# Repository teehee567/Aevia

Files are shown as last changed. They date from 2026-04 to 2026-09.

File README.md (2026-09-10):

# Aevia

Aevia is a DIY, battery powered lap timer and track data logger. The current hardware is the V2 Mini, a compact board that combines multi-band GNSS, a 6-axis IMU, local storage, a display interface, physical controls, and wireless connectivity.

Uses very very high end sensors, UM980, SCH16T-K01

The goal is to build something in the same general space as a Garmin Catalyst, but at a lower cost and with more control over the hardware, raw data, and software. Recorded data should also remain useful outside the device, with export to proper desktop analysis tools.

## V2 Mini hardware

The V2 Mini is built around:

- `ESP32-S31-WROOM-3-N16R16V` as the main processor and radio
- `UM980` multi-band, multi-constellation GNSS receiver
- `SCH16T-K01-1` 6-axis accelerometer and gyroscope
- microSD storage over 4-bit SDIO
- a 24-pin SPI display interface for the Adafruit 4520
- four UI buttons and four RGB status LEDs
- native USB data and USB-C power
- a 1-cell battery charger, fuel gauge, and push-button power control

See [v2_mini_design.md](./v2_mini_design.md) for the block diagrams, power tree, fitted parts, and current one-off build estimate.

## Firmware and software plan

The [base firmware](./firmware/README.md) now provides structured hardware
bring-up and a button-free J6 USB flash runner. From `firmware/`, run
`cargo run --release --locked` to build, flash and verify the restart.

The immediate work is hardware bring-up and the basic firmware needed to read the GNSS and IMU, store sessions on the microSD card, and exercise the display and controls. The application backlog currently looks like this.

### High priority

- [ ] Delta T lap timing with colour coding
- [ ] Raw-data analysis that can support lap times reported to 0.001 seconds and show the limits of the hardware
- [ ] Export to Harry's LapTimer or another tool that accepts the recorded data

### Medium priority

- [ ] G-G diagram, with filtering suitable for noisy IMU output
- [ ] Automatic track detection
  - [ ] Track learning mode
  - [ ] Manual start and finish line setup
- [ ] Smart battery management
- [ ] Theoretical best lap time
- [ ] Automatic recording based on acceleration
- [ ] Sector splits for tracks that support them

### Low priority

- [ ] Configurable LED bar
- [ ] Customisable gauges
- [ ] Colour themes

### Stretch ideas

- [ ] CAN bus or OBD data logging for brake, throttle, and other vehicle data
- [ ] Bluetooth support through the ESP32
  - [ ] RTK corrections, with a target of roughly 50 Hz and centimetre-level positioning
  - [ ] Firmware updates over Bluetooth
- [ ] Action camera synchronisation

## Why the UM980

Of the modules considered, the UM980 is the best fit I found for raw GNSS quality at this price. It can output at 20 Hz while using multiple GNSS constellations. That matters in a car because an antenna inside the windscreen loses much of its view behind the metal roof. Combining GPS, GLONASS, Galileo, and BeiDou leaves more satellites available for each fix and can improve accuracy when the view of the sky is limited. A receiver advertised as "multi-GNSS" does not necessarily support its maximum update rate while using several constellations at once.

It also supports multiple frequency bands. A single-band receiver has a harder time separating a direct signal from one reflected by the car or nearby barriers. Comparing L1 with L2 or L5 gives the receiver more information for rejecting poor measurements.

The planned BT-T076 is a wide multi-band active helical antenna, although its sheet does not explicitly document every UM980 signal. Helical designs generally tolerate tilt and an uncertain ground plane better than conventional patches, but the BT-T076 datasheet does not publish the angular, per-band patterns needed to rank it against a particular patch. A correctly integrated patch that covers every required band may provide cleaner measurements in a fixed installation; many common patches are only L1 or depend on a specific ground plane. See [the GNSS antenna decision note](./gnss_antenna_design.md) for the mounting scenarios, electrical constraints, expected data effects, and A/B test plan.

The expected gain over a decent off-the-shelf logger is not enormous, and software quality will matter just as much as the receiver. For absolute lap-time proof, a track transponder still wins.

### Receivers considered

These figures are working notes from the module research and should be checked again before buying parts.

| Receiver | Notes |
|---|---|
| Unicore `UM980` | L1, L2/L5, and L6; multi-constellation; full RTK; 20 Hz with full multi-GNSS; about 50 Hz in RTK mode; roughly A$130 |
| u-blox `NEO-M9N` | L1-only; multi-constellation; 25 Hz with one constellation or 10 Hz with several; roughly A$20 |
| u-blox `NEO-M10S` | L1-only; multi-constellation; 25 Hz with one constellation or 10 Hz with several; roughly A$20 |
| u-blox `ZED-F9P` | L1 and L2; multi-constellation; full RTK; about 8 Hz with everything enabled or 20 Hz with a reduced configuration; roughly A$130 |
| Quectel `LC29H-DA/EA` | L1 and L5; multi-constellation; RTK on the EA variant; 10 Hz maximum |
| Septentrio `mosaic-X5` | All bands and constellations; the best raw quality in this comparison; capable of 100 Hz; more than A$1,000 |
| SkyTraq `PX1122R` | L1 and L2; multi-constellation RTK; apparently up to 20 Hz, although documentation and pricing were difficult to find |

The Dragy Pro was the only off-the-shelf product for which I could identify the receiver module. It uses a u-blox NEO-M10S and is listed in the research as 10 Hz with multiple constellations or 20 Hz with one. I have not found a module that clearly delivers 25 Hz, multi-GNSS, and 10 cm accuracy at the same time, so similar product claims are unlikely to be real.

The longer comparison is in [data/gps_module_research.md](./data/gps_module_research.md).
And raw GNSS modules specs are in [data/GNSS_research.xlsx](./data/GNSS_research.xlsx).

## Repository map

- [V2 Mini design notes](./v2_mini_design.md)
- [GNSS helix-versus-patch and dashboard placement analysis](./gnss_antenna_design.md)
- [V2 Mini KiCad project](./hardware/v2_mini_pcb/v2_mini.kicad_pro)
- [V2 Mini root schematic](./hardware/v2_mini_pcb/v2_mini.kicad_sch)
- [V2 Mini PCB layout](./hardware/v2_mini_pcb/v2_mini.kicad_pcb)
- [V2 Mini production BOM](./hardware/v2_mini_pcb/production/digikey_bom.csv)
- [GNSS module research](./data/gps_module_research.md)
- [V1 PCB files](./hardware/v1_pcb/)
- [Earlier full-size V2 design notes](./v2_design.md)

## Building it

I do not recommend this as a first electronics build. Several parts need reflow equipment or a capable hot-air setup, and a one off board involves a fair amount of tooling and rework cost. The V2 Mini estimate is about $500AUD for the PCB, stencil, parts, GNSS receiver, antenna, and battery.

## V1 archive

archive, old, bad

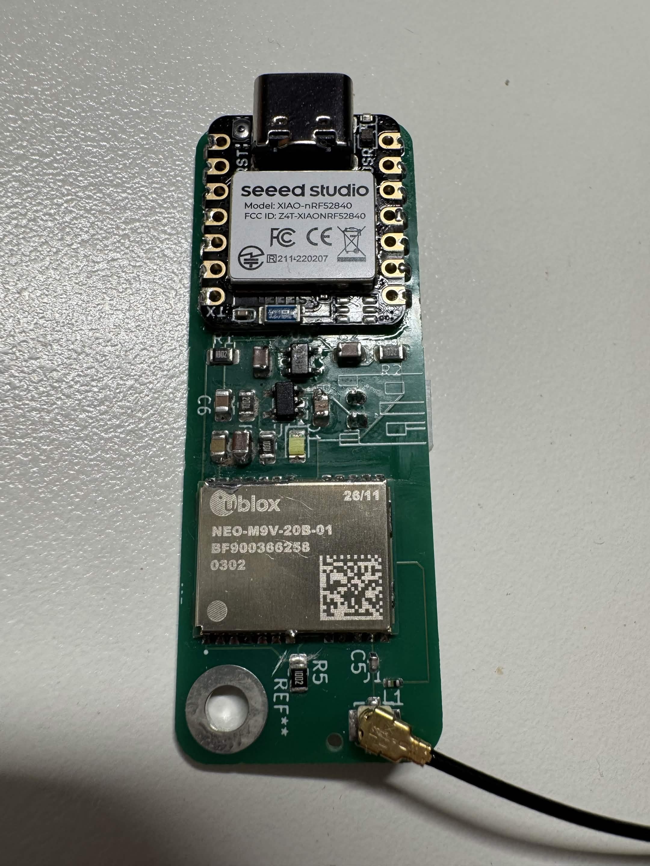
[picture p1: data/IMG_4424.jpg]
V1 assembled PCB


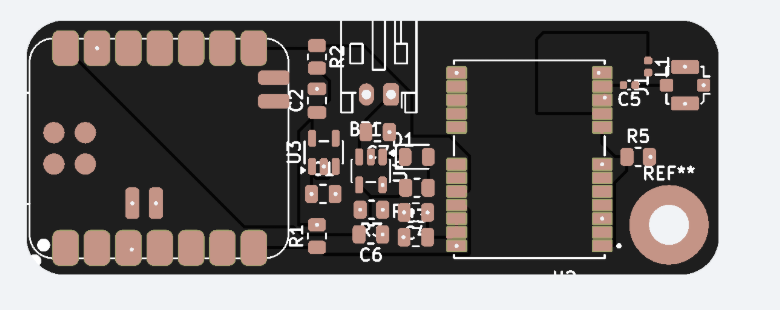
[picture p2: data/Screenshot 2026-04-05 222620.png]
V1 PCB design


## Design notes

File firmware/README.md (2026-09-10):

# V2 Mini base firmware

The default image brings up the ESP32-S31 V2 Mini's sensors, power bus,
buttons, display interface, PSRAM and USB console. Hardware ownership,
device protocols, background tasks and USB presentation are separate.
There is no trajectory engine or allocator in the base image.

## Build and flash

Use Rust **1.95.0**, target `riscv32imafc-unknown-none-elf`, and
**espflash 4.5.0**. The HAL revision and dependency graphs are pinned.
From `firmware/`:

```powershell
cargo build --release --locked
cargo run --release --locked
```

`cargo run` uses the Windows Cargo runner to flash over **J6**, without
BOOT/RESET button presses. From the repository root the equivalent is:

```powershell
powershell -NoProfile -ExecutionPolicy Bypass -File tools/flash-firmware.ps1
```

The script builds firmware and the host helper before touching the board.
The helper discovers the application (`303A:4001`), sends `BOOTLOADER`, waits
for ROM USB (`303A:0020`), flashes through the RAM stub, performs the S31
watchdog reset, then requires two advancing base-firmware status records.
It also accepts a board already in ROM download mode. The standalone helper
source lives in [tools/s31-reset](../tools/s31-reset); its original reset-only
command is retained.

Port numbers are discovered, not assumed. Optional `-AppPort COM5 -RomPort
COM4` arguments select known ports. Close other serial readers first and
connect only the board being flashed. J5 Serial/JTAG is a different transport.
Software entry requires responsive application USB; if both application and
ROM USB are absent, physical recovery is still necessary. A failed flash
leaves the board in download mode so the same command can be retried.

The ELF is `target/riscv32imafc-unknown-none-elf/release/aevia-firmware`
relative to the repository root.

## Source layout

| Location | Responsibility |
| --- | --- |
| `src/main.rs` | Entry point and image descriptor |
| `src/board.rs` | Frozen board pins, bus configuration, safe initial output levels |
| `src/app.rs` | Task composition and core ownership |
| `src/drivers/` | SCH16T, UM980, ST7789, LP5813 and TCA9536 I/O |
| `src/tasks/` | Sensor recovery, shared power-bus scheduling, shutdown and display lifecycle |
| `src/usb/` | USB descriptors, command dispatch, bounded writes and telemetry formatting |
| `src/state.rs` | Short snapshot locks and bounded capture queue |
| `src/lib.rs` | Host-testable command framing, GNSS/SafeSPI protocols, battery/button policies and memory checks |
| `experiments/` | Archived reference source; excluded from every base build |

See [system reference](docs/v2-mini-system-reference.md) for wiring, timing,
failure handling and extension constraints.

## USB console

Open the application COM port at 115200 with DTR enabled. USB sends a `STATUS`
line about once per second; sensor acquisition runs even with no host reader.
Status includes a protocol version, monotonic uptime, sensor counts, independent
GNSS fix validity, battery/LED/button state, LCD diagnostics, PSRAM test results
and cumulative capture/drop counters. `last-*-error` retains historical faults;
the current state and advancing error counters distinguish recovery from a
continuing fault. Battery readings expire after three seconds.

Commands are ASCII lines terminated with LF or CRLF. They work across USB
packet boundaries. Oversized or malformed lines are discarded; a bootloader
token embedded in another line cannot trigger a reset.

| Command | Result |
| --- | --- |
| `BOOTLOADER` | Immediately enter ROM download; independent of the telemetry writer |
| `STREAM 0123abcd` | Clear pending capture and reply `STREAM READY 0123abcd <time_us>`, then emit RAW records |
| `STOP` | Clear capture queue and acknowledge `STREAM STOPPED`; sensors/status keep running |
| `LCDREINIT` | Repeat panel initialization and DC check; SCLK probe requires reboot |
| `LCDTEST` | Enable the animated panel test pattern |
| `LCDLIGHT 0`, `1`, `5`, `10` | Backlight ceiling; 1/5 expire after five seconds, 10 stays on while panel initialization permits it |
| `GNSSBRIDGE` | Pause normal GNSS acquisition/configuration and bridge UM980 COM2 on the second USB serial interface |
| `GNSSNORMAL` | Restore COM2 baud and resume normal GNSS configuration/acquisition |

J6 now exposes two serial ports. Interface 0 is the console (currently COM5);
interface 2 is raw GNSS (currently COM6). The flash helper selects interface 0.
Bridge mode starts COM2 at 460800, 8N1 and follows the GNSS port's host baud
selection. It stays enabled across host disconnects until GNSSNORMAL or reboot.
Firmware telemetry and command parsing stay on the console port.

**Connected-board limitation:** receiver-to-host USB streaming is working;
direct receiver commands have not passed. GPIO49, assigned as COM2 RXD in the
schematic, was observed receiving COM2 output when released as an input.
COM1 replies on GPIO46 were absent. A wiring/assembly fault is suspected, not
confirmed. See [bridge findings and checks](docs/gnss-usb-bridge.md) before
treating this as a working two-way UPrecise connection.

Streaming is opt-in. Its nonce is exactly eight hexadecimal digits. A consumer
must discard bytes before its matching READY line. RAW formats are:

```text
RAW IMU <end_us> <interval_us> <ax> <ay> <az> <gx> <gy> <gz>
RAW GNSS <received_us> <original BESTNAVA line>
```

Acceleration is m/s², angular rate rad/s, timestamps MCU monotonic microseconds.
Frame lines across packets. The fixed 32-record queue drops new records on
overflow and increments `queue-drops`; producers never wait for USB. A blocked
writer has a 250 ms deadline and disables capture. Send a new STREAM request
to resume. This is a bring-up console, not a lossless recording transport.

## Verification

From the repository root:

```powershell
powershell -NoProfile -ExecutionPolicy Bypass -File tools/check-firmware-code.ps1
powershell -NoProfile -ExecutionPolicy Bypass -File tools/check-firmware.ps1
powershell -NoProfile -ExecutionPolicy Bypass -File tools/check-battery.ps1
powershell -NoProfile -ExecutionPolicy Bypass -File tools/check-psram.ps1
powershell -NoProfile -ExecutionPolicy Bypass -File tools/check-lcd.ps1
```

The code check runs host tests, strict Clippy for host and device, formatting
and the release build. The base hardware check requires a fresh stream
handshake, progressing GNSS/IMU counts, no new capture errors, the full 16 MiB
memory check and continued acquisition after STOP. Allow roughly 12 seconds
after power-on for receiver configuration before running it. Hardware checks
default to COM5 and accept `-Port`. A valid satellite fix and a working panel
are deliberately separate bring-up results.

Live verification on 2026-09-10 passed USB flashing and automatic restart from
both the former image and the rebuilt base image. After making power I2C
asynchronous, a 15-second check received 2,726 IMU intervals and 300 GNSS
records with zero capture errors and zero queue drops. The full 16 MiB PSRAM
test passed; the charger/gauge and green LED readback were valid; buttons
reported the unpressed mask. STOP preserved acquisition and status.

The connected LCD still reports `dc-stuck-low` (`lcd-dc=4`, expected 5).
Firmware leaves its backlight off and does not write frames into that fault.
Visible display output, physical button transitions, battery-only transitions,
SW7 shutdown and GNSS fixes need separate hardware checks. There was no
satellite fix during this run. GNSS timing is not PPS-disciplined and board
calibration is not implemented.

SD recording, wireless, lap timing and onboard fusion are future application
work. The old `host-poc`, `rtk-50hz`, and implicit onboard-estimator build modes
have been removed. Historical results remain in [trajectory notes](docs/trajectory-poc.md)
and [the preserved bring-up reference](docs/history/poc-system-reference.md).

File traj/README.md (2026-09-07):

# Aevia trajectory engine

`aevia-trajectory` is the shared trajectory and measurement engine for V2 Mini.
It has two processing paths:

- **Live:** bounded estimation on the S31 as measurements arrive. This is the
  default allocator-free, `no_std` build, selected by `ProcessingLevel::EmbeddedLive`.
- **Offline:** recorded-session replay and refinement on a computer or phone.
  Enable the `offline` Cargo feature and use `aevia_trajectory::offline`.
  `ProcessingLevel::OfflineSmooth` selects fixed-interval smoothing;
  `ProcessingLevel::CapturedReplay` reproduces the captured live processing.

Offline processing uses `OfflineResourceLimits` and returns an `OfflineRun`
with an `OfflineRunSummary`.

This directory contains only the core engine. Sensor drivers, protocol decoding,
clock/counter reconstruction, calibration application, channel selection,
resampling, recording codecs and physical I/O belong to external callers. The
former acquisition and log crates have been removed; nothing has been moved into
firmware.

The source is organized by responsibility. The public module paths remain the
entry points; their private submodules hold the implementations:

- `config/`: installation and calibration, numeric and navigation profiles,
  resource limits, qualification, and live/offline processing specifications.
- `engine/`: live session construction and ingestion, clock transitions,
  initialization, frontier processing, result digests, and offline/replay orchestration.
- `metric/`: definitions and plans, numerical algorithms, distance/event queries,
  uncertainty, and incremental activity, lap, and drag tracking.
- `trajectory/`: dense interpolation, conditional covariance bridges, storage and
  record encoding, public queries, and metric root/derivative calculations.
- `offline/solver/`: evidence validation, filter initialization and updates,
  propagation, smoothing, uncertainty projection, and result publication.
- `live/core/` and `live/eskf/`: live scheduling and ingestion, navigation
  propagation, GNSS updates, bounded extended RTS smoothing, and covariance handling.

Regression tests live beside these responsibilities in separate test modules.
The host feature suite can be run with
`RUST_MIN_STACK=33554432 cargo test -p aevia-trajectory --features offline,raw-tight,gtsam-system`;
its fixed-capacity replay fixtures need a larger test-thread stack than Rust's
default. Test `gtsam-vendored` separately because the two GTSAM features are
mutually exclusive.

The engine accepts:

- `ImuObservation`: a calibrated angular-rate vector in rad/s and specific-force
  vector in m/s², both averaged over the same nonzero interval in the declared
  IMU measurement frame. Supply their effective timestamps, clock-model identity,
  sample support, full covariance (or a configured model), axis validity and
  generic `ImuStatus`. The constructor rejects misaligned vectors. Any channel
  substitution, range/temperature qualification and covariance adjustment must
  already be complete. `Degraded` is usable, `Unavailable` invokes gap handling,
  and `Initializing`/`Discontinuity` require navigation reinitialization.
- `GnssSolutionObservation`: prepared ECEF position and/or velocity with their
  own timestamps, frame/reference-point identities, uncertainty, optional cross
  covariance and explicit per-field `valid` flags. Invalid fields remain
  recordable and are excluded from fusion and initialization. Positioning mode
  (RTK fixed/float, PPP, standalone, etc.) is not an engine input; the caller
  supplies the appropriate uncertainty and receiver health/freshness diagnostics.
  The caller accounts for receiver latency in each field's effective timestamp.
  Velocity-method labels, DOP and satellite/signal counts belong in application
  diagnostics. No receiver message format is required.
- Configuration: input-rate limits (`InputProfileSpec`), installation rotation
  and antenna lever arm, residual calibration uncertainty, clock uncertainty,
  process/measurement noise and metric definitions. A supplied heading is
  optional; observability remains explicit when heading is unknown.

The Kalman filter, IMU integration, IMU–GNSS fusion, frame/lever-arm mathematics,
bias estimation, covariance propagation, live trajectory and metrics, and
computer-side smoothing remain inside this package. Outputs include continuous
position, velocity and orientation queries at a chosen reference point, supported
uncertainty, quality/provenance, derived metrics and typed unavailable results.
Offline callers supply prepared records through `EvidenceSource` and consume
results through `ResultSink`; these are semantic ports with no file-format
requirement. Frame transforms and timing validation are estimator mathematics,
not hardware input processing.

GNSS output quality reports `Healthy`, `Absent` or `Suspect`, independent of
positioning mode. Migrating callers must replace `solution_class` with `valid`
and remove the `rtk_state` constructor argument. Keep any desired receiver mode
labels in application diagnostics. Offline record readers map legacy accepted
mode tags to `Healthy`; new records use a distinct health tag, which older
readers reject rather than misreport as RTK fixed.
Captured-result digests also use the new tag: replay comparisons against old
mode-labelled output digests will differ and require regenerated captures.

Measurement covariance describes the uncertainty of the supplied interval
average, not a continuous noise density. Preserve shared clock/calibration
uncertainty separately instead of adding it independently to every sample.
Nonzero independent IMU timestamp jitter currently remains unfused in live processing and returns
`CapabilityUnavailable` in the offline solver. Neither implementation has the
required temporal sensitivity model. Do not conceal real jitter by setting it
to zero. Shared clock offset/drift uncertainty remains supported.

Offline smoothing retains the error of each interval-average IMU sample across
stored propagation edges, including observations inside its support. Dense
covariance carries navigation, calibration, bias and sample correlations into
interior and offset-point queries and metric uncertainty. Offset velocity
covariance uses finite-support angular-rate uncertainty; the returned
`angular_rate_uncertainty_support` identifies that averaging interval. It does
not assign an instantaneous variance to white gyro noise.

Gate survey uncertainty is explicit: exact, independent normal displacement,
or a shared three-dimensional survey parameter with navigation correlations.
A variance supplied without a correlation model remains unavailable for
correlated metric uncertainty. Offline missing support still needs explicit
reinitialization; unsupported uncertainty models continue to fail closed.

`FiniteGate::new` keeps its scalar-variance argument. Declare its correlation
model with `with_independent_survey()` or `with_shared_survey_parameter(id)`;
direct field access now uses `survey_uncertainty: GateSurveyUncertainty`.
The private offline trajectory record format is version 4 to retain the full
coupled process; resource preflight includes its larger records and bounded cache.

Live navigation uses the ESKF forward estimate plus an extended RTS backward
pass over a fixed 64-node window. Set `NavigationProfileSpec.smoothing_lag` to a
nonzero duration up to 100 ms to enable smoothing; zero retains the forward
comparison path. The lag is additional to `fusion_delay`. Present projections
continue to follow the forward predictor, while trajectory publication and
metric watermarks wait for smoothed endpoints. `finish()` flushes the shorter
remaining window through the last trusted IMU epoch. The backward pass preserves
the filter's fixed Schmidt calibration/clock means and covariances, including
shared IMU-sample and gap correlations; it does not perform nonlinear iteration
or jointly estimate the calibration parameters.

Moving startup needs two fresh, advancing GNSS position/velocity epochs and
valid current IMU support. It can start without a stillness prerequisite,
using a coarse tilt estimate and calibrated bias priors. Repeated or merely
extrapolated receiver epochs do not count as another fix. A supplied heading
remains optional; course over ground is not treated as body heading.
The existing stationary alignment path remains available.

The release firmware target is the `ESP32-S31-WROOM-3-N16R16V`. It runs the
bounded, fixed-capacity live ESKF/RTS and incremental metric path. Full-session
`f64` smoothing runs on a phone or workstation. `AdvancedGraph` and `RawTight`
remain reserved processing levels and return `CapabilityUnavailable`.
The `gtsam-system`, `gtsam-vendored`, and `raw-tight` Cargo features remain for
compatibility and enable `offline`; they do not provide a backend. The unused
private backend scaffolding has been removed.

The smoother uses the explicit `LiveResourceLimits::V2_MINI_RTS` development
contract with a 3 MiB PSRAM ceiling; the historical `V2_MINI_INITIAL` constant
retains its 1 MiB ceiling. Internal SRAM and stack ceilings remain 192 KiB and
32 KiB. Callers must supply the reported compiled workspace sizes and record
the new navigation profile/digest. New output timing and startup behavior
require captures from the new build for exact replay. See
[`live_smoothing_requirements.md`](../data/live_smoothing_requirements.md) for
the lifecycle, moving-start and qualification requirements.

The allocator-free core is cross-checked with
`riscv32imafc-unknown-none-elf`, the hardware-FPU target class used by the
ESP32-S31. That check does not replace the release firmware proof: the platform
adapter must statically place the two workspaces in internal SRAM and PSRAM,
pin the floating-point estimator task to an explicit high-performance core,
keep capture ISRs integer-only, and qualify the final ESP-IDF/ESP-HAL link map,
stack, timing, cache contention, and soak behavior on the fitted module.
Run `python3 traj/scripts/audit_s31_firmware_purity.py` from the repository root
for the repeatable generic-target dependency and linked-symbol gate.

`WorkQuota` is a nonzero corrected-frontier credit capped at `u16::MAX` per
call. It charges IMU-slice planning, propagation, delayed measurement updates,
RTS backward steps, and frontier/segment commits; it is not a whole-step
wall-clock budget.
Observation ingestion, bounded corrected-history transfer/reanchoring, metric
refresh, and present projection instead have compile-time capacity and loop
bounds. Their timing, together with interrupts, RTOS overhead, cache behavior,
and final-link effects, remains an exact-firmware hardware release gate.

Non-polynomial gate, speed-threshold, and speed-extremum roots use
`EnclosureNativeF64V1`: outward binary64 interval arithmetic through the full
rigid-point, noncommuting SO(3) bridge, and Bowring ellipsoid-normal expression
graphs. Pinned `fpmath` native elementary functions are expanded beyond their
documented error bounds. The production dependency closure is allocator-free;
software scalar adapters are test-only. Isolation retains fixed stack, depth,
root-count, and evaluation ceilings and fails closed on unresolved cells.
The native contract requires round-to-nearest, gradual underflow, and disabled
implicit contraction. Independent Decimal90 regression fixtures cover values
and derivatives; regenerate them with
`python3 traj/scripts/generate_root_enclosure_oracle.py`.

Live preflight still requires measured qualification for this exact backend,
numeric profile, target, toolchain, input envelope, MPFR and independent-oracle
corpora, target bit fixtures, zero oracle escapes, and resource ceilings.
Legacy Taylor-backend attestations cannot qualify the new graph. The host
regressions are not hardware or MPFR qualification evidence.

Distance absolute tolerance belongs to the complete measurement. Segments and
speed-sign subdivisions share that allowance by duration, and cumulative live
reports retain the error already consumed. Relative error is checked against
the complete reported distance, including cancellation in signed quantities;
exceeding the shared numerical-work budget remains a typed failure.

The public interface contains semantic observations, configuration, trajectory
queries, measurements, quality and provenance. Estimator state, matrices,
storage machinery and optional native backends remain private.

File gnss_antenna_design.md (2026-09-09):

# Aevia GNSS antenna decision: quadrifilar helix versus patch

- **Status:** design and validation note
- **Date:** 2026-08-17
- **Applies to:** Aevia V2 Mini, UM980, an antenna mounted inside the front windscreen
- **Decision confidence:** high on the installation principles; deliberately conditional on the exact replacement patch, windscreen construction, and measured vehicle geometry

**Hardware assumption:** the user reports that the installed antenna is helical, while the repository only identifies the BT-T076 as the *planned* helix. BT-specific values and connector conclusions in this note apply only if the label and datasheet revision confirm that the installed assembly is an authentic BT-T076. The current V2 Mini BOM does not identify an antenna or pigtail.

## Decision in one page

There is no topology-only answer in which every patch is better than every helix, or vice versa. For Aevia, orientation and installation can be worth substantially more than the small difference between two headline peak-gain numbers.

There are two different decisions: what is safe to deploy now, and which configuration has the highest ceiling after qualification. The recommended order is:

1. **Best absolute result:** a documented, full-band active GNSS antenna mounted externally near the centre of the metal roof, using the ground plane and mounting method required by its manufacturer.
2. **Safe interior baseline now:** retain the installed helix and test it first with its axis vertical. It needs no newly engineered patch plane and is the lower-risk choice while the exact patch, vehicle mask, and installed helix identity remain unknown.
3. **Highest-potential interior prototype:** a high-quality active patch that covers every signal Aevia intends to use, on the exact ground plane or integrated base for which it was characterised. Start with its face horizontal, then test 15°, 30°, and the measured glass-normal angle. Horizontal is the conventional patch baseline, but a forward tilt can win if it aligns the lobe with the car's actual clear windscreen aperture. It must accept the V2 Mini's 3.3 V bias and be compatible with the UM980 manual's stated 18–36 dB *optimum input-gain* window after the gain reference is clarified with Unicore.
4. **Do not choose from topology or tilt alone:** a large glass-normal tilt is risky for a directional patch because it sacrifices other sky sectors, but it is not automatically wrong. The installed antenna-plus-vehicle pattern, not the free-space antenna pattern alone, decides the result.

For the two requested comparisons:

| Installation | Helix | Patch | Decision today |
|---|---|---|---|
| Front of dash; boresight normal to the windscreen | Its broader angular response makes it the lower-risk unmeasured choice at a large tilt. It still points away from zenith and its installed pattern is unknown. | It may lose zenith/side/rear gain, or it may benefit by concentrating gain into the only clean forward-glass aperture. Glass-normal mounting does **not** reduce glass loss for a fixed satellite ray. | **Keep the helix as the safe baseline; no guaranteed RF winner.** Test this patch orientation rather than rejecting it if the forward aperture dominates. |
| Same dash location; boresight straight up | Good, robust baseline when a defined patch plane cannot be supplied. It may admit more reflected energy and may have less direct-signal gain than a properly installed quality patch. | Conventional baseline geometry. A high-quality patch on its specified plane is the preferred upgrade candidate for cleaner code/carrier and more stable phase-centre behaviour. | **Keep the helix now; select the patch only if installed tests show a downstream data-quality win.** |

The conditional language is intentional. The exact improvement cannot be stated from the present component data. The BT-T076 sheet gives one generic `3 dBi` gain number and `≤3 dB` axial ratio, but no gain or axial-ratio plots by frequency and direction. No replacement patch has been selected, and the windscreen rake and coating are unknown. A switch based only on advertised peak gain would therefore be guesswork.

## 1. What is actually in Aevia

The [V2 Mini design note](./v2_mini_design.md), schematic/PCB and README identify the current receiver as the **Unicore UM980** and the planned antenna as the **Beitian BT-T076**. The current V2 Mini has a U.FL antenna connector, an RF path designed and routed as a short 50 Ω connection, and a 3.3 V bias tee that is energised whenever the GNSS rail is powered. There is no production RF-impedance measurement in the repository. The current firmware is only a scaffold (`Hello, world!`), so there is not yet any Aevia observation log with which to compare antennas.

The [UM980 product page](https://en.unicorecomm.com/products/um980/) and the [R1.9 user manual stored in this repository](./data/datasheets/UM980_User%20Manual_EN_R1.9.pdf) specify reception of:

- GPS L1 C/A, L1C, L2P(Y), L2C and L5;
- BeiDou B1I, B2I, B3I, B1C, B2a and B2b;
- GLONASS G1, G2 and G3;
- Galileo E1, E5a, E5b and E6;
- QZSS L1 C/A, L1C, L2C, L5 and L6; and
- NavIC L5.

The manual gives 1.5 m horizontal and 2.5 m vertical RMS standalone positioning, 0.8 cm + 1 ppm horizontal and 1.5 cm + 1 ppm vertical RTK, 0.03 m/s velocity RMS, and up to 50 Hz RTK in a specific mode. It does not establish that all constellations, raw observations, and diagnostics can be output together at 50 Hz. Those are receiver test figures, not promises for a windscreen installation. Unicore explicitly makes performance dependent on satellite visibility and geometry, multipath, and antenna quality. Its table calls **18 dB minimum, 30 dB typical, and 36 dB maximum** the *optimum input gain*; it does not define those figures as absolute operating or damage limits.

The [BT-T076 manufacturer's page and datasheet images](https://www.beitian.com/en/sys-pd/620.html), revision 5.53 dated 2024-12, claim:

| Item | BT-T076 published value |
|---|---|
| Bands | GPS L1/L2/L5; GLONASS L1/L2; Galileo E1/E5a/E5b; BeiDou B1/B2/B3; QZSS L1/L2/L5/L6; NavIC L5; SBAS L1/L5. Galileo E6 and GLONASS G3 are not explicitly listed. E6 is close in frequency to QZSS L6, but coverage, group delay and performance must not be inferred from frequency overlap alone. |
| Polarisation | RHCP |
| Passive antenna gain | `3 dBi` (one value; no band, angle, reference plane, or uncertainty stated) |
| Axial ratio | `≤3 dB` (no angle or band stated) |
| VSWR | `≤2` |
| LNA gain / noise figure | `32 ±2 dB` / `≤2 dB` |
| Supply / current | 3.3–5.0 V / ≤55 mA |
| Phase-centre error | ±2 mm claimed |
| Connector and size | SMA-J; 43.5 mm diameter × 40.8 mm; ≤35 g |
| Missing information | 3-D RHCP and LHCP patterns; gain and axial ratio versus elevation/azimuth and band; mounting/ground-plane test condition; filter rejection and linearity; unit-to-unit tolerance by band |

This is enough to regard the BT-T076 as a plausible low-cost active wide-band helix. It is not enough to claim support or characterised performance for every UM980 signal, model installed signal quality, or prove the README's previous claim that it has lower peak gain but better low-elevation coverage than a patch. That pattern claim is a reasonable generic tendency, not a verified BT-T076 comparison.

## 2. Definitions that prevent an orientation mistake

- A **patch face** is its broad radiating ceramic/metal face. Its intended boresight is the line normal to that face. A horizontal face points vertically upward.
- A **helix axis** is the long symmetry axis through the quadrifilar helix. For this note, that axis is treated as its nominal boresight.
- Let **α** be the boresight tilt away from local vertical, toward the front of the vehicle. `α = 0°` means straight up. A windscreen-normal installation has `α` equal to the angle between the inward/outward windscreen normal and vertical; this must be measured on the actual car.
- “The helix lies flat on the dash and points up” means its base/support is on the dash and its **axis is vertical**. If the cylindrical helix is literally placed on its side, its axis is horizontal; that is a different and generally poor configuration.

For a satellite at elevation `e` and azimuth offset `φ` from the vehicle's forward direction, the off-boresight angle `θ` is

```text
cos(θ) = sin(e) cos(α) + cos(e) sin(α) cos(φ)
```

This simple geometry explains the difference between the two proposed installations. With `α = 0°`, `θ = 90° − e` for every azimuth: a nominally symmetric antenna is insensitive to yaw. With an illustrative, not assumed, windscreen-normal tilt of `α = 60°`:

| Satellite direction | Off-boresight angle `θ` |
|---|---:|
| 30° elevation, directly ahead | 0° |
| 30° elevation, directly to the side | 75.5° |
| 30° elevation, directly behind | 120° (behind the antenna) |
| Zenith | 60° |

At this illustrative 60° tilt, the antenna boresight favours one forward sector and places zenith, side, and rear directions far off-axis. That geometric fact does not supply the missing dB pattern, nor does it prove that the directions are usable or blocked in the car. As the car turns, the antenna lobe and the vehicle's forward-glass aperture rotate together while the satellites remain in Earth-referenced directions. Alignment between those two patterns can improve or worsen the combined result.

It is useful to separate two effects. A tilted directional antenna introduces **free-space antenna yaw sensitivity**; a horizontal, azimuth-symmetric antenna does not. But every **installed antenna-plus-vehicle pattern** is heading-dependent because the roof, pillars, glass aperture/coating, occupants and reflections also rotate relative to the satellites. A horizontal patch is only nominally yaw-symmetric before those vehicle effects. Heading-dependent C/N0 must therefore be measured, not assigned from orientation alone.

Measure `α` directly rather than relying on an ambiguous “windscreen rake” number. For example, glass described as 30° back from vertical has a normal about 60° from vertical, matching the table above. If the proposed bracket is actually only 30° from vertical, zenith is only 30° off-axis and the penalty is much milder; the same forward/rear and heading trade remains.

At `α = 30°`, a satellite at 45° elevation directly ahead is only 15° off-boresight rather than 45° for a vertical boresight, and one at 20° elevation ahead is 40° rather than 70°. The corresponding rear directions become worse. That may be a good exchange if the roof has already blocked the rear sky and the forward glass is the clean aperture; only the candidate's pattern and the installed sky mask can convert these angles into a dB or data-quality answer.

One further distinction is essential: **tilting an antenna at the same location changes the antenna pattern seen by the satellite; it does not change the physical satellite ray or that ray's angle through the glass.** Glass incidence is set by the satellite direction and windscreen plane. Pointing a patch or helix normal to the glass can align its boresight with a forward ray, but it does not make every ray traverse less glass or evade a metallic coating.

## 3. Why patch and helix behave differently

### 3.1 Radiation pattern and useful gain

GNSS satellites transmit right-hand circularly polarised (RHCP) signals. An antenna's useful figure is therefore not total LNA gain or a single peak dBi number. It is installed **RHCP realised gain as a function of frequency, elevation, and azimuth**, including mismatch and material losses.

A conventional patch concentrates response in the hemisphere above its face. It normally has maximum RHCP gain near its normal and rolls off toward the plane/horizon, with a ground-plane-dependent back lobe. ESA's [Navipedia antenna reference](https://gssc.esa.int/navipedia/index.php?title=Antennas) describes typical patch coverage of about 160° and notes that real GNSS antennas can lose roughly 10–20 dB from zenith to the horizon while axial ratio also deteriorates off-axis. These are generic orders of magnitude, not a prediction for an unspecified Aevia patch.

A quadrifilar helix is commonly designed for a smoother hemispherical response and is more tolerant of varying orientation. It is not isotropic, and “360° horizontal coverage” does not define its elevation pattern. The [u-blox GNSS antenna integration note](https://content.u-blox.com/sites/default/files/products/documents/GNSS-Antennas_AppNote_%28UBX-15030289%29.pdf) says that a reasonably sized helix will typically have less sensitivity than a comparably practical patch because comparable direct gain needs comparable aperture. The same note cautions that a helix can report more satellites in a difficult environment because its broad pattern also accepts reflections; those extra observations can have distorted ranges and worsen navigation.

Consequences for Aevia:

- A flat, properly integrated patch tends to maximise direct high-elevation signals and suppress energy from below or behind. This is attractive for low-multipath code, carrier phase, and RTK.
- A helix tends to give up some concentration for angular tolerance. This is attractive when the mount is tilted, the device rolls/pitches substantially, or no stable patch ground plane exists.
- More tracked satellites is not by itself a win. Fourteen clean, well-distributed direct signals can outperform twenty signals that include strong reflected paths.
- Small vehicle pitch and roll are usually far less severe than a 50–65° windscreen-normal tilt. They remain worth logging, but neither those motions nor free-space geometry alone determines the best installed angle.

### 3.2 Polarisation and axial ratio

An ideal GNSS antenna receives RHCP direct signals and rejects opposite-hand energy. A spec called **axial ratio (AR)** measures how close the polarisation is to circular: 0 dB is ideal; 3 dB is only the usual edge of a broad “circular” classification. Reflections can partially or fully reverse handedness, so low AR and low LHCP gain help reject multipath.

For an idealised elliptically polarised antenna at one direction, let `r = 10^(AR/20)`. Its ideal co-polar to cross-polar discrimination is

```text
XPD = 20 log10((r + 1) / (r − 1))
```

Thus 3 dB AR corresponds to about 15.3 dB ideal RHCP/LHCP discrimination, 1 dB to about 24.8 dB, and 0.5 dB to about 30.8 dB. The direct-signal mismatch at 3 dB AR is only about 0.13 dB; the larger concern is poorer rejection of the wrong handedness. These calculations are ideal values at a specified angle. A datasheet's one zenith AR number says little about the horizon, other bands, or the installed vehicle.

The BT-T076's `≤3 dB` claim is therefore adequate but not survey-grade evidence. A good replacement patch or helix should provide AR and RHCP/LHCP patterns over angle and frequency, not merely a checkbox saying RHCP.

### 3.3 Ground plane, phase centre, and nearby material

Patch performance depends on its RF ground plane. The u-blox integration note shows that ground-plane size, shape, symmetry, and patch placement can change gain, axial ratio, impedance match, resonance, directivity, and the back lobe. It gives 50 × 50 to 70 × 70 mm as a useful generic allowance for common L1 patches, but that is not a universal full-band prescription. Full-band stacked patches can require a larger, candidate-specific plane; for example, the representative Taoglas part discussed below is characterised on a 150 mm diameter plane.

A plastic dashboard above the vehicle's metalwork is **not automatically the documented RF ground plane**. Distance, electrical bonding, shape, and nearby displays/PCB/cables all matter. A random steel plate can also make a patch worse if its dimensions differ from the design condition. Follow the selected antenna's drawing and verify the installed match/pattern.

Helices are often designed without a ground plane, but this too is part-specific. u-blox reports that an intentional plane can improve some helix implementations by 2–3 dB, while metal within roughly 5 mm of a free-space helix's radiating section can distort its near field and pattern. The BT-T076 sheet does not state its test condition, so neither adding nor removing metal should be assumed beneficial.

Nearby glass, a radome, adhesive, the dash, display, PCB, cable, a person's hand, and vehicle metal change the near field. This can shift resonance and alter both the far-field pattern and phase centre. There is no reliable correction from dimensions alone; the choices are electromagnetic simulation and installed measurement.

For standalone metre-level use, a few millimetres of phase-centre variation may be unimportant. For RTK and IMU fusion, it matters. The antenna must also be rigidly mounted and its lever arm to the vehicle/IMU reference point measured. Body roll rotates that lever arm, and an unmodelled position offset can appear as a trajectory error even when the receiver solution itself is good.

## 4. The two requested mounting scenarios

### Scenario A: both boresights normal to the windscreen

Assumption: the helix axis and patch normal point outward perpendicular to the glass at the same front-dash location. The patch face is therefore approximately parallel to the glass. A fair orientation comparison must keep the antenna phase-centre xyz position, cable route, ground plane/base, enclosure and nearby hardware fixed as far as mechanically possible; moving them changes masking and multipath independently of angle.

**Helix:** This is a use case in which the topology's usually broader pattern is valuable. Compared with a conventional directional patch at the same large `α`, a well-designed helix may retain more usable gain toward zenith, side sectors, and some rearward directions. The price can be lower direct-signal gain and greater acceptance of dashboard, bonnet, glass, barrier, and ground reflections. There is no BT-T076 angular data or selected-patch pattern to say which is ahead, or whether the difference is 1 dB or 10 dB, in any particular direction.

**Patch:** This is the riskier unmeasured orientation when `α` is large. The forward low/mid-elevation sector may be strong, but zenith is `α` degrees off-axis, satellites beside the car are far off-axis, and much of the rear sky can enter through the patch's weak back hemisphere. On the other hand, the roof may already obscure the rear sky, so concentrating gain into the forward glass can be beneficial. The direction and magnitude of the trade depend on the installed sky mask, beamwidth, off-axis axial ratio, and the satellite geometry around the complete route.

There is one important exception: if an installed sky-mask survey shows that nearly all clean, usable sky is through a narrow forward windscreen sector while zenith and the sides are already blocked, aiming a directional patch into that aperture can outperform a vertical patch for those rays. It still must beat the vertical and intermediate-angle configurations over complete laps, because the favoured satellite azimuth changes with vehicle heading.

An automotive L1 experiment by Aloi et al., [“A detailed experimental study on the benefits of electrically grounding glass mounted GPS antennas to the vehicle roof”](https://doi.org/10.1049/iet-map.2013.0616), measured a 25 × 25 × 4 mm patch on a vehicle-roof mock-up at 45°, 60°, and 75° windscreen angles. It found that the roof distance, grounding arrangement, glass loading, and tilt all changed patterns; the roof-centre reference had about 5 dBc peak gain. The reported differences included roughly 1.5 dB trends from tilt and about 2.5 dB at some median pattern points from roof proximity/grounding. This is direct evidence that vehicle installation can move results by several dB, but it is **not transferable as a correction**: it was a tuned L1-only patch near the roofline, not an unspecified full-band patch on Aevia's lower dash.

**Verdict:** if constrained to a large glass-normal tilt before any measurement, the helix is the lower-risk baseline because it is less dependent on a newly designed plane and is likely broader. That is an integration-risk recommendation, not proof of better RF data. Sweep `α = 0°, 15°, 30°`, and the measured glass-normal angle for both complete assemblies. A modest or full forward cant may win if it matches the real aperture; it must demonstrate that win over complete laps and multiple satellite geometries.

### Scenario B: both boresights straight up from the dash

Assumption: patch face horizontal; helix axis vertical; the same phase-centre position, cable route and surrounding hardware as far as the different assemblies permit.

**Helix:** This puts its intended main region on the sky and removes deliberate free-space forward/rear asymmetry. It is the safest configuration for the existing antenna when no validated patch assembly is available. Its broad lower-elevation response may retain signals through the front and side glass, but can also accept more reflected energy. The installed vehicle pattern remains heading-dependent.

**Patch:** This is the correct baseline orientation for a conventional GNSS patch. If it covers all required bands, uses a good dual-feed RHCP design, and sits on its specified plane, it may provide stronger/cleaner high-elevation observations and better rejection of below-plane multipath than the current undocumented helix. That could help raw code and phase quality, ambiguity continuity, and repeatability. A high-quality helix can still outperform a mediocre patch, and a bare patch sitting on plastic with the wrong plane can be detuned enough to erase or reverse the expected advantage.

**Verdict:** a documented quality patch is the preferred upgrade candidate for raw-observation purity and RTK in this scenario, **not a guaranteed winner**. Until a specific patch passes the electrical and installed tests below, the current vertical helix is the lower-risk deployment choice.

### Scenario comparison

| Consideration | Tilted helix | Tilted patch | Vertical helix | Horizontal-face patch |
|---|---|---|---|---|
| High-elevation/zenith use | Conditional; zenith off-axis | Usually poor at large `α` | Intended geometry | Intended geometry; often strongest |
| Forward low-elevation sky | Favoured | Strongly favoured | Off-axis but usually usable | Off-axis; often downweighted anyway |
| Rear/side sky | Often smoother than a directional patch; unknown here | Can be weak/backside | Free-space azimuth balance is plausible | Free-space azimuth balance if the plane is symmetric |
| Added antenna-pattern yaw sensitivity | Moderate at a large tilt | Potentially high | Low if its free-space pattern is symmetric | Low if antenna/plane are symmetric; vehicle yaw effects remain |
| Multipath rejection | Candidate-specific; broad response can admit more | Directional, but useful alignment is installation-specific | Candidate-specific; broad response can admit more | Potentially best with a proper plane and low off-axis AR |
| Need for defined ground plane | Often lower, part-specific | High | Often lower, part-specific | High |
| RTK/raw phase potential | Must be measured | Must be measured against the aperture | Plausible baseline | Highest conventional-patch potential, still candidate-specific |
| Recommendation | Lower-risk of the unmeasured large-tilt choices | Test if it aligns with the real aperture | Keep as deployment baseline | Preferred upgrade candidate to qualify |

## 5. “How much better?” — what can and cannot be quantified

A 3 dB change is a factor of two in received power. In a stable, unsaturated front end, a 3 dB change in installed passive antenna gain or pre-LNA loss will appear approximately as a 3 dB-Hz C/N0 change for that ray. It does **not** mean twice the position accuracy. Position error depends on geometry, correlation/noise, multipath bias, receiver weighting, frequency availability, and whether tracking or RTK ambiguity thresholds are crossed.

For scale, the following is the *best-case thermal-noise-only* interpretation. The last column is the ideal measurement standard-deviation multiplier if every other error source is unchanged; real GNSS positioning often improves less because multipath, satellite geometry, atmosphere, phase-centre variation, and receiver weighting dominate.

| C/N0 improvement | Carrier/noise power ratio | Ideal noise-limited standard deviation |
|---:|---:|---:|
| 1 dB | 1.26× | 0.89×, about 11% lower |
| 2 dB | 1.58× | 0.79×, about 21% lower |
| 3 dB | 2.00× | 0.71×, about 29% lower |
| 6 dB | 3.98× | 0.50×, about 50% lower |

The following published magnitudes set the scale; they are examples from different antennas and test setups, not transferable Aevia prediction bounds:

| Mechanism/evidence | Magnitude | Meaning and limit |
|---|---:|---|
| Generic real GNSS antenna roll-off, zenith to horizon | about 10–20 dB | [ESA's reference](https://gssc.esa.int/navipedia/index.php?title=Antennas) gives this as a common range. A large tilt can move a satellite across much of that pattern, but no BT/candidate plot means no installed prediction. |
| Ground plane added to some helix designs | about +2–3 dB | Generic u-blox integration example, not a BT-T076 guarantee; a too-close/wrong plane can degrade it. |
| Experimental L1 windscreen patch installation changes | order 1.5–2.5 dB in reported comparisons | Aloi et al.; specific antenna, roof distance, tilt, and grounding. Shows “several dB” installation sensitivity, not a reusable Aevia number. |
| Ordinary 6–19 mm architectural glass examples at GPS L1 | about 1–4 dB | Broad literature examples summarised by [Liu et al.](https://link.springer.com/article/10.1186/s43020-020-00013-z), not direct measurements in Aevia or an automotive-windscreen specification; laminate, angle, frequency and setup differ. |
| Coated/energy-efficient glass examples | about 10–30 dB | Broad literature examples summarised by Liu et al., with construction and setup varying. They show that conductive coating can dominate; measure the actual vehicle. |
| 34 mm high-speed-train glazing experiment | up to 20 dB-Hz loss in surviving signals; 65% fewer tracked satellites | [Liu et al.](https://link.springer.com/article/10.1186/s43020-020-00013-z) also observed many more cycle slips and metre-level PPP degradation. This is a severe-glass case, **not a car prediction**. |
| Survey-grade patch versus two quality multi-frequency QHAs, 10–30° elevation | QHA code noise/multipath RMS about 30% and 70% higher; phase/high-frequency multipath about 40% and 70% higher | [Wanninger et al.](https://doi.org/10.1515/jag-2021-0042), static survey setup. It demonstrates that antenna quality changes observables, not that BT will match either QHA. |
| Same survey study, 5-minute fast-static coordinates | horizontal accuracy broadly similar/sub-centimetre; vertical RMS 0.80/0.93 cm patch, 1.02/1.51 cm one QHA, 2.08/2.50 cm the other | Raw observables can be 30–70% noisier while final horizontal results remain similar; vertical worsened about 1.3–2.7× in those tests. Dynamic windscreen results may differ completely. |

The most important conclusion from these examples is scale: headline peak differences between plausible candidate datasheets may be only a few dB, while orientation, an incorrect patch ground plane, a deep pattern null, or metallised glass can cost ten or more dB in affected rays. Those large effects can decide lock and ambiguity continuity; a one-number “3 dBi versus 4 dBi” comparison cannot.

One representative full-band active patch makes the comparison problem visible. The [Taoglas ADFGP.60A datasheet](https://www.taoglas.com/datasheets/ADFGP.60A.01.0150D.pdf) reports, on a 150 mm diameter ground plane, passive peak gain from approximately −0.3 dBi at L6/E6 to 4.4 dBi at L1, axial ratio roughly 0.25–1.25 dB by band, and total gain about 26–30 dB. This wide per-band variation shows why a patch cannot be represented by one peak-gain number. The BT sheet's single undifferentiated `3 dBi` claim has no band-specific value, angular definition, or stated test plane, so no numerical BT-versus-Taoglas subtraction is valid.

Likewise, a well-documented helix can be much better characterised than the current one. The [Calian HC990XF datasheet](https://sites.calian.com/app/uploads/sites/13/2024/06/Calian%C2%AE-HC990XF-Datasheet-Rev.-202304.pdf) specifies band-by-band gain around 1.8–2.3 dBic, ≤0.5 dB zenith AR, ±3 mm phase-centre variation, filtering, and no ground-plane requirement. Its lower headline gain than BT's generic 3 dBi does not make it lower quality. Pattern, polarisation purity, filtering, phase stability, and test disclosure matter.

## 6. How the antenna changes Aevia's result data

The antenna can improve the measurements available to the UM980; it cannot change the receiver's nominal update rate, correct bad timestamps, or make three decimal places in a lap time accurate by itself.

The causal chain is:

```text
installed antenna gain / polarisation / multipath / interference
        ↓
per-signal C/N0, tracking continuity, code and carrier residuals
        ↓
usable bands and satellites, geometry, cycle slips, RTK ambiguity state
        ↓
position and velocity error, solution availability and latency
        ↓
virtual-line crossing time and lap/sector repeatability
```

### Observable-level effects

- **C/N0:** better installed passive gain and lower pre-LNA loss raise C/N0 approximately dB-for-dB until receiver compression/interference effects intervene. More LNA gain alone amplifies signal and antenna noise together; it cannot recover SNR lost before the LNA.
- **Pseudorange/code:** stronger direct signals reduce thermal/code tracking jitter, while reflected signals introduce biased ranges that do not average like white noise. A broad helix can therefore show more satellites yet worse code residuals.
- **Carrier phase and lock:** good C/N0 and favourable tracking-loop/interference conditions reduce thermal phase noise and loss of lock. A low-quality signal can cycle-slip; RTK then has to repair or re-resolve ambiguities, creating fixed-to-float transitions and discontinuities.
- **Phase centre:** offset and variation create direction-, attitude-, frequency-, and mounting-dependent systematic phase/position bias. Stable, characterised phase-centre behaviour helps RTK consistency and lever-arm calibration, but it does not directly prevent cycle slips.
- **Multi-frequency availability:** an L1-only or weak-L5/L6 patch throws away part of the UM980's central advantage. The replacement must be evaluated per signal and per band.
- **Geometry:** a tilted directional pattern can eliminate useful side/rear/high-elevation signals, worsen DOP, and make quality vary with heading. Satellite count alone does not capture this.
- **Interference:** a high-gain but poorly filtered active antenna can overload its own LNA or the receiver near cellular, Wi-Fi, display, USB, SD, and switch-mode noise. The u-blox note explains that GNSS power is below the thermal-noise floor and that both in-band noise and strong out-of-band transmitters can drive receiver AGC/desensitisation.

### Position error to lap-time error

For a virtual timing line with unit normal `n`, position error `δr`, and vehicle velocity `v`, the first-order crossing-time error is

```text
δt_position ≈ (n · δr) / (n · v)
```

For a timing line approximately perpendicular to the racing line, this reduces to along-track position error divided by speed. Illustrative values are:

| Speed | 1.0 m along-track error | 0.10 m | 0.01 m | Distance travelled in 1 ms |
|---:|---:|---:|---:|---:|
| 60 km/h | 60 ms | 6.0 ms | 0.60 ms | 1.67 cm |
| 100 km/h | 36 ms | 3.6 ms | 0.36 ms | 2.78 cm |
| 200 km/h | 18 ms | 1.8 ms | 0.18 ms | 5.56 cm |

This is only the spatial term. Total lap-crossing error also includes GNSS time/message latency, PPS alignment, receiver dynamics, sample interpolation, start-line definition, antenna/IMU lever arm, body attitude, filtering, and software. At 20 Hz, epochs are 50 ms apart; interpolation can remove raw sample quantisation, but only if timestamps, velocity/trajectory modelling, and adjacent fixes are reliable. Reporting `0.001 s` is not evidence of 1 ms accuracy. At 100 km/h, 1 ms alone corresponds to just 2.8 cm along the track, considerably below the UM980's nominal standalone RMS and plausible only with a stable high-quality solution plus careful timing/processing.

A better antenna will most visibly improve **availability and tails**, not necessarily the average lap: fewer C/N0 collapses, fewer discarded signals and cycle slips, longer RTK-fixed intervals, smaller 95th/99th-percentile position excursions, and less heading-correlated lap-to-lap error. A patch could yield cleaner raw data yet similar final horizontal positions, as the Wanninger study illustrates. Conversely, crossing a tracking or RTK threshold can produce a step change much larger than the dB improvement suggests.

## 7. Antenna assembly types are not interchangeable

“Patch” can mean several electrically different products:

1. **Bare passive ceramic patch.** This is only the radiating element, perhaps with matching. It normally needs a carefully designed host ground plane, a short 50 Ω feed, matching/ESD work, and often a nearby LNA. Cable loss before the first LNA directly degrades system noise figure. It is not a plug-in substitute for an active SMA antenna.
2. **Active patch module.** This adds an LNA and usually filtering. It may have a small metal backplate but can still require a larger specified external ground plane. “Active” does not mean “ground-plane independent.” Read the characterisation condition.
3. **Active patch with an integrated, sufficient ground plane/base.** A larger enclosed assembly can control its own RF geometry. This is the most plausible interior patch upgrade if it is explicitly characterised freestanding or with its supplied plane.
4. **Roof-intended magnetic puck.** Its magnetic metal base and the vehicle roof may be part of the RF design. A puck specified “on a 100 mm ground plane” or “vehicle roof mount” should not be assumed to work the same on a plastic dashboard. A product explicitly specified ground-plane independent is different.
5. **Survey/geodetic antenna.** These often use stacked dual-feed patches, choke structures, stable phase centres, strong filtering, a large enclosure, and calibration. They can give the cleanest phase data but may be too large, expensive, or roof-dependent for Aevia.

Whenever `+3V3_GNSS` is powered, that rail feeds the U.FL centre conductor through a 68 nH inductor. It is the same filtered rail that powers the UM980. The existing 100 pF capacitor blocks DC only between the biased RF node and the UM980 `ANT_IN` pin; it does **not** remove DC from U.FL J1. The UM980 `ANT_DETECT`, `ANT_OFF`, `ANT_SHORT_N`, and `VCC_RF` pins are unconnected, so the present PCB has no firmware-controlled antenna enable, open/short indication, or antenna-current measurement. The UM980 manual recommends a separately protected `ANT_BIAS` supply for robustness, whereas V2 Mini shares the receiver rail.

A passive patch is therefore not automatically drop-in. Verify its DC input before connection: a candidate that is a DC short could pull down the shared GNSS rail through the bias inductor. If it is incompatible, depopulate the bias-feed inductor or add a deliberate DC block/bias-isolation or switching design. An active candidate must operate at the voltage that actually reaches it under load. If the installed helix is confirmed as a BT-T076, its stated 3.3–5.0 V range puts V2 Mini at its lower limit; measure voltage and current externally at the antenna end across battery, temperature, cable, and tolerance rather than accepting the rail label.

Keep three gain questions separate for an active assembly:

- **Satellite link and C/N0:** installed passive RHCP realised gain versus band and direction, plus pre-LNA loss and polarisation/multipath effects.
- **Noise figure and receiver drive:** antenna-LNA/filter gain and noise figure, followed by cable/adapter loss. Evaluate this with the Friis noise relationship and the actual component reference planes.
- **Interference headroom:** filtering, LNA and receiver compression, IP3/intermodulation, AGC and nearby in-/out-of-band emitters. GNSS satellite power itself is not the likely overload source.

The UM980 manual states an 18–36 dB *optimum input-gain* range but does not clearly say whether `G_ant` means the LNA/filter/cable chain alone or total directional active realised gain including the passive element. Therefore the BT-T076's `3 dBi` element claim must **not** simply be added to its `32 ±2 dB` LNA claim and compared with 36 dB as though that were a hard limit. Confirm Unicore's definition and each vendor's reference plane, then verify the complete chain with installed measurements. Observe AGC/jamming diagnostics if the UM980 protocol and selected firmware expose them.

V2 Mini uses U.FL, while the standard BT-T076 datasheet specifies SMA-J. If that is the installed antenna, the assembly needs a controlled U.FL-to-SMA pigtail; no pigtail type, length, loss, or accessory line is defined in the current Mini BOM. A different helical termination changes or removes that requirement. Keep any pigtail short and mechanically strain-relieved. An active antenna's LNA before the cable makes post-LNA cable loss much less damaging to system noise figure than the same loss before an LNA, but loss still lowers receiver input level and margin; adapters also add variation and failure points.

## 8. Windscreen, vehicle, and placement effects

### Glass

Ordinary uncoated glass costs a few dB in some reported non-automotive tests, but heat-reflective, athermic, IR, or metallised layers can dominate the entire link budget. u-blox warns that reception through a metallic-coated windscreen may be impossible and notes that some cars provide a small RF-transparent region, often near the mirror. The high-speed-train study cited above is a useful severe-case demonstration, not an automotive estimate.

Before choosing an antenna:

- check the vehicle manual and glass markings for athermic/heat-reflective/metallised treatment;
- identify any OEM toll-tag/GNSS transparent zone;
- avoid embedded conductive heater/defroster wires, camera/radar modules, and metallic tint;
- measure attenuation by matched inside/outside C/N0 tests per band and direction.

Changing antenna tilt at one position does not bypass coating. Moving the antenna to an RF window or outside does.

### Body masking and multipath

The roof, pillars, firewall, bonnet, and occupants block or reflect different sky sectors. A dashboard antenna does not see a clean half-sphere. An illustrative Rohde & Schwarz [GNSS vehicle obscuration/multipath test note](https://cdn.rohde-schwarz.com/pws/dl_downloads/dl_application/application_notes/1gp101/1GP101_1E_Obscuration_and_Multipath_GNSS_Receiver_Testing.pdf) uses different attenuation masks for windows, roof, and body panels precisely because position within a vehicle changes the RF mask; its sample dB values are a simulation model, not Aevia measurements.

Prefer the highest, most central clear location that does not interfere with airbags or sight lines. Keep the antenna away from the display, ESP32/Wi-Fi antenna, USB, SD clocking, switch-mode inductors, and long digital cables. The vehicle roof is usually the best combination of sky view, symmetry, and ground plane; the front dash is a compromise.

The bonnet, dash, glass, barriers, grandstands, other vehicles, and track surface all create multipath. A quality horizontal patch and ground plane can suppress below-plane energy. A helix's broader pattern preserves angular coverage but can accept more of it. Low-elevation satellites already travel through more atmosphere and encounter more multipath; retaining every one is not automatically worth degrading the observation set. Receiver elevation/C/N0/residual weighting remains important for either antenna.

### Dynamic installation tolerance

- A symmetric vertical antenna adds little intrinsic free-space yaw dependence; a tilted lobe adds more. The installed vehicle pattern is heading-dependent in both cases, so explicitly test every vehicle heading.
- Pitch, roll, vibration, and hills perturb `α`. A helix normally degrades more gently; a patch must have sufficient beamwidth around every intended installed angle.
- A few centimetres of mount movement can change a reflection phase by a large fraction of a GNSS wavelength. Use a rigid, repeatable fixture.
- Adhesive thickness, radome, cable routing, and metal plates are RF design variables. Freeze them with the antenna choice.
- If the installed helix is confirmed as BT-T076, its stated upper operating temperature is +70 °C. Confirm the actual sun-loaded dash thermal requirement; do not assume cabin air temperature represents the antenna enclosure.

## 9. What “antenna quality” should mean in procurement

Quality matters least in open sky when all candidate assemblies give strong C/N0, uninterrupted multi-band tracking, and a standalone metre-level solution. In that regime the receiver and software may hide modest observable differences. It matters most when the link has little margin, the vehicle creates strong reflections, carrier phase/RTK is used, nearby transmitters or digital electronics threaten overload, temperatures vary, or results must repeat across units and remounts. These are exactly the conditions in which low axial ratio, stable phase centre, filtering/linearity, documented patterns, and manufacturing tolerance are more important than a peak-gain claim.

Do not rank candidates by total active gain or price alone. Require, in priority order:

1. **Exact frequency coverage:** every UM980 signal Aevia intends to log, especially L1/E1/B1, L2, L5/E5, B2/B3, and L6/E6. Many inexpensive “multi-band” patches are only L1+L5 or L1+L2.
2. **Installed RHCP realised-gain patterns:** by band, at least versus elevation in orthogonal azimuth cuts; 3-D data are better. Require the mounting plane and cable reference.
3. **Axial ratio and LHCP rejection versus angle and band:** zenith-only AR is insufficient for windscreen multipath.
4. **Ground-plane and installation definition:** dimensions, symmetry, required bonding, clearances, radome and cable position. Prefer a supplied/integrated plane if an interior custom plane is impractical.
5. **LNA chain:** gain tolerance, noise figure, input/output match, 3.3 V operation and current, gain flatness, group delay, compression/IP3, and stability.
6. **Filtering:** in-band insertion characteristics and out-of-band rejection around cellular, Wi-Fi, and Aevia's digital/switching emissions. Strong gain without linearity/filtering can be worse.
7. **Phase behaviour:** phase-centre offset/variation by band, group-delay variation, and calibration availability. This becomes decisive for RTK and GNSS/IMU fusion.
8. **Environmental and production quality:** operating/storage temperature, humidity, vibration, connector strain, ESD, ingress if external, lot tolerance, traceability, and repeatability after remounting.
9. **Complete interface fit:** connector, cable type/length/loss by frequency, bias voltage/current, dimensions, mass, and mounting repeatability.

Peak passive gain mostly tells what happens in one direction under one test condition. A lower-peak antenna with low AR, smooth phase centre, good horizon coverage, strong filtering, and honest plots can produce better data than a higher-number part.

## 10. Required A/B test before changing the design

Because installation uncertainty is larger than the likely component margin, the decision should be experimental. Test the **complete assemblies**, not loose radiator elements.

### 10.1 Test matrix

At minimum:

| ID | Antenna | Orientation |
|---|---|---|
| H0 | installed helix complete assembly (BT-T076 only if confirmed) | axis vertical (`α = 0°`) |
| HW | same installed helix assembly | axis normal to measured windscreen |
| P0 | selected required-band active patch plus specified plane/base | face horizontal (`α = 0°`) |
| PW | same patch assembly | face parallel to / normal pointing through windscreen |

Add `α = 15°` and `30°` forward for both if fixture time permits. Include a documented external roof antenna as the reference. Test any passive bare patch only after making the bias interface safe and defining its LNA/ground plane.

### 10.2 Control the experiment

- Same UM980 hardware, firmware, constellations, frequencies, tracking/elevation masks, update rate, dynamic model, correction source, and output messages.
- Same antenna position to within a documented tolerance, with the same cable path and known cable/adapter loss. Record antenna serial number and complete assembly revision.
- Same windscreen and vehicle state. Record rake angle, antenna `α`, xyz position, ground plane dimensions, coating/tint, nearby devices, and whether heater/camera electronics are active.
- For simultaneous comparison, use two identical receivers and swap antennas between receiver channels halfway through to remove receiver bias. Keep antennas separated enough to avoid coupling while exposing nearly the same sky. If only one receiver exists, repeat tests and compare matched satellite/signal/elevation/azimuth bins rather than raw averages from different sky geometry.
- Static open-sky baseline first, then stationary inside-car test, slow 360° heading rotation in an open area, and repeated dynamic laps. Repeat on multiple satellite geometries and in both open and barrier-heavy portions of a circuit.
- Do not judge from one screenshot, time-to-first-fix, or satellite count.

### 10.3 Firmware/logging required

The current Rust firmware does not yet read or log GNSS. First obtain the UM980 commands/logs reference and confirm which fields the installed receiver firmware can output; the bundled user manual confirms NMEA and Unicore formats but not every diagnostic below. Before antenna qualification, record all available required fields without UART/SD drops:

- raw code/pseudorange, carrier phase, Doppler, lock time and loss-of-lock/cycle-slip flags for every constellation, satellite, signal and frequency;
- per-signal C/N0, used/rejected state, satellite azimuth/elevation, and tracking status;
- solution time, position, velocity, DOP/covariance or estimated accuracy, satellite counts, fix type, and RTK state (none/single/float/fixed);
- RTK correction age, baseline/solution status, ambiguity resets, time to first fixed solution, and fraction of time fixed;
- receiver AGC and interference/jamming diagnostics if the protocol and firmware expose them;
- PPS edge captured against a hardware timer, the corresponding GNSS time message, UART receive time, message latency, buffer overruns, SD write stalls, and firmware configuration;
- synchronised SCH16T IMU samples and its time mapping to PPS/GNSS epochs;
- session metadata: antenna type/serial, cable, adapter, externally measured supply voltage/current at the antenna, location, `α`, ground plane, vehicle, windscreen/coating, weather, track direction and software revisions.

The current PCB cannot report antenna open/short/current state through the UM980 because `ANT_DETECT`, `ANT_OFF`, `ANT_SHORT_N`, and `VCC_RF` are unconnected; that requires external instrumentation or a hardware revision. Confirm that UART bitrate and storage throughput can carry the selected raw multi-frequency messages at 20 Hz. Treat 50 Hz as a separate feasibility test: the manual permits up to 50 Hz RTK only in a specific mode and does not promise every raw signal and diagnostic simultaneously. An antenna comparison is invalid if the logger silently discards epochs differently.

### 10.4 Metrics

Compare by constellation, signal/band, 10° elevation bin, and forward/side/rear azimuth sector:

- median, 10th percentile, and distribution of C/N0 for common signals;
- C/N0 versus vehicle heading for individual satellites, revealing tilted-pattern yaw dependence;
- fraction of possible observations logged and fraction used in the solution;
- code-minus-carrier/multipath combinations, pseudorange and carrier residual RMS/tails;
- loss-of-lock and cycle slips per 1,000 observations;
- DOP and geometry after receiver weighting/rejection;
- RTK time to fix, fixed percentage, fix outages/resets, and float/fixed transition count;
- stationary horizontal/vertical scatter and relative dynamic position/velocity differences against the roof comparator;
- 50th/95th/99th-percentile absolute errors only against independent truth such as a calibrated high-grade survey GNSS/INS with a surveyed base, an optical system, or an appropriate track reference;
- lap-line crossing residual and lap/sector repeatability against a track transponder or independently surveyed/time-synchronised reference.

As a useful health check rather than a pass/fail spec, the u-blox note says a well-designed system commonly shows about 44–50 dB-Hz on strong high-elevation signals and about 47 dB-Hz with a standard active antenna. Receiver reporting conventions differ, so Aevia should compare **delta C/N0 on matched signals** and failure-tail metrics rather than impose u-blox's absolute value on UM980.

### 10.5 Measure total in-cabin installation penalty

Use two matched antenna/receiver chains, one immediately inside and one on an unobstructed external/roof comparator, then swap chains. Map C/N0 difference by band, elevation, azimuth and heading. This measures the **combined** effect of glass, different antenna location, roof ground plane, body masking, pattern and multipath; swapping removes receiver-chain bias but does not isolate those mechanisms. A single average will hide a coating or pillar that affects only one sector/band. True glass-only attenuation needs controlled glass/no-glass measurements with otherwise matched geometry, or a representative windscreen coupon in a suitable RF setup.

### 10.6 Pre-register the decision rule

Choose the primary outcome before examining candidate results—for example, RTK-fixed availability plus 95th-percentile lap-line crossing error if RTK timing is the target, or 95th-percentile standalone along-track error and velocity continuity otherwise. First repeat the H0 baseline, including remounting, over multiple satellite geometries and both track directions to measure normal test variability. A candidate wins only if its repeated/crossover confidence interval clears both that baseline variability and a pre-agreed practically meaningful improvement in the primary outcome.

Use matched-signal C/N0, cycle slips, residuals and satellite counts to explain the result, not to replace it. A repeatable 2–3 dB improvement across the actually visible sky is meaningful link margin, but there is no universal dB threshold that guarantees a better position or lap time. Do not select a candidate whose median improves while its outage rate, heading dependence or 95th/99th-percentile errors worsen.

## 11. Final decision matrix

These labels are design priors, not measured rankings.

| Need / condition | Vertical installed helix | Quality required-band patch, horizontal on specified plane | Windscreen-normal helix | Windscreen-normal conventional patch |
|---|---|---|---|---|
| Integration risk today | **Favoured baseline**; assembly already exists | **Unqualified** until part, plane, bias and pattern are defined | Orientation unqualified | Assembly and orientation unqualified |
| Free-space high-elevation response | Candidate-specific; geometry is conventional | **Promising candidate**, pattern-specific | Zenith is off-axis | Zenith is off-axis, potentially strongly at large `α` |
| Match to a forward-only clear aperture | Broad response may cover it | Main lobe not centred on it | Broad response aimed toward it | **Potentially favoured** if its lobe actually matches that aperture |
| Ground-plane dependency | Usually lower, but part-specific | High; exact plane/base required | Usually lower, but part-specific | High; exact plane/base and installed tilt required |
| Multipath and phase quality | BT/current part undocumented | Potentially strongest with good AR, PCV and back-lobe control | Current part undocumented | Could screen cabin reflections, but off-axis AR and geometry may worsen |
| Heading behaviour in vehicle | Little intrinsic yaw asymmetry; vehicle effect remains | Little intrinsic yaw asymmetry; vehicle effect remains | Adds antenna tilt asymmetry to vehicle effect | Adds the strongest directional tilt, which may align with or oppose vehicle aperture |
| Role in the test | **Deployment baseline H0** | **Preferred upgrade candidate P0** | Required comparison HW | Required comparison PW when forward aperture may matter |

Recommended decision:

- **Immediately:** keep the installed helix as the baseline, confirm whether it is actually the BT-T076, mount its axis vertically for H0, verify the 3.3 V bias under load, and complete the appropriate controlled cable/pigtail and logging path.
- **Prototype in parallel:** obtain one active patch assembly that covers every signal Aevia will use, with a defined or integrated ground plane, 3.3 V operation, vendor-confirmed receiver gain compatibility, good AR/pattern/filter data, and stable phase centre. Start horizontal, then test intermediate and measured glass-normal angles.
- **Do not select the patch because of peak gain alone.** Select it only if the four-way installed test improves common-signal C/N0/residuals, cycle-slip tails, RTK fixed availability, and lap-line repeatability without heading-dependent outages.
- **If the actual windscreen is metallised or the interior loses roughly 10 dB or more in important sectors/bands:** treat this as a provisional engineering trigger to stop optimising topology inside. Use the OEM RF-transparent aperture or move the antenna outside to the roof.
- **If Aevia's primary goal remains standalone lap timing rather than RTK:** the improvement may be modest in average horizontal position and much larger in bad-case consistency. The current helix mounted vertically may already be sufficient; spend engineering effort on PPS-aligned timestamps, interpolation, lever-arm calibration, IMU fusion, and validation against a transponder as well as on the antenna.

## 12. Open facts required for a release decision

1. Exact installed helix make, model, revision, connector and cable; confirmation whether it is the planned BT-T076.
2. Exact vehicle model, windscreen rake, construction/coating, and available RF-transparent area.
3. Exact antenna xyz location, permitted size, and whether an external roof cable is acceptable.
4. Exact replacement patch part number and whether it is bare, active, integrated-plane, or roof-puck construction.
5. Candidate per-band patterns, AR, PCV, ground-plane requirement, filter/linearity, 3.3 V current, cable and connector data.
6. Measured V2 Mini bias voltage/current and complete-chain gain/loss; confirmation of UM980 gain interpretation.
7. Installed VNA/return-loss result where accessible and the four-way GNSS observation test.
8. Whether release mode is standalone, correction-aided/DGNSS, RTK float, or RTK fixed; the optimum acceptance metric changes with it.

Until those are known, the honest conclusion is not “helix is X% better” or “patch is X metres better.” It is: **the current helix mounted vertically is the safest first baseline, not a proven optimum; a correctly integrated quality patch has the highest conventional-patch ceiling for clean RTK-capable data, but its best angle may be horizontal, intermediate, or glass-normal depending on the installed aperture; and glass/body effects can overwhelm both.**

## References

- Aevia, [V2 Mini design note](./v2_mini_design.md), [PCB design](./hardware/v2_mini_pcb/v2_mini.kicad_pcb), and [production BOM](./hardware/v2_mini_pcb/production/digikey_bom.csv), used for the fitted RF/bias architecture and current hardware status.
- Unicore Communications, [UM980 product page](https://en.unicorecomm.com/products/um980/) and [UM980 User Manual R1.9](./data/datasheets/UM980_User%20Manual_EN_R1.9.pdf).
- Beitian, [BT-T076 official product page and datasheet images](https://www.beitian.com/en/sys-pd/620.html), rev. 5.53.
- u-blox, [*GNSS antennas: RF design considerations for u-blox GNSS receivers*](https://content.u-blox.com/sites/default/files/products/documents/GNSS-Antennas_AppNote_%28UBX-15030289%29.pdf), UBX-15030289 R03.
- European Space Agency Navipedia, [*Antennas*](https://gssc.esa.int/navipedia/index.php?title=Antennas).
- L. Wanninger, M. Thiemig and V. Frevert, [*Multi-frequency quadrifilar helix antennas for cm-accurate GNSS positioning*](https://doi.org/10.1515/jag-2021-0042), Journal of Applied Geodesy 16(1), 2022.
- D. N. Aloi et al., [*A detailed experimental study on the benefits of electrically grounding glass mounted global positioning system antennas to the vehicle roof*](https://doi.org/10.1049/iet-map.2013.0616), IET Microwaves, Antennas & Propagation 8(11), 2014.
- Z. Liu, Y. Gong and L. Zhou, [*Impact of China's high speed train window glass on GNSS signals and positioning performance*](https://link.springer.com/article/10.1186/s43020-020-00013-z), Satellite Navigation 1:14, 2020.
- Taoglas, [ADFGP.60A all-band active patch datasheet](https://www.taoglas.com/datasheets/ADFGP.60A.01.0150D.pdf), used only as a representative full-band patch, not a selected component.
- Calian, [HC990XF full-band quadrifilar helix datasheet](https://sites.calian.com/app/uploads/sites/13/2024/06/Calian%C2%AE-HC990XF-Datasheet-Rev.-202304.pdf), used only as a quality/characterisation benchmark.
- Rohde & Schwarz, [*Obscuration and multipath simulation for GNSS receiver testing*](https://cdn.rohde-schwarz.com/pws/dl_downloads/dl_application/application_notes/1gp101/1GP101_1E_Obscuration_and_Multipath_GNSS_Receiver_Testing.pdf), used only to illustrate vehicle-dependent RF masking.

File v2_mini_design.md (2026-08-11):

# Open Race V2 Mini

V2 Mini is a battery-powered GNSS and motion board built around the ESP32-S31 module. It has microSD storage, a display interface, physical controls, and native USB. Use the KiCad project and production BOM for build details. This page leaves out pin allocations, routing, and most passive components.

## High-level design

```mermaid
flowchart LR
    MCU["ESP32-S31-WROOM-3<br/>main processor and radio"]
    GNSS["UM980 GNSS<br/>U.FL antenna"]
    IMU["SCH16T-K01-1<br/>6-axis IMU"]
    SD["microSD<br/>4-bit SDIO"]
    LCD["Adafruit 4520 display<br/>24-pin SPI FPC interface"]
    UI["Four UI buttons and four RGB LEDs<br/>TCA9536 + LP5813"]
    USB["USB-C<br/>power and native USB data"]
    PM["Power management<br/>charger, fuel gauge and on/off control"]

    MCU <-->|"Two UARTs, PPS and status"| GNSS
    MCU <-->|"SPI, data-ready and reset"| IMU
    MCU <-->|"4-bit SDIO"| SD
    MCU -->|"Display and backlight control"| LCD
    MCU <-->|"Shared I2C control bus"| UI
    MCU <-->|"I2C and status signals"| PM
    MCU <--> USB
```

The ESP32 module handles processing, radio, and the board's main interfaces. The UM980 sends GNSS data over two UARTs and also has PPS, reset, and status connections. The SCH16T uses a separate SPI bus with data-ready and reset signals.

The microSD socket uses 4-bit SDIO. The selected display is the Adafruit 4520, connected through the 24-pin FPC with a MOSFET-switched backlight. The display panel itself is not a fitted PCB BOM item.

Four user buttons connect through the TCA9536 GPIO expander, and the LP5813 drives four RGB LEDs. Reset and boot/user connect directly to the ESP32. The power button connects to the MAX16169. The charger, fuel gauge, LED driver, and GPIO expander share the board's I2C control bus.

USB-C provides 5 V input and native USB data. The TPD4EUSB30 protects D+, D-, CC1, and CC2. The board also senses VBUS and both CC lines.

## Power tree

```mermaid
flowchart TD
    USB["USB-C J6<br/>5 V VBUS"] --> CHG["BQ25622 U8<br/>1-cell charger and NVDC power path"]
    BAT["1-cell battery J4"] <--> CHG
    BAT --> GAUGE["MAX17048 U9<br/>fuel gauge"]
    CHG --> RAW["3V3_RAW<br/>BQ25622 SYS rail"]

    RAW --> CTRL["MAX16169 U7<br/>power-button controller"]
    BUTTON["Power button SW7"] --> CTRL
    RAW --> REG["TPS63802 U10<br/>3.3 V buck-boost"]
    CTRL -->|"GATE_EN"| REG

    REG --> V33["+3V3"]
    V33 --> CORE["ESP32, microSD, display and user interface"]
    V33 --> FB1["FB1"] --> VGNSS["+3V3_GNSS"] --> GNSS["UM980 and antenna bias"]
    V33 --> FB2["FB2"] --> VIMU["+3V3_IMU"] --> IMU["SCH16T"]
```

The schematic name `3V3_RAW` refers to the BQ25622 SYS rail. The TPS63802 turns it into the regulated `+3V3` system rail. FB1 and FB2 provide filtered supplies for the GNSS receiver and IMU.

The MAX16169 runs from the raw rail and controls the TPS63802 enable input. SW7 connects to its pushbutton input. Its interrupt output goes to the ESP32, and the ESP32 has a separate shutdown control back to it. The MAX17048 measures battery state of charge, while the BQ25622 handles charging and reports power-path status. TH1 is a fitted 10 kOhm NTC in the charger temperature-sense network.

The board expects a 1-cell battery with the matching 2-pin Hirose DF58 connection for J4. The PCB-side connector is `DF58-2P-1.2V(21)`.

## Main fitted parts

The part numbers below come from the production BOM rather than the shortened values shown on some schematic symbols.

| Ref | Ordered part | Purpose |
|---|---|---|
| U2 | `ESP32-S31-WROOM-3-N16R16V` | Main processor and wireless module |
| U1 | `UM980` | GNSS receiver |
| U3 | `SCH16T-K01-1` | 6-axis accelerometer and gyroscope |
| U4 | `LP5813ADRRR` | I2C RGB LED driver |
| U5 | `TCA9536ADTMR` | GPIO expander for the four UI buttons |
| U6 | `TPD4EUSB30DQAR` | USB data and CC ESD protection |
| U7 | `MAX16169AALTA+T` | Power-button and regulator-enable control |
| U8 | `BQ25622ERYKR` | 1-cell charger and NVDC power path |
| U9 | `MAX17048G+T10` | Battery fuel gauge |
| U10 | `TPS63802DLAR` | 3.3 V buck-boost regulator |
| D32-D35 | `MSL0402RGBU1` | Four RGB indicators |
| SW1-SW7 | `B3U-1000P` | Reset, boot/user, four UI buttons, and power |
| TH1 | `NCU18XH103F60RB` | 10 kOhm charger temperature sensor |
| J1 | `U.FL-R-SMT-1(01)` | GNSS antenna connector |
| J2 | `GTFP08441BEU` | microSD socket |
| J3 | `SFV24R-2STE1HLF` | 24-pin FPC connector for the Adafruit 4520 display |
| J4 | `DF58-2P-1.2V(21)` | 1-cell battery connector |
| J6 | `USB4105-GF-A` | USB-C connector |

## Hardware source files

- [Root schematic](pcb/v2_mini_pcb/v2_mini.kicad_sch)
- [PCB layout](pcb/v2_mini_pcb/v2_mini.kicad_pcb)
- [Production BOM](pcb/v2_mini_pcb/production/digikey_bom.csv)
- [BOM exclusions](pcb/v2_mini_pcb/production/bom_exclusions.csv)

# Total production cost for single person for everything - tools

- Board + stencil - 142.30AUD with 50 coupon
- digikey - 200AUD
- gnss module - 120AUD
- antenna - 37AUD
- battery - 15AUD
total: ~500AUD

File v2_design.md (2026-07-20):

goal is to make a garmin catalyst2 but cheaper + better. Custom pcb better performance custom softare, still exporting to proper desktop tooling.

build pcb with this layout:
ESP+Power | Digital+STM+RAM | GNSS+IMU
left to right, have a cm or 2 between digital sensitive to reduce signal interference

check this pcb to see if bga is possible
https://www.st.com/en/evaluation-tools/stm32h7s78-dk.html#cad-resources

v2 pcb
    - Needs to support
    - move to STM32N657X0H3Q
    - clocks:
        - HSE: NDK NX2016SA-24MHZ-EXS00A-CS10820
        - LSE: NDK NX2012SA-32.768KHZ-EXS00A-MU00527
    - flash (boot/code only, XIP — N6 is flashless, do NOT log data here):
        - MX66UW1G45GXDI00 - original octo spi, switch to cheaper quad spi flash under.
        - MX25U51279GXDR00
    - data storage (telemetry log, separate from boot flash):
        - microSD card via socket (Hirose DM3CS-SF), 3.3V, SDIO/SPI
    - external RAM for STM32N6
        - AP Memory APS512XXN-OB9-BG OPI/HPI PSRAM, 1.8V
        - verify the exact x16 ballout and repair the current VSS/data-pin net error before powering it
    - much faster battery charging, at least 1C
        - must have usb pd 
        - AP33772S pd controller, i2c
        - battery is 2s 21700 cells
        - BQ25798 charger provides the NVDC power path; 5A maximum charging does not mean a guaranteed 5A SYS load
        - MAX17320 to guage battery % and protection
            - NTC thermistor: NCP15XH103F03RC
        - downstream power system from the BQ25798 SYS pin
            - `VSYS_RAW`: unregulated BQ25798 system output; approximately the loaded 2S battery voltage with no input, and up to about 9V with an input/full battery
            - `+3V3_MAIN` @ 3A: TPSM863253RDXR fixed-output buck module
                - STM32N657 VDD/VBAT/VDD33USB and 3.3V I/O banks
                - microSD, USB-C protection power, pull-ups and general digital peripherals
                - ESP32-C6, GNSS and IMU use switched/filtered branches unless the final load budget requires another 3.3V converter
            - `+1V8_AON`: RPL-3.0-R buck module set to 1.8V; enabled by `+3V3_MAIN` power-good
                - directly powers STM32N657 VDDA18AON and PDR_ON
                - also feeds a >=2A, low-Ron, slew-controlled load switch
            - `+1V8_RUN`: output of the 1.8V load switch, enabled by the STM32 `PWR_ON` output
                - STM32 VDDSMPS, VDDA18PMU and the other run-time 1.8V analogue domains
                - VDDIO2/VDDIO3, APS512 PSRAM and MX25U51279 flash
                - STM32 internal SMPS then generates VDDCORE/VDDCSI; do not attach an external regulator to VDDCORE
            - `+5V_AUX` @ 1A: second RPL-3.0-R set to 5V while APA102 LEDs are fitted
                - APA102 LEDs, 5V AHCT clock/data buffer, optional buzzer and optional GNSS/IMU LDO inputs
                - validate 5V regulation at the minimum loaded battery voltage; use buck-boost if SYS can fall too close to 5V
            - display backlight driver connects to `VSYS_RAW`; topology/output TBD after selecting the panel and LED string
        - low-noise and switched branches
            - `+3V3_RADIO_SW`: load-switched branch of `+3V3_MAIN` for ESP32-C6; give the ESP supply at least 500mA capability
            - `+3V3_GNSS_CLEAN`: filtered branch of `+3V3_MAIN` by default, or LT3045EDD#TRPBF from `+5V_AUX` if ripple testing requires an LDO
            - `+3V3_IMU_CLEAN`: filtered branch of `+3V3_MAIN` by default, or TPS7A02 from `+5V_AUX` if a dedicated LDO is retained
    - Murata SCH16T-K01/K20 imu most ikelye K01, k20 not available yet easily
    - USB C protection - TI TPD8S300A
    - leds:
        - for on board small dev indicators, Lite-On LTST-C190
        - APA102-2020-256-8 for brighter LEDs; powered from `+5V_AUX` with an AHCT-family clock/data buffer
    - 5 inch 1000nit display maybe touchscreen?
        - use panelook.com
        - [search](https://www.panelook.com/modelsearch.php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)
    - extra buttons
        - something super high quality and tactile?
    - extra leds
        - rgb smd
    - unicore um980 module
        - 20hz multi constellation spp fixes
        - 50hz rtk based fixes using 1hz spp. Rtk hard to work with? on standalone pcb not worth, probably need phone connection
        - maybe best in price range m10s and others dont have 20hz multi constellation, only single constellation, 
    - Antenna
        - Beitian BT-T076
    - buzzer, speaker probably overkill
    - esp32-c6 to handle bluetooth/wifi and smaller less important things like leds to save stm pins for important stuff
        - esp32-c6-mini-1
        - powered from `+3V3_RADIO_SW`, a load-switched/filtered branch of `+3V3_MAIN`
        - ability ot have random bluetooth sensors around the car? maybe not car very noisy
        - use this to run the leds
        - flashing over uart
    - deal with usb protection later
    - deal with debugging access later

### Power Tree
```mermaid
flowchart TD;
    USB[USB-C]
    PD[AP33772S PD sink<br/>I2C to STM32]
    BQ[BQ25798 buck-boost charger<br/>direct power path]
    BAT[2S 21700 cells<br/>rated >1C charge]
    FG[MAX17320 fuel gauge + protection<br/>reports SoC %]
    SYS((VSYS_RAW<br/>2S battery minimum to about 9V))

    B33[TPSM863253RDXR<br/>fixed 3.3V / 3A buck module]
    V33((+3V3_MAIN))
    L33[STM32N657 3.3V domains<br/>microSD / USB protection<br/>pull-ups and peripherals]
    BRADIO[+3V3_RADIO_SW<br/>+3V3_GNSS_CLEAN<br/>+3V3_IMU_CLEAN]

    B18[RPL-3.0-R<br/>1.8V buck module]
    V18A((+1V8_AON))
    L18A[VDDA18AON<br/>PDR_ON]
    S18[>=2A slew-controlled<br/>1.8V load switch]
    PWRON[STM32 PWR_ON<br/>output]
    V18R((+1V8_RUN))
    L18[VDDSMPS / 1.8V analogue domains<br/>VDDIO2/3 / PSRAM / flash]
    CORE[STM32N6 internal SMPS<br/>external 1uH + required capacitors<br/>VDDCORE / VDDCSI]

    B5[RPL-3.0-R<br/>5V / 1A auxiliary buck]
    V5((+5V_AUX))
    L5[APA102 LEDs + AHCT buffer<br/>optional buzzer / LDO inputs]
    BL[display backlight driver<br/>topology TBD with panel]

    USB -->|PD| PD
    PD -->|VBUS| BQ
    BQ <--> BAT
    BAT --- FG
    BQ -->|power path| SYS

    SYS --> B33
    SYS --> B18
    SYS --> B5
    SYS --> BL

    B33 --> V33
    V33 --> L33
    V33 --> BRADIO
    B33 -. PG with pull-up enables CTRL .-> B18

    B18 --> V18A
    V18A --> L18A
    V18A --> S18
    PWRON -->|enable| S18
    S18 --> V18R
    V18R --> L18
    L18 -->|VDDSMPS| CORE

    B5 --> V5
    V5 --> L5
```

#### Rail budgets and implementation notes

| Net | Design target | Main loads |
|---|---:|---|
| `VSYS_RAW` | Battery/BQ power budget; approximately battery minimum to 9V | Inputs of the downstream converters and the backlight driver only |
| `+3V3_MAIN` | 3.3V, 3A | STM32 3.3V domains, microSD and general peripherals; filtered/switched ESP32, GNSS and IMU branches |
| `+1V8_AON` | 1.8V source for the complete 1.8V system | VDDA18AON/PDR_ON directly and the input of the RUN load switch |
| `+1V8_RUN` | 1.8V, 1.5A minimum / 2A preferred | STM32 VDDSMPS/analogue domains, VDDIO2/3, PSRAM and flash |
| `+5V_AUX` | 5V, 0.5A LEDs only / 1A shared | APA102 LEDs, level buffer, optional buzzer and optional clean-rail LDO inputs |
| Backlight output | TBD | Define after the display LED string is selected |

- Only `VSYS_RAW` is directly connected to the BQ25798 SYS pin. No logic device is powered directly from it.
- Battery-only `VSYS_RAW` approximately follows the pack, so its minimum is set by the loaded battery and BMS cutoff. With an input present it is controlled by the BQ25798 minimum-system/battery-following behaviour and can approach 9V for a full 2S pack. Use direct-SYS converters rated for at least 12V input; the selected modules are rated for 17V or 18V.
- `TPSM863253RDXR` integrates the 3.3V feedback network, bootstrap capacitor and inductor. Start with at least 10uF effective input capacitance and 22uF effective output capacitance; 44uF output is preferred for transient margin after DC-bias derating.
- `RPL-3.0-R` integrates its inductor. The 1.8V starting network is 10uF input, 22uF output, 47k/37.4k feedback, 22pF feed-forward and 1k sense. The 5V starting network uses 47k/8.87k and 39pF. Recalculate effective ceramic capacitance at operating bias.
- Use the open-drain TPSM863253 `PG` pin, pulled up to `+3V3_MAIN`, to drive the 1.8V RPL `CTRL` input. `PWR_ON` is an STM32 output and then enables the `+1V8_RUN` load switch.
- Keep the BQ25798-local SYS capacitor bank at its pins. Target the reference arrangement of five 10uF capacitors plus 100nF, using >=16V X5R/X7R parts and checking effective capacitance after DC bias.
- The selected regulator modules eliminate separate regulator inductors and compensation networks, but they do not replace the decoupling required at the STM32, RAM, flash, SD card, radio, GNSS or sensors.
- Complete the simultaneous peak-current, efficiency and thermal budget before layout freeze. The per-rail ratings are design limits and cannot all be treated as independently available from the BQ25798 at the same time.
- Do not create the old separate 3.3V LED and ESP buck rails unless final simultaneous-current or noise testing proves they are necessary. APA102 LEDs use `+5V_AUX`, not 3.3V. The UM980 itself uses 3.3V, not 5V.
- Stay in microSD 3.3V Default/High-Speed signalling mode for the lowest component count. SDR104 requires the proper 1.8V signalling switch/transceiver and is not obtained by simply moving the card supply to 1.8V.

Primary regulator references:

- [TPSM863253 product page](https://www.ti.com/product/TPSM863253)
- [RPL-3.0 datasheet](https://recom-power.com/pdf/Innoline/RPL-3.0.pdf)
- [BQ25798 datasheet](https://www.ti.com/lit/ds/symlink/bq25798.pdf)
- [STM32N6 hardware-development guide](https://www.st.com/resource/en/application_note/an5967-getting-started-with-hardware-development-for-stm32n6-mcus-stmicroelectronics.pdf)

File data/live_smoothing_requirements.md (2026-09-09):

# Live extended RTS smoothing and moving startup

This change adds a bounded extended Rauch–Tung–Striebel backward pass to the
existing live ESKF. It also permits a simple start while the module is moving.
These are engine development requirements; their implementation does not
establish timing or accuracy qualification on the ESP32-S31.

## Smoothing behavior

- `NavigationProfileSpec.smoothing_lag` declares additional lookahead beyond
  the effective-time GNSS reorder delay. The supported range is 0–100 ms.
  Zero preserves the forward-filter comparison path. A production caller
  selects a nonzero lag and records it in a new navigation-profile revision
  and digest.
- The forward ESKF still processes measurements once, in effective-time order.
  A backward pass uses stored forward states and covariance relationships to
  refine recent trajectory endpoints. It does not relinearize the entire
  window or run an iterated nonlinear optimizer.
- The forward predictor continues to provide the latest supported present
  state. The navigation watermark, trajectory publication and metric
  consumption advance only through endpoints committed by the smoother.
  Normal publication latency therefore includes both reorder delay and
  smoothing lookahead, plus any queued bounded work.
- Shared calibration/clock uncertainty and held interval-average IMU errors
  retain their correlation semantics through the smoothing pass. They must
  not be counted as fresh independent evidence on each edge.
  The constrained Schmidt backward pass keeps nuisance means and covariances
  fixed, including held-sample and gap errors. It retains the extra
  predicted-to-smoothed error cross covariance required by those constraints;
  it reduces to ordinary RTS for a standard Kalman filter. It does not recover
  information discarded by the forward Schmidt approximation or jointly fit
  the calibration parameters. Singular systems are solved only in their
  supported covariance subspace.
- Every published segment preserves its original IMU attitude support and
  input-degradation flags. GNSS quality is captured at each forward endpoint;
  a later fix must not erase or incorrectly relabel earlier quality evidence.
- Committed endpoints remain immutable. Consecutive published segments share
  the same boundary state and covariance, including at window rollover.

## Lifecycle and bounded work

- `WorkQuota` bounds forward and backward frontier operations. Insufficient
  credit pauses work without partially publishing a segment. Empty-observation
  calls resume the retained work deterministically.
- `finish()` drains the forward filter and remaining smoother tail through
  the final trusted IMU epoch before reporting completion. The shorter final
  window is intentional; no state is extrapolated beyond available support.
- Exact clock transitions flush the old window through the boundary before
  changing the clock covariance coordinates or discarding navigation.
  Independent/unavailable transitions must not produce a segment bridging
  the resulting restart.
- Reanchoring transforms every retained navigation-frame smoother quantity.
  Reset/reinitialization clears unfinished smoothing state while preserving
  already committed trajectory and existing metric withdrawal behavior.
- Storage and solver scratch are caller-owned, with a fixed **64-node**
  smoother window. Queues do not grow to absorb lateness or overload. A full
  window is an explicit capacity failure; it does not silently shorten the
  configured lag or publish an endpoint early. The normal live path remains
  allocator-free and has no GTSAM dependency.

## Moving startup

- Two fresh, advancing GNSS position/velocity epochs and valid current IMU
  support can seed navigation without a stillness prerequisite. Reusing or
  extrapolating one receiver epoch does not count as a second fix, and both
  retained epochs must satisfy the configured age limit.
- Moving alignment uses a coarse gravity-based tilt estimate and calibrated
  bias priors, with uncertainty reflecting the weak initial attitude
  information. It does not estimate a static gyro bias from moving samples.
- A supplied heading remains usable. GNSS course is not assumed to be body
  heading for an arbitrary attachment; unknown heading remains explicitly
  unobservable.
- The existing stationary alignment path remains available. Missing/invalid
  observations do not qualify a moving start, and gaps or clock resets still
  apply the existing reinitialization rules.

## Resource and compatibility contract

`LiveResourceLimits::V2_MINI_RTS` introduces a **3 MiB PSRAM development ceiling**
for the fixed smoothing workspace. `V2_MINI_INITIAL` retains its original
1 MiB value, so old recorded resource definitions keep their meaning. Internal
SRAM remains capped at 192 KiB including a 32 KiB stack, and the recorder keeps
its separate original budget. `WorkspaceRequirements` reports actual compiled
object sizes; the PSRAM compile-time check retains a 32 KiB margin.

The fitted N16R16V module's memory capacity alone is not timing evidence.
Before release, measure the final linker placement, stack high-water mark,
PSRAM cache contention, forward/backward work latency, frontier delay and
combined acquisition/recording/UI load on the actual module. Do not reuse an
old hardware qualification report for the new navigation profile.

Captured replay executes the same configured live implementation. Changing
the smoothing lag or startup behavior changes output values, publication
timing and work consumption, so same-build transcript hashes must be captured
again for the new profile. The implementation does not promise bit-exact
replay of captures produced by an older estimator build.

## Regression acceptance

Verify future GNSS improves a retained historical estimate without changing
the forward predictor into a smoothed present estimate; zero-lag equivalence;
bounded-drain equivalence; immutable shared endpoints; correct historical GNSS
quality; complete finish; clock-boundary flush; reanchor/reset behavior; and
capture/replay identity for the new implementation. Include a start with
nonzero motion and insufficient stationary evidence. Run host tests and the
allocator-free target checks; report hardware qualification separately.

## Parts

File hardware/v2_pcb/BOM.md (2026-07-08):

# v2 BOM — Major Components

place to order, if from jlcpcb, then get them to assemble aswel

| # | Category | Function | Part Number | placeto order | Qty | Price |
|---|---|---|---|---|---|---|
| 1 | Compute | Main MCU | STM32N657X0H3Q | jlcpcb | 1 | 40 |
| 2 | Compute | Wireless co-proc | ESP32-C6-MINI-1U | jlcpcb | 1 | 5 |
| 3 | Memory | Boot flash | MX25U51279GXDR00 | digikey | 1 | 18 |
| 4 | Memory | Data storage (micro sd) | anything, maybe sandisk/samsung industrial alter on, for now cheapest | anywhere | 1 | 15 |
| 5 | Memory | micro sd socket | DM3CS-SF | digikey | 1 | 2 |
| 6 | Memory | PSRAM | Infinieon S80KS5122GABHV020 | digikey | 1 | 19 |
| 7 | Clocks | HSE crystal | NDK NX2016SA-24MHZ-EXS00A-CS10820 | digikey | 1 | 1 |
| 8 | Clocks | LSE crystal | NDK NX2012SA-32.768KHZ-EXS00A-MU00527 | digikey | 1 | 1 |
| 9 | Power | USB-PD sink controller | AP33772S | digikey | 1 | 3 |
| 10 | Power | Battery charger | BQ25798 | jlcpcb | 1 | 4 |
| 11 | Power | Fuel gauge / protection | MAX17320 | SoC gauge + protection | 1 | 10 |
| 12 | Power | Battery pack | 21700 cell | anywhere | 2 | 10 |
| 13 | Power | USB-C port protection | TI TPD8S300A | jlcpcb | 1 | 2 |
| 14 | Power | 3.3V buck-boost | TPS63802 | jlcpcb | 2 | 2 |
| 17 | Power | 1.8V buck and 3.3v buck (leds) | TPS62A02 | digikey | 2 | 1 |
| 18 | Power | GNSS LDO | LT3045EDD#TRPBF | jlcpcb | 1 | 9 |
| 19 | Power | IMU LDO | TI TPS7A02 | digikey | 1 | 1 |
| 20 | Power | 5V boost | TBD | Optional, for buzzer | 0 | TBD |
| 23 | Sensors | IMU | Murata SCH16T-K01/K20 | mouser | 1 | 80 |
| 24 | GNSS | GNSS module | Unicore UM980 | aliexpress | 1 | 120 |
| 25 | GNSS | Antenna | Beitian BT-T076 | GNSS antenna | 1 | 35 |
| 26 | HMI | Indicator LEDs | Lite-On LTST-C190 | digikey | 5 | 1 |
| 27 | HMI | Bright RGB LED | APA102-2020-256-8 | digikey | 5 | 1 |
| 28 | HMI | Display | TBD | 5", 1000 nit, possible touchscreen | 1 | 70 |
| 29 | HMI | Buttons | TBD | High-quality tactile switches | 5 | 1 |

## cost estimation
jlcpcb assembly so 2x boards,
um980, batteries, antenna excluded

### JLCPCB-assembled parts (×2 boards)

| Part | ×2 |
|---|---|
| STM32N657X0H3Q | 80 |
| ESP32-C6-MINI-1U | 10 |
| BQ25798 | 8 |
| TPD8S300A | 4 |
| TPS63802 ×2 | 4 |
| LT3045 | 18 |
| **Subtotal** | **124** |

### DNP parts (×1 board)

| Part | Cost |
|---|---|
| MX25U51279 boot flash | 18 |
| microSD card | 15 |
| microSD socket (DM3CS-SF) | 2 |
| S80KS5122 PSRAM | 19 |
| HSE + LSE crystals | 2 |
| AP33772S PD | 3 |
| MAX17320 | 10 |
| TPS62A02 ×2 | 1 |
| TPS7A02 | 1 |
| Murata SCH16T IMU | 80 |
| Indicator LEDs ×5 | 1 |
| APA102 RGB ×5 | 1 |
| Display | 70 |
| Buttons ×5 | 1 |
| um980 | 120 |
| antenna | 36 |
| **Subtotal** | **380** |

### PCB + passives + assembly

| Item | Estimate |
|---|---|
| PCB (5×, 6-layer, ENIG 2u, black, Tg155) | 170 |
| Passives R/C + ~7 inductors, 2 boards | ~25 |
| JLCPCB SMT service | ~35 |

### Total

| | Amount |
|---|---|
| JLCPCB parts ×2 | 124 |
| Own parts ×1 | 380 |
| PCB | 170 |
| Passives + assembly | ~60 |
| **Bare total (parts + fab + assembly)** | **≈ $734** |
| Shipping (JLCPCB + DigiKey/Mouser) | ~55 |
| random bs for safety ~10% | ~58 |
| **All-in for one working board** | **≈ $845** |

aud

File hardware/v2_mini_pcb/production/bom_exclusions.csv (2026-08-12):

Reference | Value | Manufacturer Part Number | Footprint | Exclusion Reason
C12 | DNP | DNP | Capacitor_SMD:C_0402_1005Metric | DNP
C24 | DNP | DNP | Capacitor_SMD:C_0402_1005Metric | DNP
C25 | DNP | DNP | Capacitor_SMD:C_0402_1005Metric | DNP
C26 | DNP | DNP | Capacitor_SMD:C_0402_1005Metric | DNP
H4 | MountingHole_Pad |  | MountingHole:MountingHole_2.2mm_M2_Pad | exclude_from_bom
H5 | MountingHole_Pad |  | MountingHole:MountingHole_2.2mm_M2_Pad | exclude_from_bom
H6 | MountingHole_Pad |  | MountingHole:MountingHole_2.2mm_M2_Pad | exclude_from_bom
H7 | MountingHole_Pad |  | MountingHole:MountingHole_2.2mm_M2_Pad | exclude_from_bom
J5 | TC2030 | TC2030-IDC-NL (mating cable) | Connector:Tag-Connect_TC2030-IDC-NL_2x03_P1.27mm_Vertical | exclude_from_bom
TP1 | TestPoint | N/A (PCB test pad) | TestPoint:TestPoint_Pad_D1.0mm | non-purchased PCB feature
TP2 | TestPoint | N/A (PCB test pad) | TestPoint:TestPoint_Pad_D1.0mm | non-purchased PCB feature

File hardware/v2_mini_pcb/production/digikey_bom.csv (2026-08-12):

Quantity | Digi-Key Part Number | Manufacturer Part Number | Manufacturer | Customer Reference | Value | Footprint
2 | 490-5922-1-ND | GRM1555C1H101JA01D | Murata Electronics | C1,C3 | 100pF | Capacitor_SMD:C_0402_1005Metric
12 |  | CL05B104KO5NNNC | Samsung Electro-Mechanics | C2,C8,C9,C11,C13,C15,C21,C22,C29,C38,C40,C41 | 100nF | Capacitor_SMD:C_0402_1005Metric
6 | 445-14418-1-ND | C2012X5R1V106K125AC | TDK | C4,C5,C6,C7,C20,C35 | 10uF | Capacitor_SMD:C_0805_2012Metric
5 | 311-1903-1-ND | CC0805MKX5R8BB226 | YAGEO | C10,C28,C30,C31,C32 | 22uF | Capacitor_SMD:C_0805_2012Metric
5 | 1276-CL10A106KP8NNNDCT-ND | CL10A106KP8NNND | Samsung Electro-Mechanics | C14,C23,C27,C33,C36 | 10uF | Capacitor_SMD:C_0603_1608Metric
1 | 587-MCASG168AB7105KTNA01CT-ND | MCASG168AB7105KTNA01 | Taiyo Yuden | C16 | 1uF | Capacitor_SMD:C_0603_1608Metric
1 | 490-3254-1-ND | GRM155R71E473KA88D | Murata Electronics | C17 | 47nF | Capacitor_SMD:C_0402_1005Metric
1 | 490-7203-1-ND | GRM188R61E475KE11D | Murata Electronics | C18 | 4.7uF | Capacitor_SMD:C_0603_1608Metric
1 |  | CL05B104KB54PNC | Samsung Electro-Mechanics | C19 | 100nF | Capacitor_SMD:C_0402_1005Metric
1 | 490-GRT188R61A226ME13DCT-ND | GRT188R61A226ME13D | Murata Electronics | C34 | 22uF | Capacitor_SMD:C_0603_1608Metric
2 |  | CL05A105KA5NQNC | Samsung Electro-Mechanics | C37,C39 | 1uF | Capacitor_SMD:C_0402_1005Metric
1 |  | TPD1E0B04DPYR |  | D1 | ~ | Package_SON:Texas_DPY0002A_0.6x1mm_P0.65mm
1 |  | ESDS311DYFR |  | D2 | ~ | Diode_SMD:D_SOD-323F
4 |  | MSL0402RGBU1 |  | D32,D33,D34,D35 | MSL0402RGBU1 | all:LED_MSL04_ROM
2 |  | MPZ2012S601ATD25 |  | FB1,FB2 | BLM21SP601SN1D | Inductor_SMD:L_0805_2012Metric
1 |  | U.FL-R-SMT-1(01) |  | J1 | Conn_Coaxial | all:U.FL_Hirose_U.FL-R-SMT-1_Vertical
1 |  | GTFP08441BEU | Amphenol | J2 | GTFP08441BEU | all:AMPHENOL_GTFP08441BEU
1 |  | SFV24R-2STE1HLF | Amphenol | J3 | SFV24R-2STE1HLF | all:AMPHENOL_SFV24R-2STE1HLF
1 |  | DF58-2P-1.2V(21) |  | J4 | Battery | all:HRS_DF58-2P-1.2V_21_
1 |  | USB4105-GF-A | GCT | J6 | USB4105-GF-A | all:GCT_USB4105-GF-A
1 |  | LQW18AN68NJ00D |  | L1 | 68nH | Inductor_SMD:L_0603_1608Metric
2 |  | DFE252012F-1R0M=P2 |  | L2,L4 | 1uH | Inductor_SMD:L_1008_2520Metric
1 | 1276-6902-1-ND | CIGT201610EHR47MNE | Samsung Electro-Mechanics | L5 | 0.47uH | all:L_Samsung_CIGT201610
1 |  | NTNS3164NZT5G |  | Q1 | NTNS3164NZT5G | Package_TO_SOT_SMD:SOT-883
14 | 311-10.0KLRCT-ND | RC0402FR-0710KL | YAGEO | R1,R2,R3,R6,R7,R8,R9,R20,R22,R23,R24,R27,R34,R35 | 10k | Resistor_SMD:R_0402_1005Metric
1 |  | RC0402FR-0715RL |  | R4 | 15 | Resistor_SMD:R_0402_1005Metric
2 | 311-100KLRCT-ND | RC0402FR-07100KL | YAGEO | R5,R29 | 100k | Resistor_SMD:R_0402_1005Metric
5 | 311-22.0LRCT-ND | RC0402FR-0722RL | YAGEO | R10,R17,R19,R30,R31 | 22 | Resistor_SMD:R_0402_1005Metric
4 | 311-5.10KLRCT-ND | RC0402FR-075K1L | YAGEO | R11,R12,R16,R21 | 5.1k | Resistor_SMD:R_0402_1005Metric
1 |  | RC0402FR-075K62L |  | R13 | 5.62k | Resistor_SMD:R_0402_1005Metric
1 |  | RC0402FR-075K23L |  | R14 | 5.23k | Resistor_SMD:R_0402_1005Metric
1 |  | CRCW040230K1FKED |  | R15 | 30.1k | Resistor_SMD:R_0402_1005Metric
1 |  | RC0402FR-07499RL |  | R18 | 499 | Resistor_SMD:R_0402_1005Metric
1 |  | RC0603FR-07511KL |  | R25 | 511k | Resistor_SMD:R_0603_1608Metric
1 |  | RC0603FR-0791KL |  | R26 | 91k | Resistor_SMD:R_0603_1608Metric
1 | RMCF0402FT75K0CT-ND | RMCF0402FT75K0 | Stackpole Electronics Inc | R28 | 75k | Resistor_SMD:R_0402_1005Metric
2 | 311-22.0KLRCT-ND | RC0402FR-0722KL | YAGEO | R32,R33 | 22k | Resistor_SMD:R_0402_1005Metric
7 |  | B3U-1000P |  | SW1,SW2,SW3,SW4,SW5,SW6,SW7 | SW_Push | Button_Switch_SMD:SW_SPST_B3U-1000P
1 |  | NCU18XH103F60RB |  | TH1 | 103KT1608T-1P | Resistor_SMD:R_0603_1608Metric
1 |  | UM980 | Unicore Comm | U1 | UM980 | all:XCVR_UM980
1 |  | ESP32-S31-WROOM-3-N16R16V |  | U2 | ~ | all:ESP32-S31-WROOM-3
1 |  | SCH16T-K01-1 | Murata | U3 | SCH16T-K01-1 | all:XDCR_SCH16T-K01-1
1 |  | LP5813ADRRR | Texas Instruments | U4 | LP5813ADRRR | all:IC_LP5813ADRRR
1 |  | TCA9536ADTMR |  | U5 | TCA9536ADTMR | all:X2SON8_DTM_TEX
1 |  | TPD4EUSB30DQAR |  | U6 | TPD4EUSB30 | Package_SON:USON-10_2.5x1.0mm_P0.5mm
1 |  | MAX16169AALTA+T |  | U7 | MAX16169AALTA+T | all:21-0164_L622&plus_1_ADI
1 |  | BQ25622ERYKR |  | U8 | BQ25622ERYKR | all:WQFN-HR18__RYK_TEX
1 |  | MAX17048G+T10 |  | U9 | MAX17048G_T10 | all:SON50P200X200X80-9N
1 |  | TPS63802DLAR | Texas Instruments | U10 | TPS63802DLAR | all:VREG_TPS63802DLAR

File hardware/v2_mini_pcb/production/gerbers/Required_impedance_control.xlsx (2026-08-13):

Signal Layer | Reference Layer | Impedance Type | Trace Width (mil) | Trace Spacing (mil) | Impedance (ohm) +/-10% | Position / Net
L1 (F.Cu) | L2 (GND1) | Differential Pair (Non-Coplanar) | 5.34 | 5.91 | 90 | USB 2.0 High-Speed D+ / D- J6 USB-C -> U6 ESD -> R10/R17 -> U2 pins 40/41 Nets: /ESP32-S31 MCU/USB_DP and /ESP32-S31 MCU/USB_DN
L1 (F.Cu) | L2 (GND1) | Single-Ended (Non-Coplanar) | 5.94 | N/A | 50 | GNSS RF feed J1 U.FL -> C1 -> U1 ANT_IN (D1 ESD and L1 bias-tee branches) Nets: Net-(D1-A2) and Net-(U1-ANT_IN)
L6 (B.Cu) | L5 (GND2) | Single-Ended (Non-Coplanar) | 5.91 | N/A | 50 | microSD SDIO bus U2 ESP32-S31 -> J2 microSD (SD_CLK through R19) Nets: SD_CLK, SD_CMD, SD_D0, SD_D1, SD_D2 and SD_D3

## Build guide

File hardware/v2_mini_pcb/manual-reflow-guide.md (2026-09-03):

# v2_mini manual double-sided reflow guide

> [!WARNING]
> There is no fully manufacturer-approved two-pass process for this PCB. The UM980 and ESP32-S31-WROOM-3 overlap on opposite sides. Unicore does not recommend two soldering cycles for the UM980, and Espressif specifies a single SAC305 reflow for the WROOM. The Sn63/Pb37 process below is therefore an unqualified prototype method, not a production process.

This procedure is tailored for fresh eutectic 63Sn/37Pb solder paste, front and back stencils, suitable flux, magnification, a temperature-controlled hot-air station with low airflow, no thermocouples, and no rigid PCB holder. It assumes there is a workable way to hold the PCB flat while printing paste.

Sn63/Pb37 paste becomes fully liquid at approximately 183 degrees C. Follow the temperature and timing limits printed on the solder-paste container or its technical data sheet; they take precedence over the generic guidance here. Do not use the SAC305 temperatures from the component datasheets as an Sn63/Pb37 target. The components may have lead-free terminal finishes, so the completed joints are mixed metallurgy and may not behave as perfectly eutectic Sn63/Pb37.

Without thermocouples, the actual joint temperature, peak temperature, and time above liquidus cannot be verified. The visible cues below can reduce guesswork, but they cannot prove that hidden centre or ground-pad joints reflowed. Do not treat the hot-air station's displayed air temperature as the PCB temperature.

For the detailed component-by-component assessment and manufacturer sources, see [reflow-assembly-audit.md](reflow-assembly-audit.md).

## Equipment and setup

Required:

- Temperature-controlled hot-air station with adjustable low airflow; do not use a paint-stripping heat gun
- Front and back stencils
- Fresh Sn63/Pb37 solder paste within its shelf life
- Suitable no-clean flux for touch-up and rework
- Magnification
- Fine tweezers
- Stopwatch or timer
- A stable, level, non-combustible support arrangement with an open cavity below underside components
- Fume extraction and normal lead-handling precautions

A PCB preheater is strongly recommended. It reduces the time spent blasting the modules with hot air and reduces temperature gradients. A preheater is not a substitute for a thermocouple, however.

Let refrigerated paste reach room temperature while still sealed, for the time specified by its maker. Mix it only as directed, use a clean paste tool, and do not return used paste to the fresh container. Keep food and drink away from the bench, collect lead-contaminated waste, clean the work surface, and wash hands after handling the paste or assembled PCB.

The paste Gerbers are:

- [Front paste](production/gerbers/v2_mini-F_Paste.gtp)
- [Back paste](production/gerbers/v2_mini-B_Paste.gbp)

Stencil one side at a time. The existing stencil workaround is acceptable only if it keeps the PCB flat, does not smear the first-side paste or components, and leaves the stencil parallel to the board. Inspect every aperture deposit under magnification before placing parts.

The stencil workaround is not automatically suitable as a reflow support. Before heating, make a separate support arrangement that:

- Contacts only unused PCB edges
- Leaves at least 5 mm clearance beneath all populated components
- Cannot soften, tip, spring, or slide when hot air is applied
- Holds the PCB horizontal without bending or twisting it
- Does not significantly block airflow or act as a large heat sink at one edge

Test the cold setup with gentle taps and the intended air setting before placing paste. If it moves, improve it before attempting reflow.

## 1. Check moisture exposure

If the components were freshly removed from sealed dry bags, proceed within their specified floor life.

Bake according to the packaging label and J-STD-033 if:

- The WROOM or SCH16T has been exposed for more than 168 hours
- An MSL3 LED has exceeded its floor life
- The humidity-indicator card shows excessive moisture

Remove components from tape, reel, or other temperature-limited packaging before baking. Do not improvise baking temperatures; follow the component bag label or manufacturer instructions.

## 2. Learn the paste's visual behaviour

If possible, make a small practice print on a scrap PCB with similar copper and thermal mass before assembling this board. Use the same stencil, paste thickness, support arrangement, hot-air nozzle, distance, and airflow planned for the real board.

Observe the sequence under magnification:

1. The paste warms and the flux activates.
2. The deposits slump slightly.
3. The solder changes quickly into a bright, mobile liquid and pulls toward the pads.
4. On cooling, the bulk paste deposit freezes quickly; mixed-metal joints may be less abrupt.

Use the practice piece to find a conservative station setting and hand motion. Record the air setting, nozzle distance, warm-up time, and time from the first joint becoming liquid until the last joint becomes liquid. These are process notes, not measured component temperatures.

Do not add extra flux to normal stencil deposits. Fresh paste already contains flux, and extra liquid can make small parts float or move. Reserve the separate flux for touch-up, rework, and the USB-C shell stakes.

## 3. Reflow the back first

The back contains U2 WROOM, U3 SCH16T, J3 FPC connector, and the switches.

1. Hold the bare PCB completely flat using the stencil workaround.
2. Stencil the back with fresh Sn63/Pb37 paste.
3. Lift the stencil cleanly and inspect every deposit under magnification. Clean and reprint the whole side if important deposits are smeared, bridged, incomplete, or misregistered.
4. Place the small passives and ICs first.
5. Place the switches and FPC connector.
6. Place the SCH16T and WROOM last.
7. Do not manually add paste blobs beneath the WROOM EPAD. Excess paste can lift the module and prevent its other pads from contacting the PCB.
8. Transfer the assembly to the stable, non-combustible reflow support without flexing the PCB.
9. If a preheater is available, warm the complete PCB gradually and evenly, staying within the solder-paste maker's preheat guidance.
10. Apply hot air at the lowest useful airflow. Keep the nozzle moving in broad, overlapping circles so that the region heats evenly.
11. Watch several visible joints in different parts of the heated region, especially beside the largest thermal masses. Start the timer when the first visible Sn63/Pb37 deposit becomes fully liquid.
12. Continue broad heating only until all inspected witness joints have flowed and nearby parts have pulled into alignment. Use the paste maker's time-above-liquidus guidance; do not extend the dwell merely to make exposed joints look smoother.
13. Withdraw heat gradually. Do not touch, bump, or move the board while any joint is shiny or mobile. After the last visible joint freezes, leave the board undisturbed for at least two minutes.
14. Inspect every visible joint under magnification. Do not underfill or glue the WROOM.

Visible edge wetting does not prove that the WROOM or SCH16T centre pads reflowed. If the paste never changes cleanly from a deposit into a mobile fillet, stop after cooling and diagnose the setup rather than repeatedly cooking the board.

## 4. Stencil and populate the front

1. Let the board cool fully before turning it over.
2. Use the stencil workaround to support only unused PCB edges. Leave at least 5 mm clearance beneath the WROOM and ensure nothing presses against the WROOM, IMU, switches, or FPC connector.
3. Confirm that the PCB cannot rock or bow during the print.
4. Stencil the front with fresh Sn63/Pb37 paste.
5. Inspect the UM980 and fine-pitch IC deposits especially carefully. Clean and reprint the whole side if critical deposits are defective.
6. Place the small components first.
7. Place U1 UM980, the microSD socket, U.FL receptacle, battery connector, and USB-C receptacle last.
8. Do not install the battery, microSD card, USB cable, antenna cable, display, or FPC cable.

The USB-C footprint does not provide paste for its four through-hole shell stakes. Reflow the fine SMT contacts during the front-side pass and solder the shell stakes afterward.

## 5. Reflow the front

This is the highest-risk step. Because Sn63/Pb37 melts at approximately 183 degrees C, the WROOM joints on the underside may remelt earlier and remain liquid longer than they would with SAC305. The board must remain horizontal, supported, and completely still.

1. Place the PCB front-side up on the tested reflow support. Ensure that there is open clearance beneath the WROOM and that no support touches any component.
2. Recheck stability using a cold, low-airflow pass before applying heat.
3. If a preheater is available, warm the whole PCB gradually and evenly according to the paste maker's guidance.
4. Apply the lowest useful airflow and use broad, overlapping circles over the front assembly area.
5. Heat the UM980 evenly. Never concentrate the air stream on one corner and never press the module while the solder is liquid.
6. Start the timer when the first visible Sn63/Pb37 deposit becomes fully liquid.
7. Stop active heating once visible joints across the slowest-heating areas have flowed and the paste maker's minimum time-above-liquidus guidance has been met. Keep the liquid interval as short as practical; extra dwell increases the chance that the underside WROOM will shift or fall.
8. Withdraw heat gradually without changing airflow in a way that can disturb components.
9. Do not touch, bump, rotate, or move the PCB while any joint is shiny or mobile. After the last visible joint freezes, leave the assembly undisturbed for at least two minutes.

No visual-only method can confirm the temperature or reflow state of the overlapping hidden joints. Shielding may reduce direct hot-air heating, but it cannot stop heat conducted through the PCB.

## 6. Finish the USB-C connector

After the PCB has completely cooled:

1. Apply a small amount of flux to the four USB-C shell stakes.
2. Use a sufficiently large soldering-iron tip to heat each stake quickly.
3. Use the solder-wire maker's recommended iron setting. Approximately 300-330 degrees C is a reasonable starting range for Sn63/Pb37 with an adequately sized tip; increase heat transfer by using a larger tip before increasing dwell time.
4. Complete each joint within a few seconds and allow the connector to cool between stakes if its body becomes warm.
5. Inspect the fine reflowed USB contacts for bridges.

Do not attempt to form the fine hidden USB contacts using only a soldering iron.

## 7. Inspection and initial power-up

Before connecting the battery:

1. Inspect both sides under magnification for shifted components, bridges, solder balls, opens, and WROOM movement during the second pass.
2. Check resistance from 3.3 V to ground and from VBUS to ground.
3. Check the USB pins for bridges.
4. X-ray U1, U2, and the leadless power ICs if that service is available. This is the only practical inspection of their hidden joints.
5. Power the board from a current-limited bench supply.
6. Confirm that the WROOM boots.
7. Confirm that the IMU responds over SPI.
8. Confirm communication with the UM980.
9. Confirm that USB enumerates.
10. Only then connect the microSD card, display/FPC, antenna, and battery.

Electrical function does not prove that every hidden joint is mechanically sound. Treat the result as a prototype unless the hidden joints have been inspected and the process has been validated.

## Stop conditions

Stop heating and allow the board to cool if:

- The support shifts, rocks, bows, softens, or starts to tip
- Components skate or blow out of position
- Flux smokes heavily or chars
- The PCB, connector bodies, or component packages discolor
- Visible paste remains grainy or balled after nearby joints have clearly flowed
- The WROOM moves during the front-side pass

Do not immediately reheat a failed area. Let the board cool, inspect the cause under magnification, clean the area if needed, and decide whether a controlled local rework is still credible.

## Production recommendation

For a repeatable or production-quality assembly, revise the placement so the UM980 and WROOM are on the same side, or use a PCBA vendor-developed selective process with thermocouples and X-ray inspection. A successful visual-only prototype run does not establish a safe production profile.

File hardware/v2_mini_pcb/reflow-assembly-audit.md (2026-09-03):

# v2_mini reflow and double-sided assembly audit

Date checked: 2026-08-29

Scope: the fitted items in [`production/digikey_bom.csv`](production/digikey_bom.csv) and their placement in [`v2_mini.kicad_pcb`](v2_mini.kicad_pcb). DNP capacitors C12/C24/C25/C26, mounting holes, bare test pads, and the no-fit Tag-Connect footprint are excluded.

## Short answer

Every component actually fitted by this BOM is an SMT/reflow-capable component. There is no fitted battery, battery holder, buzzer, through-hole-only switch, or other BOM item that is categorically forbidden from reflow.

The board is nevertheless **not compatible with an ordinary two-pass, same-alloy double-sided reflow process as presently placed**:

- U1 UM980 is on the front at `(105.12, 95.32)` and U2 ESP32-S31-WROOM-3 is on the back at `(97.67, 95.50)`. Their component outlines substantially overlap.
- Unicore says not to put the UM980 on the underside during reflow and does not recommend putting it through a soldering cycle twice.
- Espressif says to solder the WROOM module in a **single reflow**.
- Consequently, front-first makes the UM980 face downward and encounter a second hot cycle during the back pass; back-first gives the WROOM a second hot cycle during the front pass. Surface tension may hold a particular unit, but neither ordering follows both manufacturers' instructions. The UM980 manual's explicit warning is stronger evidence than a weight/contact-count estimate.

The robust production fix is to put both modules on one side or obtain a reviewed selective-reflow process from the module manufacturers/PCBA vendor. A handheld hot-air gun is particularly risky here because its airflow can move an underside component and because the two modules overlap thermally. If a prototype is attempted anyway, use a board preheater, thermocouples on both module bodies/pads, controlled low airflow, and X-ray inspection; treat it as an unqualified rework process, not as a repeatable assembly plan.

## Critical modules

| Ref / manufacturer part | PCB side | Reflow and moisture limits | Assembly decision |
|---|---:|---|---|
| U1 — Unicore **UM980**, 54-LGA, 17 × 22 × 2.6 mm, 1.88 g | Front | Bundled UM980 manual R1.9: ramp ≤3 °C/s; 150–180 °C for 60–120 s; >217 °C for 40–60 s; peak ≤245 °C; cool ≤4 °C/s. It explicitly says not to design/solder the module on the back of the PCB to prevent falling and does not recommend two soldering cycles. It recommends a 0.15 mm stencil. Vacuum packed with desiccant; the public manual does not give a numeric MSL. If baking is required, remove it from carrier packaging first because the packaging is limited to 55 °C, then follow the bag label/IPC handling. | Reflow only in a qualified process. Do not rely on it remaining attached upside-down in the WROOM-side pass. This is the highest mechanical/process risk on the board. Source: [Unicore product page and current manual download](https://en.unicore.com/products/um980/) and [the manufacturer manual bundled with this repo](../../data/datasheets/UM980_User%20Manual_EN_R1.9.pdf). |
| U2 — Espressif **ESP32-S31-WROOM-3-N16R16V**, 99-pad module, 22 × 30 × 3.5 mm | Back | MSL3; mount within 168 h after opening at ≤30 °C/60% RH. Bake if the 10% HIC spot indicates excess humidity or floor life is exceeded; remove from tape and follow J-STD-033. Espressif explicitly says **single reflow**, SAC305, 150–200 °C for 60–120 s, >217 °C for 60–90 s, peak 235–250 °C. Avoid ultrasonic cleaning/welding. | It is reflowable, but not qualified for a second reflow. It is an LGA-style module with many underside/perimeter pads, not something to finish with an iron. Sources: [ESP32-S31-WROOM-3 datasheet, Product Handling](https://documentation.espressif.com/esp32-s31-wroom-3_datasheet_en.html#product-handling) and [Espressif dry-pack rules](https://documentation.espressif.com/esp-packaging/en/latest/esp32s31/index.html). |
| U3 — Murata **SCH16T-K01-1**, 24-pin MEMS | Back | Reflowable SMD; MSL3. Murata says electrical performance is specified after 24 h from reflow and that assembly can affect accuracy. The exact assembly document APP10871 is controlled/restricted; the public datasheet does not publish a complete numeric oven profile. Ultrasonic agitation/cleaning is prohibited. | Reflow in the documented JEDEC/bag-label envelope, keep it dry, and do not use a concentrated hot-air blast or ultrasonic cleaner. Allow 24 h before precision calibration/acceptance testing. Sources: [Murata SCH16T series page](https://www.murata.com/en-us/products/sensor/gyro/overview/lineup/sch16t), [public SCH16T-K01 datasheet](https://www.murata.com/-/media/webrenewal/products/sensor/pdf/datasheet/datasheet-sch16t-k01-short.ashx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), and [bundled full datasheet](../../data/datasheets/sch16t-k01-datasheet-full.pdf). |

## Connectors and switches

| Ref / manufacturer part | Reflow status and limit | What to do |
|---|---|---|
| J1 — Hirose **U.FL-R-SMT-1(01)** | Reflowable. Hirose's U.FL profile gives a 250 °C maximum lead temperature, ≤10 s at peak, 130–180 °C preheat for ≤120 s, and at most two reflows. Manual touch-up is 350 °C for ≤5 s. | Reflow the receptacle. Attach the coax plug/cable only after the board has cooled. Do not use the cable to retain the connector. [Hirose U.FL catalog](https://www.hirose.com/en/product/document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) |
| J2 — Amphenol **GTFP08441BEU** microSD socket | Reflowable SMT, high-temperature thermoplastic. Official specification permits two reflows with peak 260 °C (+0/−10 °C) and 150–200 °C preheat for 60–120 s. | Reflow the empty socket. Insert the microSD card only after cooling/cleaning. [Product page](https://www.amphenol-cs.com/product/gtfp08441beu.html), [product specification](https://cdn.amphenol-cs.com/media/wysiwyg/files/documentation/ps-7500.pdf) |
| J3 — Amphenol **SFV24R-2STE1HLF** 24-way FPC connector | Manufacturer lists solder process **reflow**; the application specification recommends SAC305 and permits up to two reflows. | Reflow the connector with its latch closed and no FPC installed. Connect the display/ribbon only after cooling. It has no pick cap, which matters to machine assembly but does not make it hand-solder-only. [Product page](https://www.amphenol-cs.com/product/sfv24r2ste1hlf.html), [application specification](https://cdn.amphenol-cs.com/media/wysiwyg/files/drawing/bjm-sfv101.pdf) |
| J4 — Hirose **DF58-2P-1.2V(21)** battery connector | Reflowable SMT. 150–180 °C for 90–120 s; >220 °C for ≤60 s; peak 250 °C for ≤10 s. Manual touch-up 350 ±10 °C for ≤3 s. | Reflow the empty board connector. The BOM contains **no battery**; plug the Li-ion cell in only after assembly, inspection, and electrical checks. [Hirose DF58 catalog](https://www.hirose.com/en/product/document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) |
| J6 — GCT **USB4105-GF-A** USB-C | Designed for SMT contacts with through-hole shell stakes. GCT rates peak solder temperature 255 °C (−0/+5 °C) for ≤5 s. | Reflow the fine contacts. Because this footprint's shell stakes are through-hole, inspect them and hand-solder the stakes after reflow if the prototype stencil/process does not deposit solder there. Do not attempt to replace the hidden SMT-contact reflow with shell-stake solder alone. [GCT USB4105 page/specification](https://gct.co/connector/usb4105) |
| SW1–SW7 — Omron **B3U-1000P** | Reflowable. For B3U: preheat 150–180 °C, >220 °C for ≤60 s, peak 260 °C; at most two solderings, with ≥5 min between cycles. Published curve assumes a 1.6 mm PCB. Manual solder ≤350 °C for ≤3 s. | Reflow is normal. Do not use an automatic solder bath. Do not wash/immerse this non-sealed switch. [Omron switch soldering guidance](https://omronfs.omron.com/en_US/ecb/products/pdf/A306-E1.pdf) |

None of these connectors is a reason to leave the whole connector off until after reflow. The **mating items**—battery, USB cable, microSD card, FPC/display, and U.FL coax cable—must be installed after reflow.

## LED, temperature sensor, ICs, and other semiconductors

| BOM parts | Status |
|---|---|
| D32–D35 — ROHM **MSL0402RGBU1** RGB LEDs | Reflowable but not flow-solder guaranteed. MSL3, 168 h floor life. If expired/HIC indicates moisture, bake 60 ±3 °C for 40–48 h at <10% RH (ROHM recommends only one bake). Maximum two reflows; peak ≤250 °C, peak interval ≤10 s, 230–250 °C interval ≤40 s. The silicone lens is soft: do not press it or aim strong hot-air flow at it. [ROHM product page](https://www.rohm.com/products/led/chip-leds-multi-color-type/msl0402rgbu-product), [bundled manufacturer datasheet](../../data/datasheets/msl0402rgbu1-e.pdf) |
| TH1 — Murata **NCU18XH103F60RB** 0603 NTC | Standard reflowable chip thermistor. Use the NCU mounting profile/current manufacturer data and avoid excess dwell or repeated local heating. No reason to hand-install after reflow. [Murata NCU series](https://www.murata.com/en-us/products/thermistor/ntc/overview/lineup/ncu) |
| D1 **TPD1E0B04DPYR**, U5 **TCA9536ADTMR**, U6 **TPD4EUSB30DQAR**, U10 **TPS63802DLAR** | TI lists these packages as MSL1, 260 °C peak, unlimited floor life. Reflow normally; no bake when stored normally. [TI quality/package lookup](https://www.ti.com/quality-reliability-packaging-download/report?opn=TPD1E0B04DPYR) |
| D2 **ESDS311DYFR** | TI lists MSL3, 260 °C peak, 168 h floor life. Dry-pack handling/bake per bag label and J-STD-033 if expired. [TI quality/package lookup](https://www.ti.com/quality-reliability-packaging-download/report?opn=ESDS311DYFR) |
| U4 **LP5813ADRRR** | TI WSON-12, reflowable; TI lists the family/package as MSL1, 260 °C peak. [TI product/quality page](https://www.ti.com/product/LP5813/part-details/LP5813ADRRR) |
| U8 **BQ25622ERYKR** | TI lists MSL2, 260 °C peak, one-year floor life. Follow dry-pack label if the bag has been open longer. [TI quality/package lookup](https://www.ti.com/quality-reliability-packaging-download/report?opn=BQ25622ERYKR) |
| U7 **MAX16169AALTA+T**, U9 **MAX17048G+T10** | Pb-free leadless surface-mount packages intended for reflow. Follow the exact lot's ADI material declaration/reel MSL label and J-STD-020 profile; neither should be hand-installed after reflow. The BOM datasheets identify 6-LFCSP/µDFN and 8-TDFN-EP packages. [MAX16169 product page](https://www.analog.com/en/products/max16169.html), [MAX17048 product page](https://www.analog.com/en/products/max17048.html), [ADI package/MSL resources](https://www.analog.com/en/resources/packaging-quality-symbols-footprints/package-resources.html) |
| Q1 **NTNS3164NZT5G** | Pb-free SOT-883 intended for reflow; datasheet gives lead solder temperature 260 °C for 10 s. Use the reel label/J-STD-020 for MSL/profile. [onsemi datasheet](https://www.onsemi.com/download/data-sheet/pdf/ntns3164nz-d.pdf), [onsemi soldering and mounting manual](https://www.onsemi.com/pub/collateral/solderrm-d.pdf) |

## Passives

All remaining fitted BOM items are ordinary SMT chip passives and are intended for reflow. They are not candidates for “install after reflow.” This group covers every remaining manufacturer part number:

- MLCCs: Murata **GRM1555C1H101JA01D**, **GRM155R71E473KA88D**, **GRM188R61E475KE11D**, **GRT188R61A226ME13D**; Samsung **CL05B104KO5NNNC**, **CL10A106KP8NNND**, **CL05B104KB54PNC**, **CL05A105KA5NQNC**; TDK **C2012X5R1V106K125AC**; Yageo **CC0805MKX5R8BB226**; Taiyo Yuden **MCASG168AB7105KTNA01**. Murata identifies ordinary chip MLCCs as MSL1, representative of the normal no-bake handling for this class. [Murata MLCC MSL guidance](https://www.murata.com/support/faqs/capacitor/ceramiccapacitor/mnt/0009)
- Ferrites/inductors: TDK **MPZ2012S601ATD25**; Murata **LQW18AN68NJ00D**, **DFE252012F-1R0M=P2**; Samsung **CIGT201610EHR47MNE**. Reflow normally to the manufacturer's product-family profile; observe any dry-pack label rather than inventing a generic bake.
- Resistors: Yageo **RC0402FR-0710KL**, **RC0402FR-0715RL**, **RC0402FR-07100KL**, **RC0402FR-0722RL**, **RC0402FR-075K1L**, **RC0402FR-075K62L**, **RC0402FR-075K23L**, **RC0402FR-07499RL**, **RC0603FR-07511KL**, **RC0603FR-0791KL**, **RC0402FR-0722KL**; Vishay **CRCW040230K1FKED**; Stackpole **RMCF0402FT75K0**. These 0402/0603 thick-film chip resistors are standard reflow parts and do not need post-reflow installation.

The BOM's `FB1,FB2` value says `BLM21SP601SN1D`, but its specified manufacturer part is **MPZ2012S601ATD25**. Assembly/purchasing should follow the MPN, not the stale value text.

## Practical paste and sequence guidance

- Once a side has reflowed correctly, **do not apply new paste to its already-soldered joints** before heating the other side. New paste is for bare pads/components being placed; use flux only for actual rework.
- Do not treat pre-tinned bare pads as a substitute for a controlled paste deposit under the UM980 or WROOM. Their numerous hidden lands need controlled solder volume and inspection. Hand-dispensing a few blobs or heating until the edge “looks melted” cannot verify the centre joints.
- The USB-C receptacle, microSD socket, FPC connector, U.FL receptacle, DF58 board connector, and B3U switches should be populated during their side's controlled reflow, not saved for arbitrary hot-air attachment later.
- The only clear “install later” objects are mating/non-BOM items: Li-ion cell, microSD card, FPC/display, U.FL antenna cable, and USB cable.
- A second-side component falling is not determined by weight alone. Pad geometry, molten-solder surface tension, paste volume, component centre of gravity, time above liquidus, board vibration, and hot-air velocity all matter. Here the manufacturer-specific UM980 and WROOM cycle restrictions decide the process before a probability estimate does.

## Recommended disposition

1. For a repeatable build, revise placement so U1 and U2 are on the same side, then give both a single controlled SAC305 reflow inside the common window (peak not above the UM980's 245 °C limit, while satisfying the WROOM's 235–250 °C requirement).
2. If the PCB cannot change, send the exact stack-up, paste/alloy, and placement files to a PCBA vendor and require a written selective-reflow/rework plan with thermocouple evidence. Because U1/U2 overlap, “shield the other side” is not enough by itself.
3. Inspect hidden module joints by X-ray. Electrical boot/GNSS tests alone do not rule out voids, head-in-pillow/non-wet joints, or marginal ground-pad soldering.

## Source limitations

Connector and module manufacturers often do not assign a numeric MSL to non-plastic-IC products in public catalogues. Where no numeric MSL is published above, follow the delivered moisture-barrier bag/HIC label and the latest manufacturer revision rather than assuming MSL1. The current ESP32-S31-WROOM-3 datasheet is marked preliminary, so recheck it before production release.

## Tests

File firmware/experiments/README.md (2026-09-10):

# Archived bring-up experiments

These files preserve existing work and hardware evidence. Cargo does not
compile this directory. They are reference source, not runnable firmware targets.

- `trajectory.rs`: previous onboard trajectory adapter. The maintained engine
  remains in `traj/`; reintroduce an application integration through an explicit
  task and memory owner when needed.
- `power_diagnostic.rs`: former startup snapshot. The live battery monitor now
  owns charger/gauge reads, and board initialization owns I2C timeouts.

Historical behavior and results are in `../docs/trajectory-poc.md` and
`../docs/history/`. Current base firmware is documented in `../README.md`.

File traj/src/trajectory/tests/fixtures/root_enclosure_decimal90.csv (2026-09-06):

# Decimal90 oracle: case | s | then value/first/second for gate | spatial squared | horizontal squared | body signed | body squared
0 | 0.0 | -9.25000000000000058286708792820718372240662574768066406250000000000e-1 | 1.81799999999999998118171973260359654144153007323412003776775153511e+1 | -1.24355000000000001909028490842956505140095309279278919990000000000e+1 | 3.28978899999999999192024091598796085658165081623087343099931644607e+2 | -3.02013549999999994834204430915747113030664262363434818974652162832e+2 | 6.07115229499999987488395081225433743520758137709906582000000000000e+2 | 1.10498402418345713339788596965262875022873214994105162019799303351e+2 | -1.17859536289899098337078380467985362586302452459667803973640949748e+2 | 3.25855750596204266554752487283185520827545382206760020000000000000e+2 | -5.93999999999999996336264018736983416602015495300292968750000000000e+0 | 2.25639999999999997983834987280715722629480057187853394445383181813e+1 | -1.04036749999999985787424439109826465707884208000585909100000000000e+1 | 3.52835999999999995647481654259536312346155748818027048333943868640e+1 | -2.68060319999999995951425191265116169736120985884784594935683382488e+2 |
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

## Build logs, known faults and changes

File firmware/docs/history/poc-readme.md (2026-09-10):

> Historical snapshot before the base-firmware rebuild. Commands and source paths describe the former image.

# Trajectory speed proof of concept

See the [system and component reference](../v2-mini-system-reference.md) for
current firmware behavior, wiring, register settings, and operating policies.

The default `host-poc` image captures UM980 GNSS and SCH16T-K01 IMU data on
the connected Mini board and streams them over USB. Core 1 captures the
IMU; core 0 handles GNSS and USB. This is a development experiment, with
approximate timing and no board calibration. The host capture, live speed
display, and build/flash helper tools have been removed after bring-up.

The selected receiver profile requests **20 Hz standalone GNSS**, restoring
signal group 1. The 50 Hz experiment produced 50 messages/s but only one
valid standalone solution/s on this receiver; both position and velocity
were invalid between those fixes. There is no RTK correction source in this
test. `SINGLE` therefore means standalone positioning, not an RTK fix.

The IMU uses 1 MHz mode-0 SPI and factory-corrected 20-bit output. DEC5
provides a nominal 737.5 Hz native rate; averaging four consecutive samples
produces nominally 184.4 estimator intervals/s. The live test measured about
182 accepted intervals/s with 20 valid GNSS fixes/s. Profile details and source
documents are in [trajectory-poc.md](../trajectory-poc.md).

## Build

SW7 now powers off the board with a single click while the application is
running. The MAX16169 debounces the press and signals GPIO38; a separate
firmware task pulls GPIO8 (`PWR_KILL_N`) low to switch off the main 3.3 V rail,
including when powered over USB. The startup press is ignored for 100 ms so
turning the board on does not immediately turn it off. Holding SW7 for eight
seconds remains the hardware fallback if firmware is stalled or in ROM mode.
The current POC does not write onboard storage; add a storage flush before
asserting `PWR_KILL_N` when recording is introduced.

Run firmware builds from this directory so its target configuration applies:

```sh
cd firmware
cargo build --release
```

The ELF is written to
`../target/riscv32imafc-unknown-none-elf/release/aevia-firmware`.

`cargo build --release --features rtk-50hz` selects the optional group-8
50 Hz profile for tests with an RTK correction feed. The default build
restores the group-1 standalone profile on startup.

## Validation

The LCD driver writes an ST7789 bring-up pattern: six vertical color bars, a
white border, and a moving white marker along the bottom. SPI3 drives the panel
at 1 MHz independently of the IMU's SPI2. Bring-up is incomplete: the first
backlight-enabled image repeatedly restarted after its first frame. Keeping
the backlight off restored stable operation. The current image enables the
nominal 10% backlight setting after initialization and holds it on, as requested.
It stayed at `lcd-light=10` for a 15-second live check without a reset. Commands
`LCDLIGHT 1` and `LCDLIGHT 5` run five-second tests; `LCDLIGHT 10` stays on and
`LCDLIGHT 0` switches it off (terminate commands with newline). These three tests
stayed stable, but neither 4 MHz nor 1 MHz SPI produced valid panel readback or
TE pulses. After correcting the ribbon contact orientation, the LCD responds
with ID `8181b3`, but GPIO19/LCD_DC senses low even when its output latch is
high (`lcd-dc=4`, healthy value 5). The current firmware reports
`lcd=dc-stuck-low`, holds DC low and stops display writes, retaining 10%
backlight. A fresh retest with the LCD disconnected still reports `lcd-dc=4`,
pointing to the board-side circuit. With power removed, inspect and measure
J3 pin 10 and the GPIO19 net for a short to ground (J3 pin 11 is grounded).
The startup SCLK probe passed with the panel disconnected (`lcd-sclk=26`):
GPIO16 follows both weak pulls and both output levels. This argues against
a hard short to ground on SCLK. This probe repeats on reboot, not LCDREINIT.
`LCDREINIT` followed by newline
rechecks the pin and reinitializes the LCD if the pin passes.
USB STATUS includes `lcd`, `lcd-te`, `lcd-frames`, `lcd-light`, `lcd-id`,
`lcd-regs` and the chip reset reason;
`lcd=scanning` means the panel is returning TE frame pulses, not that the
visible image has been optically verified. See the system reference for wiring.

With the default firmware running on Windows, check live LCD feedback with
`powershell -NoProfile -ExecutionPolicy Bypass -File tools/check-lcd.ps1`
from the repository root (default COM5; override with `-Port`). The check
requires fresh USB status, advancing TE edges and completed frame writes;
visually confirm the pattern separately.

D32 now shows live battery status from [battery.rs](../../src/battery.rs):

| Colour | Meaning |
| --- | --- |
| Green | Charging, including when the battery is low |
| Blue | External power without confirmed charging (including a missing gauge/no cell) |
| Purple | Running on battery |
| Red | Running on battery at or below 15%; clears at 20% |
| Off | Starting, confirming a transition, or unable to establish valid status |

The monitor detects BQ25628E at `0x6A` or BQ25622E at `0x6B` and polls
the charger and MAX17048 about every 500 ms,
cross-checks charger power-good on GPIO40, validates gauge readings, and
waits at least one second for the gauge to settle. Two consecutive samples
confirm a colour. Failed readings immediately invalidate the corresponding
telemetry; USB reports samples older than three seconds as stale. Low-battery
hysteresis prevents flicker around the threshold. LED readback failures
disable D32 and retry after three seconds while battery polling continues.
D33-D35 remain off, and monitoring works independently of USB and GNSS.

USB `STATUS` and the onboard variant's `TRAJ` reports include `battery`,
`battery-pct`, `battery-mv` when valid, charger identity/registers, and
charger/gauge errors. `POWER` remains the saved startup diagnostic.
The battery module only reads: autonomous charging settings stay as documented
in the system reference. It does not implement battery protection or automatic
shutdown. Blue is a power-path indication, not a measurement of zero battery
current; a weak USB source can still need battery assistance. Stable gauge
readings reduce false detection but cannot prove a cell is physically present.

Run the battery policy tests from the repository root on Windows:

```powershell
rustc +1.95.0 --edition 2024 --test firmware/src/battery.rs -o target/battery-tests.exe
.\target\battery-tests.exe
```

The tests cover power transitions, all charge phases, fractional SOC thresholds,
missing/reconnecting gauges, voltage cycling, faults, stale data and recovery.
They do not replace checking colours and power transitions on the board.

The 2026-09-10 flash/live check identified BQ25622E (`0x1A`) at `0x6B`,
contrary to the earlier fitted-part note. Explicit two-byte gauge reads fixed
a burst-read issue that repeated VCELL in place of SOC. Charging and green LED
readback were verified with zero battery I2C errors. The connected gauge still
reported roughly 120% raw SOC, so `battery-pct` remains unknown and
`battery-gauge=soc-out-of-range`; valid voltage and charging status remain usable.
A voltage step briefly caused settling/off. Percentage accuracy and battery-only
transitions still need hardware validation. Ten host battery tests pass.
Repeat the live check with `powershell -NoProfile -ExecutionPolicy Bypass -File
tools/check-battery.ps1` from the repository root.

The following results were recorded before the host tools were removed.

The completed 45-second live capture after 10 seconds of warmup passed all
45 windows, with 20 valid GNSS fixes/s and about 182 accepted IMU intervals/s.
Fusion advanced with zero estimator resets, rejected IMU/GNSS observations
or wire parsing errors. All 440 trajectory tests and seven host tests also
passed, including predictor feedback and hard-reset regressions. This
validates the live data path; speed accuracy has not been checked against
an independent reference. Replay should use a fresh, continuous capture;
accuracy after long gaps or concatenated old sessions is unqualified.

## Onboard estimator experiment

`cargo build --release --no-default-features` runs the estimator on core 1
using the fitted 16 MiB PSRAM at 125 MHz. The startup fault was fixed on
2026-09-10: core 1 inherited a ROM memory-attribute region that permitted
reads but rejected PSRAM writes. [psram.rs](../../src/memory.rs) splits that region,
preserves flash read-only access, and grants read/write access only to PSRAM.
It checks the expected ROM layout and reads back the new attributes.

Before capturing measurements, startup tests all 16 MiB with two complementary
address-dependent patterns, writing back and invalidating the cache before
verification. `psram-tested=16MiB start-stage=8` in USB telemetry indicates
that the test and trajectory workspace initialization completed. Run the
hardware check from the repository root:

```powershell
powershell -NoProfile -ExecutionPolicy Bypass -File tools/check-psram.ps1
```

The check also requires advancing estimator IMU ingestion. Host tests for
the memory-region split and configuration checks run with:

```powershell
rustc +1.95.0 --edition 2024 --test firmware/src/psram.rs -o target/psram-tests.exe
.\target\psram-tests.exe
```

The board passed the full-memory test and started the onboard estimator.
GNSS had no valid fix during this check, so onboard fusion and speed output
remain unverified. The default build remains the USB-streaming `host-poc`.

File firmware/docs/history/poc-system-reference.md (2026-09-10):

> Historical hardware evidence and former firmware behavior. See [the current reference](../v2-mini-system-reference.md) for current ownership and commands.

# V2 Mini system and component reference

Checked against the firmware source on 2026-09-10. This document describes
current behavior, component wiring, register conventions, and the policies
that future drivers must preserve. Register reset values below are reference
values, not a claim that firmware programs or continuously verifies them.

Wiring and fitted-part notes are retained from the
[PCB](../../../hardware/v2_mini_pcb/v2_mini.kicad_pcb),
[production BOM](../../../hardware/v2_mini_pcb/production/digikey_bom.csv), and
[design note](../../../v2_mini_design.md). The fitted charger differs from the
BOM in the earlier notes. The 2026-09-10 connected board instead returned
BQ25622E identity `0x1A` at `0x6B`. The battery monitor supports both identities
and shares only status fields verified in both datasheets. Manufacturer references
are kept beside each component so register details can be traced directly.

## Current system and ownership

The default `host-poc` image captures GNSS and IMU measurements and streams
ASCII records over J6 USB. It does not compute onboard speed or write onboard
storage. The former host and flashing tools have been removed.

| Owner | Current responsibility | Implementation |
| --- | --- | --- |
| Startup on core 0 | GPIO setup, one power snapshot, UART/SPI/USB setup | [main.rs](../../src/main.rs) |
| Power diagnostic | Bounded read-only startup snapshot, then hand I2C0 to the battery task | [power_diagnostic.rs](../../experiments/power_diagnostic.rs) |
| Core 0 battery task | Poll charger/gauge and PG, publish live battery status, drive D32 on the same bus | [battery.rs](../../src/battery.rs), [led.rs](../../src/drivers/lp5813.rs) |
| Core 0 GNSS task | Configure UM980, parse BESTNAVA, enqueue raw records | [gnss_profile.rs](../../src/drivers/um980.rs), [gps.rs](../../src/gnss.rs) |
| Core 1 IMU task | Initialize SCH16T, validate and average native samples; 16 KiB stack | [imu.rs](../../src/imu.rs), [main.rs](../../src/main.rs) |
| Core 0 USB tasks | Measurement/status output, stream handshake, bootloader command | [main.rs](../../src/main.rs) |
| Independent core 0 shutdown task | SW7 shutdown | [main.rs](../../src/main.rs) |
| Independent core 0 LCD task | ST7789 color bars, animated marker and TE feedback | [lcd.rs](../../src/drivers/st7789.rs) |

The measurement channel holds 128 entries. Producers use `try_send`; a full
queue drops the new measurement and increments `queue-drops`. A blocked USB
reader therefore does not block capture. LED and shutdown tasks do not depend
on a USB reader. `capture-errors` counts sensor acquisition/parsing errors.

Building with `--no-default-features` moves acquisition to core 0 and runs
the estimator on core 1 with a 64 KiB stack and PSRAM workspace. The former
startup fault was a core-1 ROM memory-attribute region rejecting PSRAM stores.
[psram.rs](../../src/memory.rs) grants the fitted 16 MiB read/write access on the
estimator core while preserving read-only flash and unused address ranges.
It reserves PMA8..11, checks their initial state and verifies the changes.
This is specific to the observed S31 rev 0.0 ROM layout and pinned HAL;
different memory sizes/protection layouts are rejected. It does not configure
PSRAM permissions on core 0.

A destructive full-memory test runs at 125 MHz before workspace construction
and sensor capture. Two complementary address-dependent patterns are flushed
from cache and read back. Failure is reported as `psram-error`; success is
`psram-tested=16MiB`, followed by `start-stage=8` once the live session starts.
USB, battery and power-button tasks remain active during initialization.
Onboard IMU ingestion has been demonstrated; GNSS fusion and onboard speed
still need validation with a valid fix. See [trajectory experiment](../trajectory-poc.md).

## Operating policies

- Keep `PWR_KILL_N` released high using an open-drain output until SW7 requests
  shutdown. Ignore the startup press for 100 ms, wait for INT to be released,
  then shut down on its next falling edge. Keep CLR low until power is cut.
- Start with the LCD backlight off, then hold the requested 10% setting after
  panel initialization. The 1% and 5% diagnostic settings expire after five
  seconds; `LCDLIGHT 0` switches it off. Full-duty drive remains unqualified.
  D32 indicates battery status: green while charging, blue on external power
  without confirmed charging, purple on battery, red on battery at or below
  15% (clears at 20%). Unknown/transition states are off.
- Do not write charger settings, enable its ADC, clear its event flags, reset
  the fuel gauge, or issue QuickStart. The diagnostic and battery monitor only read.
  A future charger writer must explicitly own watchdog service or disable it.
- Use known 7-bit I2C addresses and device-specific byte order. No generic scan.
- Treat a missing gauge with no battery as an allowed power-state outcome.
  Its BAT supply can cycle; SOC without a cell is not meaningful.
- Charging is autonomous with CE grounded. Cell limits and the fitted
  thermistor curve remain prerequisites for choosing a charging policy.
- Reject invalid sensor data and expose drops/errors. Preserve GNSS solution
  validity separately from communication status and message rate.
- The current shutdown path has no storage to flush. Introduce a bounded
  storage flush before asserting CLR if recording is added; do not make
  shutdown wait for a USB reader.

## Fitted IC inventory

| Ref | Production part | Role | Firmware-visible interface |
| --- | --- | --- | --- |
| U1 | UM980 | GNSS/RTK receiver | Two UARTs, reset, PPS/status GPIO |
| U2 | ESP32-S31-WROOM-3-N16R16V | MCU module | RISC-V MCU; 16 MB flash and 16 MB PSRAM option |
| U3 | SCH16T-K01-1 | IMU | SPI, reset, data-ready |
| U4 | LP5813ADRRR | Four-channel RGB LED matrix driver | Power I2C plus `LED_EN` |
| U5 | TCA9536ADTMR | Four-input button expander | Power I2C |
| U6 | TPD4EUSB30DQAR | Four-channel USB/CC ESD protection | No registers |
| U7 | MAX16169AALTA+T | Pushbutton on/off controller | Power-latch GPIOs; no registers |
| U8 | BQ25628ERYKR fitted (`BQ628E` marking); schematic/BOM specifies BQ25622ERYKR | Buck battery charger and power path | Power I2C plus status/interrupt pins |
| U9 | MAX17048G+T10 | Single-cell fuel gauge | Power I2C plus alert |
| U10 | TPS63802DLAR | 3.3 V buck-boost converter | Hardware-configured; no registers |

The MCU/module interpretation is from the official preliminary
[ESP32-S31-WROOM-3 datasheet](https://documentation.espressif.com/esp32-s31-wroom-3_datasheet_en.html).
U1 and U3 are active acquisition peripherals in the default firmware.

## Power tree and reset behavior

```text
USB-C J6 VBUS ----> U8 BQ25628E VBUS
                         | BAT ----> J4 battery + ----> U9 MAX17048 CELL/VDD
                         | SYS ----> 3V3_RAW ----> U7 MAX16169 VCC
                                                \-> U10 TPS63802 VIN
U7 OUT / GATE_EN -------------------------------> U10 EN
U10 VOUT ----------------------------------------> +3V3
                                                   |-> MCU/UI/SD/display
                                                   |-> FB1 -> +3V3_GNSS
                                                   \-> FB2 -> +3V3_IMU
```

U10 is wired exactly as the 3.3 V fixed-divider example: `R25 = 511 kOhm`
from VOUT to FB and `R26 = 91 kOhm` from FB to ground, with a 0.47 uH
inductor. MODE is grounded, selecting automatic PFM/PWM; PG is not connected.
EN is driven by U7 and therefore is not left floating. See the official
[TPS63802 datasheet](https://www.ti.com/lit/ds/symlink/tps63802.pdf) and
[product page](https://www.ti.com/product/TPS63802).

U7 controls the main +3V3 rail even with USB connected. It starts with OUT
deasserted when VCC is first applied. SW7 must satisfy the 50 ms debounce
interval to turn the board on. The AALT option has 8 s long-press shutdown,
a 32 ms normal interrupt pulse, and a 128 ms long-press interrupt pulse.
Long-press shutdown remains available when application firmware is stalled
or the MCU is in ROM download mode. See the
[MAX16169 datasheet](https://www.analog.com/media/en/technical-documentation/data-sheets/max16169.pdf)
and [product page](https://www.analog.com/en/products/max16169.html).

The board fits `R8 = 10 kOhm` and `C11 = 100 nF` on MCU EN. Espressif's module
reference circuit recommends 10 kOhm and 1 uF, and specifies at least 1 ms for
both rail stabilization and the reset-low pulse. The electrical reset-ramp margin is not established by the firmware; retain
this component-value difference when investigating startup/reset failures.

## MCU management and programming pins

The frozen PCB maps the management and programming signals as follows. Numbers
are module pad numbers, followed by the ESP32-S31 GPIO/function.

| Module pad | MCU signal | Frozen-board net and connection | Current use |
| --- | --- | --- | --- |
| 3, 4 | 3V3 | +3V3 | Power |
| 5 | EN | 10 kOhm pull-up, 100 nF to GND, SW1 to GND | Reset input |
| 6 | GPIO2 | `BAT_ALRT_N`, MAX17048 ALERT, 10 kOhm pull-up | Input |
| 8 | GPIO0 | `CHG_INT_N`, BQ25628E INT, 10 kOhm pull-up | Input |
| 9 | GPIO1 | `CHG_STAT_N`, BQ25628E STAT, 10 kOhm pull-up | Input |
| 12 | GPIO6 | `POW_SCL`, 5.1 kOhm pull-up | I2C0 SCL |
| 13 | GPIO7 | `POW_SDA`, 5.1 kOhm pull-up | I2C0 SDA |
| 14 | GPIO8 | `PWR_KILL_N`, MAX16169 CLR, 10 kOhm pull-up | Open-drain output, released high; low for shutdown |
| 40 | dedicated USB_DP | J6 through 22 Ohm | USB-HS/OTG connector |
| 41 | dedicated USB_DM | J6 through 22 Ohm | USB-HS/OTG connector |
| 42 | GPIO33 / USB Serial/JTAG D- | J5 through 22 Ohm | Native debug USB |
| 43 | GPIO34 / USB Serial/JTAG D+ | J5 through 22 Ohm | Native debug USB |
| 44 | GPIO35 | `USB_VBUS_S`; 75 kOhm/100 kOhm VBUS divider | Input; 5 V gives about 2.86 V |
| 49 | GPIO38 | `PWR_INT_N`, MAX16169 INT, 10 kOhm pull-up | Input |
| 50 | GPIO39 | `LED_EN`, LP5813 EN | Output low initially |
| 51 | GPIO40 | `CHG_PG_N`, BQ25628E PG, 10 kOhm pull-up | Input |
| 68 | GPIO58 / UART0_TXD | TP2 through 499 Ohm | Auxiliary UART log output |
| 69 | GPIO59 / UART0_RXD | TP1 | Console input |
| 71 | GPIO61 | BOOT/SW2 to GND, 10 kOhm pull-up | Boot strap |

`GPIO4 / LCD_BACK` starts low, then continuously pulses at the nominal 10% setting.
`GPIO9 / IMU_RESET_N` is driven high except
during IMU initialization; `GPIO44 / GNSS_RESETN` is an input with pull-up.
Both reset nets also have board pull-ups. The battery task polls charger PG
on GPIO40; the other charger/gauge status pins and VBUS sensing remain unused.
J5 is the native USB Serial/JTAG port and J6 is the separate dedicated USB-HS/OTG port; they are not alternate
connectors for the same peripheral.

Normal SPI boot uses GPIO61 high. Joint Download mode uses GPIO61 low
and GPIO60 high: hold SW2, pulse SW1, restore the latch with SW7 if needed,
then release SW2. GPIO61 low with GPIO60 low is invalid. Software entry from
the application is described under USB below.

The original references differed on strapping pins: the preliminary
[module](https://documentation.espressif.com/esp32-s31-wroom-3_datasheet_en.html)
and [series datasheets](https://documentation.espressif.com/esp32-s31_datasheet_en.html)
listed GPIO36/37/60/61, while the
[GPIO documentation](https://docs.espressif.com/projects/esp-idf/en/latest/esp32s31/api-reference/peripherals/gpio.html)
listed GPIO36–40 and GPIO60–61. Preserve that discrepancy for reset-time
changes; application LED/shutdown operation does not resolve strap sampling.
The [boot-mode reference](https://docs.espressif.com/projects/esptool/en/latest/esp32s31/advanced-topics/boot-mode-selection.html)
and [serial connection reference](https://docs.espressif.com/projects/esp-idf/en/latest/esp32s31/get-started/establish-serial-connection.html)
provide the underlying programming interface details.

## Power I2C bus

The bus is `GPIO6 / POW_SCL` and `GPIO7 / POW_SDA`, with 5.1 kOhm pull-ups to
+3V3. The startup diagnostic configures 100 kHz, a 100-bus-cycle hardware
SCL timeout, and a 10 ms software transaction timeout. The battery task takes
ownership of the same bus after that snapshot and calls the LED driver;
there is no shared bus manager or concurrent I2C access.

| Device | 7-bit address | Current transactions |
| --- | ---: | --- |
| TCA9536A | `0x40` | No current driver or polling; register reference below |
| MAX17048 | `0x36` | Startup VERSION/VCELL; continuous VERSION and separate two-byte VCELL `0x02`, SOC `0x04` reads |
| BQ25628E | `0x6A` | Startup identity, status, external-limit bit, ADC controls; conditional ADC results. Continuous identity and status `0x1D..0x1F` |
| BQ25622E alternative | `0x6B` | Startup identity only. Live monitor validates PN=3 and reads status `0x1D..0x1F`, whose fields match in both Rev. C datasheets |
| LP5813A | `0x50..0x53` | Active LED configuration, PWM, and readback; pages of one device |

All addresses in firmware are 7-bit addresses; do not shift or append a read/
write bit. BQ25628E 16-bit registers place the low byte at the lower register
address. MAX17048 16-bit transfers are most-significant byte first. That byte
order difference should be explicit in separate device helpers.

## U8 BQ25628E charger and power path

### Frozen connections

| Pin | Signal | Frozen-board connection |
| ---: | --- | --- |
| 1 | BTST | 47 nF to SW |
| 2 | REGN | 4.7 uF to GND |
| 3 | active-low PG | `CHG_PG_N` -> GPIO40, 10 kOhm pull-up |
| 4 | ILIM | 5.62 kOhm to GND |
| 5, 6 | TS_BIAS, TS | 5.23 kOhm upper, TH1 and 30.1 kOhm lower network |
| 7 | QON | Not connected |
| 8 | BAT | Battery J4 pin 1 and MAX17048 CELL/VDD |
| 9 | SYS | `3V3_RAW` |
| 10 | active-low STAT | `CHG_STAT_N` -> GPIO1, 10 kOhm pull-up |
| 11 | active-low INT | `CHG_INT_N` -> GPIO0, 10 kOhm pull-up |
| 12, 13 | SDA, SCL | `POW_SDA`, `POW_SCL` |
| 14 | active-low CE | Grounded: autonomous charging enabled |
| 16 | SW | 1 uH to SYS |
| 17 | PMID | 100 nF and 10 uF to GND |
| 18 | VBUS | USB-C J6 VBUS |

The retained primary reference is the [BQ25628E datasheet, Rev. C](https://www.ti.com/lit/ds/symlink/bq25628e.pdf)
and [BQ25628E product page](https://www.ti.com/product/BQ25628E). The fitted
device is pin-compatible with this board connection set, but it is not
firmware-identical to the schematic/BOM's BQ25622E.

### Identity and startup snapshot

The recorded expected part-information byte at `0x38` is `0x22`: part number field
`PN[5:3] = 100` for BQ25628E and revision field `DEV_REV[2:0] = 010`. Require
the BQ25628E part-number field and log the revision so a newer silicon revision
is visible without being misidentified as a different part.

| Register | Meaning |
| ---: | --- |
| `0x1D` | Charger Status 0: ADC done, thermal regulation, VSYSMIN, IINDPM/ILIM, VINDPM, safety-timer and watchdog status |
| `0x1E` | Charger Status 1: charge phase and VBUS source classification |
| `0x1F` | Fault Status 0: VBUS, BAT, SYS, OTG, thermal shutdown, and TS-zone faults |
| `0x20..0x22` | Event flags; some clear when read, so do not use them as the only retained diagnostic |
| `0x38` | Part Information; expected `0x22` |

In `0x1E`, `CHG_STAT[4:3]` means no charge/terminated, constant-current,
constant-voltage, or top-off for values `00..11`. `VBUS_STAT[2:0]` is `000` for
no input and `100` for an unknown/default source on BQ25628E. In
`0x1F`, a TS value of zero is the normal zone.

### Hardware defaults and write policy

| Register bytes | Reset value | Decoded reset behavior |
| --- | ---: | --- |
| `0x02..0x03` | `0x0100` | ICHG = 320 mA (`0x08 * 40 mA`) |
| `0x04..0x05` | `0x0D20` | VREG = 4.200 V (`0x1A4 * 10 mV`) |
| `0x06..0x07` | `0x0A00` | IINDPM = 3.200 A (`0xA0 * 20 mA`) |
| `0x08..0x09` | `0x0E60` | VINDPM = 4.600 V |
| `0x0E..0x0F` | `0x0B00` | VSYSMIN = 3.520 V |
| `0x10..0x11` | `0x0018` | Precharge current = 30 mA |
| `0x12..0x13` | `0x0010` | Termination current = 20 mA |
| `0x14` | `0x06` | Termination enabled; input-voltage battery tracking enabled |
| `0x16` | `0xA1` | Auto battery discharge and charging enabled; 50 s watchdog selected |

The 5.62 kOhm ILIM resistor imposes about 445 mA typical input-current limit
using the datasheet's 2500 A-Ohm typical coefficient (about 400-489 mA over its
2250-2750 range). The effective limit is the lower of this hardware limit and
IINDPM. On BQ25628E, `REG0x19.EN_EXTILIM` bit 2 defaults enabled; read the bit
rather than assuming the whole reset byte because the family-wide register
table also describes variants without the external-limit feature.

Most importantly, the charger starts in autonomous/default mode after POR. A
write to any register enters host mode and starts the selected watchdog. If the
host does not periodically set `WD_RST` before the 50 s reset interval—or first
explicitly disables the watchdog—the device restores applicable defaults,
halves ICHG, and asserts an interrupt. Therefore the current firmware performs
no BQ writes, including no ADC-enable write. A later driver must make watchdog
ownership an explicit state transition.

ADC control is at `0x26`, channel disable bits at `0x27`; results begin at
`0x28` (IBUS), `0x2A` (IBAT), `0x2C` (VBUS), `0x2E` (PMID), `0x30` (VBAT),
`0x32` (VSYS), `0x34` (TS), and `0x36` (die temperature). Results use
16-bit little-endian transfers. Firmware does not enable the ADC.

The startup diagnostic reads `0x1D..0x1F`, stopping before read-to-clear
flags at `0x20..0x22`, then reads `0x19` bit 2 and `0x26..0x27`.
It reports ADC results only when `(REG26 & 0xC0) == 0x80` (continuous ADC
already enabled) and the corresponding channel is enabled:

| Result | Gate and decode used by firmware |
| --- | --- |
| VSYS `0x32` | `REG27 & 0x08 == 0`; `((raw >> 1) & 0x0FFF) * 199 / 100` mV, integer arithmetic |
| IBAT `0x2A` | `REG27 & 0x40 == 0`; signed 16-bit raw, `(raw >> 2) * 4` mA; `0x8000` means aborted |

Disabled/one-shot ADC contents are not presented as current measurements.
`POWER` output is a **startup snapshot**: USB repeats the saved text every
10 seconds in `host-poc`; it does not resample charger or battery state.
Live readings are separate `battery-*` fields in `STATUS` (or `TRAJ` in the
onboard variant), populated by the independent battery task.

### Continuous battery monitor

[battery.rs](../../src/battery.rs) samples about every 500 ms, rechecks the
detected BQ25628E/BQ25622E identity, and compares `VBUS_STAT` against active-low PG
before and after I2C reads. Source disagreement, unsupported identity,
charging faults or bus failures produce unknown status instead of green.
The monitor never reads the event flags or changes the charger configuration.

The gauge must return VERSION `0x001_`, VCELL in 2500-4500 mV and plausible
SOC. SOC above 100% up to 110% is clamped to 100%; larger values leave
percentage unknown with `soc-out-of-range`, while voltage and charging remain
usable. `battery-soc-raw` preserves the raw SOC word for diagnosis.
The gauge is withheld for at least one second after startup, a failed read,
a sample gap of three seconds, or a voltage step exceeding 200 mV. Empty
J4 can pulse the gauge supply, so these checks reduce false indications but
do not prove physical cell presence. The detected charger address is retained
between polls, avoiding repeated probes of an absent device, and invalidated
on read failure. With external power and a NACKing gauge,
blue is allowed and percentage is unknown. On battery, missing gauge data
leaves the LED off because low-charge status cannot be determined.

Two consecutive samples confirm each colour; transitions are off until
confirmed. Red enters at SOC <=15% and stays latched until SOC >=20%, using
the unrounded gauge value. Charging takes precedence over low charge.
Telemetry invalidates failed readings immediately and reports snapshots older
than three seconds as stale. All reads retry on the next poll. No automatic
shutdown, charge-current policy, or fuel-gauge calibration is introduced.
Blue means external power without confirmed charging; without enabling the
charger ADC this cannot distinguish battery supplementation of a weak input.

On 2026-09-10 the connected board reported BQ25622E `0x1A` at `0x6B` and
MAX17048 version `0x0012`. Four-byte gauge reads repeated the voltage word;
separate register-addressed two-byte reads fixed that transport error. The
gauge's actual SOC register remained near 120%, so percentage accuracy is
unqualified. The flashed image reported charging/green and zero battery I2C
errors in the live check, with one brief voltage-step settling/off interval.
Use [check-battery.ps1](../../../tools/check-battery.ps1) for fresh USB status checks.

### Battery/thermistor safety hold

TH1's production-BOM part is Murata `NCU18XH103F60RB`, while the KiCad value
text still says `103KT1608T-1P`. TI's shown 5.23 kOhm/30.1 kOhm network and
default TS thresholds are designed around the 103AT curve. The intended cell,
its maximum charge voltage/current, and the fitted Murata curve must be checked
together before charging a battery. Until these are established, retain the
no-cell policy. A software current setting cannot protect against an unsuitable default already active before
firmware starts.

## U9 MAX17048 fuel gauge

U9 pins 2 (CELL) and 3 (VDD) connect directly to BAT, pins 4 and exposed pad to
ground, and pin 5 ALERT connects to `BAT_ALRT_N / GPIO2` with a 10 kOhm +3V3
pull-up. QSTRT is grounded. SDA/SCL are power I2C. With charging enabled and no
cell, BQ25628E battery detection can cycle BAT between its recharge and
regulation thresholds. The gauge can therefore ACK while BAT is high or NACK
while it droops; neither outcome alone proves a gauge fault. Treat empty J4's
BAT pin as live and measure it. TI describes this behavior in
[Battery Detection Using Single Cell Charger (Rev. A)](https://www.ti.com/lit/ab/sluab31a/sluab31a.pdf).

The datasheet denotes fixed bus bytes `0x6C` for write and `0x6D` for read; the
corresponding standard 7-bit address required by `embedded-hal` is `0x36`.
Registers are 16-bit and transferred most-significant byte first. The current
startup diagnostic reads VERSION and VCELL; the battery monitor also reads
SOC continuously. The other registers below are retained for future gauge
work. VCELL output uses `(raw * 5 + 32) / 64` rounded mV.

| Register | Reference interpretation |
| ---: | --- |
| `0x02` VCELL | Raw value * 78.125 uV |
| `0x04` SOC | Raw value / 256 percent; allow about 1 s after POR for first estimate |
| `0x08` VERSION | Read-only silicon/version presence check |
| `0x0A` HIBRT | Reset `0x8030` |
| `0x0C` CONFIG | Reset `0x971C`; includes RCOMP, sleep, alert latch and SOC threshold |
| `0x14` VALRT | Reset `0x00FF`, thresholds in 20 mV units |
| `0x16` CRATE | Battery percentage change rate, 0.208 percent/hour per LSB—not amperes |
| `0x1A` STATUS | POR and alert status |

ALERT is open drain and remains asserted until `CONFIG.ALRT` is cleared. Do not
issue QuickStart (`MODE 0x06`) or the POR command (`0x5400` to `0xFE`) in the
current firmware. Analog Devices says most applications should not use
QuickStart; it is only meaningful when the cell voltage is relaxed. See the official
[MAX17048/MAX17049 datasheet](https://www.analog.com/media/en/technical-documentation/data-sheets/max17048-max17049.pdf)
and [MAX17048 product page](https://www.analog.com/en/products/max17048.html).

## U5 TCA9536A button expander

The exact fitted suffix matters: `TCA9536A` has 7-bit address `0x40`. The plain
TCA9536 uses a different address. The four active-low buttons are:

| Expander pin | Port | Frozen-board switch |
| ---: | --- | --- |
| 1 | P0 | SW3 to GND |
| 8 | P1 | SW6 to GND |
| 2 | P2 | SW4 to GND |
| 4 | P3 | SW5 to GND |

There are no external button pull-ups. At reset all ports are inputs with the
approximately 100 kOhm internal pull-ups enabled, so input register `0x00`
should have low nibble `0xF` when no button is pressed and clear the associated
bit when pressed. Its upper nibble reads as ones.

| Register | Reset | Meaning |
| ---: | ---: | --- |
| `0x00` | input | Input port |
| `0x01` | `0xFF` | Output port |
| `0x02` | `0x00` | Polarity inversion |
| `0x03` | `0xFF` | Configuration: all inputs |
| `0x50` | `0x00` | Special function; P3 interrupt and pull-disable both off |

The current firmware leaves the expander untouched, including special-function
register `0x50`. Future button handling must preserve input mode and pull-ups
unless it deliberately takes ownership of those functions. See the
official [TCA9536 datasheet](https://www.ti.com/lit/ds/symlink/tca9536.pdf) and
[product page](https://www.ti.com/product/TCA9536).

## U4 LP5813A LED matrix driver

VIN is +3V3, EN is `GPIO39 / LED_EN`, SYNC is grounded, SW uses the fitted 1 uH
inductor, and VOUT has 22 uF. The `A` address option uses address bits `00`.
Because the high two register-address bits are encoded into the I2C slave
address, its four 256-byte pages appear as 7-bit addresses `0x50`, `0x51`,
`0x52`, and `0x53`; the transaction's register byte supplies the low eight
bits. This is not four physical devices.

The exact charlieplexed LED mapping is:

| Driver output | Anode group | Cathodes by color |
| --- | --- | --- |
| OUT0 | all anodes of D32 | D33 red, D34 green, D35 blue |
| OUT1 | all anodes of D35 | D32 green, D33 blue, D34 red |
| OUT2 | all anodes of D33 | D32 red, D34 blue, D35 green |
| OUT3 | all anodes of D34 | D32 blue, D33 green, D35 red |

### Active D32 configuration

EN low is shutdown. The task holds EN low for 10 ms, then high for 10 ms
before initialization. It enables the chip, waits 10 ms, writes configuration
and `CMD_UPDATE`, then waits another 10 ms before checking readback.

| Full register | Written value | Purpose in current driver |
| --- | --- | --- |
| `0x000` | `0x01` | Chip enable |
| `0x002` | `0x40` | Proven four-scan setup, 3 V target / 3.3 V pass-through |
| `0x003` | `0xE4` | Output mapping configuration |
| `0x00D` | `0x0B` | TI recommended short-detection threshold to avoid false shorts |
| `0x010` | `0x55` | Apply configuration (`CMD_UPDATE`) |
| `0x034..0x036` | `20` decimal | D32 green/red/blue current, 2 mA peak |
| `0x020`, `0x021` | `0x70`, `0x00` | Enable only D32 green, red and blue channels |
| `0x044..0x046` | Green: `128,0,0`; blue: `0,0,128`; purple: `0,128,128`; red: `0,128,0`; unknown: all zero | D32 A0 green, A1 red, A2 blue PWM |

Quarter scan and PWM 128 produce the low-brightness steady indicator.
D33–D35 remain off; there is no LED test mode. Configuration
readback requires `0x000..0x003 = [1,0,0x40,0xE4]`, `0x00D = 0x0B`, and
`0x300..0x304 = 0`. Color changes wait 10 ms and verify all 12 PWM bytes,
both enable bytes, and the five fault/status bytes. The same checks run on
every battery poll even if the colour is steady. Any I2C, readback, or fault
failure disables EN and reports an error through `STATUS led=...`. The driver
retries the full sequence after three seconds while battery polling continues.

References: [LP5813 datasheet](https://www.ti.com/lit/ds/symlink/lp5813.pdf),
[register-map guide](https://www.ti.com/lit/ug/snvu859/snvu859.pdf),
[sample-code guide](https://www.ti.com/lit/ug/snvu940/snvu940.pdf), and
[product page](https://www.ti.com/product/LP5813).

## U7 MAX16169 pushbutton controller

| U7 pin | Signal | Frozen-board connection |
| ---: | --- | --- |
| 1 | VCC | `3V3_RAW` |
| 2 | GND | Ground |
| 3 | active-low PB_IN | SW7 to ground |
| 4 | active-low CLR | `PWR_KILL_N / GPIO8`, 10 kOhm pull-up |
| 5 | active-low open-drain INT | `PWR_INT_N / GPIO38`, 10 kOhm pull-up |
| 6 | OUT | `GATE_EN` -> TPS63802 EN |

There are no registers. CLR low turns OUT off, but CLR is ignored while OUT is
already deasserted and during the protected interval immediately after turn-on.
The application arms shutdown after 100 ms (longer than the documented
maximum 76.8 ms startup CLR blanking interval), waits for INT high, then its
next low. It asserts GPIO8 low indefinitely. A single subsequent press cuts
the main rail, including under USB power. No storage flush is currently needed;
the long-press hardware path remains independent of the MCU.

## U6 TPD4EUSB30 USB/CC protection

U6 is passive and has no firmware interface. Its paired pins protect USB DN
(pins 1/10), USB DP (2/9), CC1 (4/7), and CC2 (5/6); pins 3 and 8 are ground.
J6 USB DP and DM each have a 22 Ohm MCU series resistor. CC1 and CC2 each have
5.1 kOhm Rd to ground at the connector and a 22 kOhm series path to MCU sensing
GPIO43 and GPIO45. This confirms J6 advertises a USB device/sink role at the CC
pins. See the official [TPD4EUSB30 datasheet](https://www.ti.com/lit/ds/symlink/tpd4eusb30.pdf)
and [product page](https://www.ti.com/product/TPD4EUSB30).

## U1 UM980 GNSS

| MCU peripheral/pin | Receiver connection |
| --- | --- |
| UART1 TX GPIO47 / RX GPIO46 | COM1 command path, 115200 baud for default setup |
| UART2 TX GPIO49 / RX GPIO48 | COM2 data path, initially 115200 then 460800 baud, 8N1 |
| GPIO44 | Reset released with pull-up; no hardware reset during configuration |

The default profile first proves the COM1 transmit → receiver → COM2 receive
path with `VERSIONA COM2`, trying COM2 at 115200 and 460800 to tolerate a
previous volatile setting. A working COM1 receive/acknowledgement path is not
required for this route. Commands are sent as complete CRLF-terminated lines;
yielding between command text and CRLF previously risked receiver timeouts.

The applied profile is:

```text
CONFIG SIGNALGROUP 1
UNLOG COM1
UNLOG COM2
MODE ROVER AUTOMOTIVE
CONFIG PVTALG AUTO
CONFIG ANTIJAM AUTO
CONFIG COM2 460800
BESTNAVA COM2 0.05
```

`SIGNALGROUP` saves itself and restarts the receiver when changed. The driver
waits three seconds and reprobes before sending the rest; other runtime
settings are volatile and no `SAVECONFIG` is sent. Startup requires ten
consecutive 50 ms receiver epoch steps with valid position and velocity within
an eight-second verification window. Without sufficient valid fixes, setup
can keep retrying; this is not by itself evidence of a UART failure.

Setup errors retry after three seconds. During capture, a three-second UART
read timeout restarts configuration. BESTNAVA status parsing checks CRC and
updates communication status even when the receiver has no solution. The raw
host stream can contain BESTNAVA lines rejected by the parser; a consumer must
validate them itself. `SINGLE` is standalone positioning, `NARROW_FLOAT` RTK
float, and `NARROW_INT` fixed RTK.

`--features rtk-50hz` selects signal group 8 and `BESTNAVA COM2 0.02`.
That path also has command-baud discovery and COM2-command fallbacks; see
[gnss_profile.rs](../../src/drivers/um980.rs). Group 8 produced 50 messages/s but
only one valid standalone solution/s on the tested receiver. Message rate
must not be substituted for valid solution rate. The default group-1 profile
produced 20 valid fixes/s. No correction source is configured by this firmware.

References: [N4 R1.14 command manual](https://en.unicorecomm.com/uploads/file/Unicore%20Reference%20Commands%20Manual%20For%20N4%20High%20Precision%20Products_V2_EN_R1.14.pdf),
[N4 R1.4 manual, page 43, standalone/group-8 limits](https://en.unicorecomm.com/uploads/file/20241219/Unicore_Reference_Commands_Manual_For_N4_High_Precision_Products_V2_EN_R1.4.pdf),
and [experiment details](../trajectory-poc.md).

## U3 SCH16T-K01 IMU

SPI2 uses mode 0, 1 MHz, MSB-first 48-bit SafeSPI frames. GPIO12 is SCK,
GPIO11 MOSI, GPIO13 MISO, GPIO10 software CS, GPIO9 active-low reset, and
GPIO14 active-high data-ready. CS is high between frames, with 1 µs delays
before/after assertion and before deassertion. Replies correspond to the
previous request; reads use `FREQ_CNTR` (`0x13`) to clock out pending replies.

### Register image and startup

These are the exact volatile register values in [imu.rs](../../src/imu.rs).
The profile selects LPF3 Bessel, DYN1 calibrated ranges, and DEC5 on all
decimated axes. It retains continuous and startup self-tests.

| Register(s) | Value | Use |
| --- | --- | --- |
| `0x25..0x27` | `0x00DB` each | Axis filter profile |
| `0x28..0x29` | `0x1324` each | Axis range/decimation profile |
| `0x2A..0x2E` | `0x0000` each | Remaining profile controls |
| `0x33` | `0x202C` | 3.3 V, normal slew, active-high data-ready |
| `0x34` | `0x0FFE` | Continuous/startup self-tests enabled |
| `0x35` CTRL_MODE | `1`, then `3` | Mode transition / end of initialization |
| `0x37` SYS_TEST | `0x5A3C`, then `0` | Write/readback interface check |
| `0x3C` COMP_ID | Expected `0x0023` | Required component identity |
| `0x3B` ASIC ID | Require `(value & 0x0F00) == 0` | ASIC identity check |
| `0x14..0x1D` | Healthy `0xFFFF` each | Ten diagnostic status words |
| `0x0A..0x0F` | Read | Decimated gyro XYZ, then accelerometer XYZ |

Startup asserts reset for 2 ms and waits 32 ms after release with SCK low.
It checks identity and SYS_TEST, writes and verifies the profile, writes
CTRL_MODE=1, and waits 215 ms. It reads latched startup status, writes
CTRL_MODE=3, waits 3 ms, and retires the pre-delay pipelined reply. It requires
two wholly healthy diagnostic passes within ten attempts, waiting 3 ms
between attempts so asynchronous fault clearing can finish. Then it enables
strict frame-status checks and re-verifies the profile, mode, and identity.
An initialization call tries up to five times; task-level failures wait two
seconds before starting another call.

### Measurement and rejection policy

Native output is nominally 737.5 Hz; four consecutive six-axis sets are
averaged into nominally 184.4 intervals/s (about 182/s observed). The first
set establishes a time/counter baseline. The six 4-bit counters can have
different offsets: each must advance by one modulo 16, rather than equal
its neighbors. Each native interval must be 500–2800 µs; data-ready waits
are bounded to 100 ms. These checks detect missed samples and gaps that a
complete counter wrap might hide.

Frames use augmented CRC-8 (initial `0xFF`, polynomial `0x2F`, processing the
40 message bits plus eight zero bits). Response address, command/status,
and frame format are checked. Measurement payloads are signed 20-bit values
in bits 27:8. Acceleration scales by 3200 LSB/(m/s²); gyro scales by
1600 LSB/(°/s) and is converted to rad/s. Values outside ±80 m/s² or ±300°/s
are rejected even if within electrical output headroom.

Any bad native set discards the complete four-set batch. The six-response
pipeline is drained even on a bad burst so data-ready can rearm. Ten
consecutive acquisition errors trigger reinitialization. Successful samples
reset that error streak; the last error remains available in status output.

Timestamps are MCU monotonic microseconds taken when software services
data-ready; an output timestamp marks the interval end. Factory correction
is active, but assembled-board calibration, boresight, filter-delay correction,
and high-rate coning/sculling compensation are not implemented. Nominal
LPF3 bandwidths are 280 Hz gyro and 240 Hz acceleration.

Reference: [Murata Doc. 11624 Rev. 6, sections 5–7](../../../data/datasheets/sch16t-k01-datasheet-full.pdf).
Preserve the startup delays, pipelined response handling, and diagnostic
clearing sequence when changing acquisition; identity reads alone do not
establish readiness.

## J3 LCD bring-up

Latest hardware finding: after correcting ribbon orientation, readback gives
ID `8181b3`. Commands wake the panel (`lcd-init=98000680`), but MADCTL/COLMOD
remain at defaults; pixel transfers reset it (`lcd-regs=0c000600`). Both FIFO
parameter writes and hardware-command-phase parameter writes behave the same.
GPIO19 input feedback is low with its output latch high: `lcd-dc=4` versus
healthy value 5 (bit 2: high output latch, bit 1: input while driven low,
bit 0: input while driven high). This is consistent with the LCD treating data
as commands because LCD_DC cannot rise. After the user disconnected the LCD,
a fresh STREAM handshake and LCDREINIT produced seven status samples with
`lcd-dc=4`, `lcd-id=000000`, and `lcd-regs=00ff0000`. The fault persists without
the panel, pointing to the board-side GPIO19 circuit. The physical cause is
not established. With board power removed, inspect and measure J3 pin 10
(GPIO19, module pad 25) to ground, including a possible bridge to adjacent
grounded J3 pin 11. A short, GPIO damage, and pin configuration remain to be
distinguished by measurement.

A subsequent startup probe of LCD_SCLK (GPIO16, J3 pin 9), with the LCD still
disconnected, passed: `lcd-sclk=26`. Before SPI routing, the pin followed weak
pull-down and pull-up, then sampled low and high during brief output tests.
This argues against a hard SCLK-to-ground short at the MCU; it does not measure
resistance or prove continuity to the connector. DC still reported `lcd-dc=4`.
The SCLK diagnostic runs once per boot. Its bit flags are: bit 0 pull-down
input, bit 1 pull-up input, bit 2 driven-low input, bit 3 driven-high input,
bit 4 output test performed. Output testing is skipped if either pull test
fails. A failed probe leaves SCLK undriven and reports `sclk-check-failed`;
reboot after repair to repeat this startup check.

The current startup checks DC before initialization. A failed check reports
`lcd=dc-stuck-low`, leaves DC low, stops frame writes, and retains the requested
10% backlight. Six consecutive USB status samples confirmed this state without
resets or sensor errors. `LCDREINIT\n` manually repeats the GPIO check and LCD
initialization. No automatic loop drives the fault high. A passing startup
captures register state before and after the first frame as `lcd-init` and
`lcd-regs`; these are snapshots, not continuous polling.

J3's SFV24R-2STE1HLF is **top contact**, despite Adafruit's contradictory
bottom-contact description of that part. The exposed ribbon conductors face
away from the PCB toward the upper contacts, with pin numbering preserved.
See [Amphenol drawing 10171070, sheet 4](https://mm.digikey.com/Volume0/opasdata/d220001/medias/docus/6255/10171070.pdf).

The Adafruit 4520 is a 240x240 ST7789VW panel. J3 pin 6 is tied high to select
4-wire SPI; panel analog and I/O supplies are 3.3 V. Panel pin 1 (LEDA) is
3.3 V, and pin 2 (LEDK) returns through R4 (15 ohms) and Q1 to ground.
GPIO4 drives Q1, so high enables the backlight.

| Signal | MCU GPIO | J3 pin |
| --- | ---: | ---: |
| Reset, active low | 15 | 7 |
| CS, active low | 18 | 8 |
| SCLK | 16 | 9 |
| Data/command | 19 | 10 |
| SDA/MOSI | 17 | 12 |
| TE frame output | 5 (input with pull-down) | 21 |

[lcd.rs](../../src/drivers/st7789.rs) owns SPI3 at 1 MHz, mode 0, MSB first. It applies
hardware and software reset, sleep-out, RGB565, MADCTL 0xC0, inversion on,
normal mode and vertical-blank TE output. The visible window is columns
0..239 and rows 80..319 (Adafruit rotation 0). After writing the first frame,
it enables the display and selects the persistent nominal 10% backlight setting.
Subsequent frames write six color bars,
a white border and a moving white marker. Each 480-byte row yields to other
core-0 work. No framebuffer or PSRAM is needed.

USB STATUS reports `lcd=scanning` after at least five rising TE edges in a
half-second observation window, or `lcd=no-te` otherwise. `lcd-te` counts
observed edges (excluding drawing time), and `lcd-frames` counts completed
frame writes. These prove controller activity and completed SPI transfers;
the visible colors, orientation and backlight still require visual inspection.
SPI errors disable the backlight and retry initialization after three seconds.

Bring-up on 2026-09-09 is incomplete. The first image reported
`lcd=initializing lcd-te=0 lcd-frames=1` before USB disconnected, and the user
confirmed a restart loop. Holding GPIO4 low restored stable operation, confirmed
by the user and advancing frame counts over USB. Manual `LCDLIGHT 1`,
`LCDLIGHT 5` and `LCDLIGHT 10` tests all completed without a reset. These use
10/50/100 microsecond GPIO pulses with at least 1 ms low time; scheduling makes
them duty ceilings, not calibrated brightness. At the user's request the 10%
setting now stays on after initialization and has no timeout. A 15-second live
check kept `lcd-light=10` throughout with advancing frames and no reset. The 1%
and 5% settings still expire after five seconds. The S31 LEDC driver is unavailable
in the pinned HAL.

The panel returns no TE pulses at 4 MHz or 1 MHz. Shared-SDA half-duplex reads
report ID `000000` and packed power/MADCTL/COLMOD/signal bytes `00ff0000`, which
do not match the programmed state. RDDID uses one dummy clock; the four
single-byte register reads use none (ST7789VW section 8.4.5). These observations
do not establish a responding panel. Visual and electrical checks remain.
Release build and formatting pass; strict Clippy has pre-existing diagnostics
outside lcd.rs.

The reliable flashing sequence uses the RAM stub: first send `BOOTLOADER\n`
on application COM5, then use `espflash flash --port COM4 --chip esp32s31
--before no-reset --after no-reset-no-stub --flash-size 16mb --non-interactive
--skip-update-check <ELF>` and run `tools/s31-reset/target/release/s31-reset.exe
COM4`. Build that helper from its own directory with `cargo build --release`.
Two successive flashes and software restarts passed with this sequence.
The ROM-only `--no-stub` path failed at FlashEnd and required SW7 recovery;
the espflash CLI's watchdog-reset dispatch also lacks S31 support, although
the library method called by the helper supports it.

References: [panel specification](../../../data/datasheets/4520_C13462__________.pdf),
[Adafruit product](https://www.adafruit.com/product/4520), and
[Adafruit initialization and offsets](https://github.com/adafruit/Adafruit-ST7735-Library/blob/master/Adafruit_ST7789.cpp).

## USB protocol and programming

J6 uses the dedicated USB-HS controller and CDC-ACM, with 512-byte data packets.
Application identity is VID:PID `303A:4001`, manufacturer `AEVIA`, product
`V2 Mini Trajectory POC`, serial `V2MINI0001`. ROM download enumerates separately
as `303A:0020`. J5 exposes USB Serial/JTAG; UART0 is at TP2/TP1. These are
separate transports, not interchangeable connectors for the J6 console.

The default image emits CRLF-terminated ASCII records:

```text
RAW IMU <end_us> <interval_us> <ax> <ay> <az> <gx> <gy> <gz>
RAW GNSS <received_us> <original BESTNAVA line>
STATUS imu=... gnss=... led=... battery=... battery-pct=... battery-mv=... battery-part=... battery-regs=... battery-charger=... battery-gauge=... battery-errors=... last-imu-error=... capture-errors=... queue-drops=...
POWER ...
```

Acceleration is m/s² and angular rate is rad/s. GNSS receipt time and IMU end
time share the MCU monotonic clock, not UTC. STATUS is emitted approximately
once per second while the writer makes progress. POWER repeats the startup
snapshot on connection and every ten seconds; it is not live telemetry.
Consumers must frame lines across USB packets and tolerate status records
between measurements.

Send `STREAM <nonce>\n`, where nonce is exactly eight hexadecimal digits.
The USB writer clears queued measurements and responds
`STREAM READY <nonce> <time_us>\r\n` before further RAW records. Discard all
preceding input and match the nonce before starting a new consumer session.
Capture continues independently, and USB disconnect alone does not reset the
queue or estimator state in a consumer.

The command receiver also recognizes the byte sequence `BOOTLOADER`, sets
`LP_SYS.sys_ctrl.force_download_boot`, and software-resets into ROM download
mode. It is a sequence matcher, not a line-only command. Software entry needs
a functioning application USB connection. If neither application nor ROM USB
is present, the recorded recovery was a full SW7 power cycle. The repository
no longer provides a Cargo flashing runner or host tool scripts.

## Build configuration

Build from `firmware/` with `cargo build --release` so
[the target configuration](../../.cargo/config.toml) applies. The ELF is
`target/riscv32imafc-unknown-none-elf/release/aevia-firmware` relative to the
repository root. The pinned toolchain is Rust 1.95.0 and the target is
`riscv32imafc-unknown-none-elf`. The MCU uses `CpuClock::max()`.

[Cargo.toml](../../Cargo.toml) pins the Espressif HAL family to commit
`160b10794227eb84805b8676fe188c1110801e9d` with ESP32-S31 support; use that
revision when checking APIs rather than assuming another ESP target's API
matches. Useful pinned upstream references are the
[HAL manifest](https://github.com/esp-rs/esp-hal/blob/160b10794227eb84805b8676fe188c1110801e9d/esp-hal/Cargo.toml),
[S31 metadata](https://github.com/esp-rs/esp-hal/blob/160b10794227eb84805b8676fe188c1110801e9d/esp-metadata/devices/esp32s31/soc.toml),
and [I2C implementation](https://github.com/esp-rs/esp-hal/blob/160b10794227eb84805b8676fe188c1110801e9d/esp-hal/src/i2c/master/mod.rs).

## Unresolved hardware and measurement limits

These are retained uncertainties, not claims that the current firmware checks
them: cell chemistry/capacity/charge limits and pack protection; fitted
thermistor versus schematic naming and TS curve; MCU EN ramp margin; and the
reset-time strap-documentation discrepancy. The charger can operate before
firmware starts and remains upstream of the switched +3V3 rail.

GNSS/IMU capture has been exercised, but timing is software-based without PPS,
antenna lever arm and board calibration are unestablished, and speed accuracy
has not been compared with an independent reference. PSRAM initialization
and full-memory read/write checks now pass; onboard GNSS fusion remains
unverified. Historical capture/test results and the PSRAM diagnosis are
kept in [trajectory-poc.md](../trajectory-poc.md).

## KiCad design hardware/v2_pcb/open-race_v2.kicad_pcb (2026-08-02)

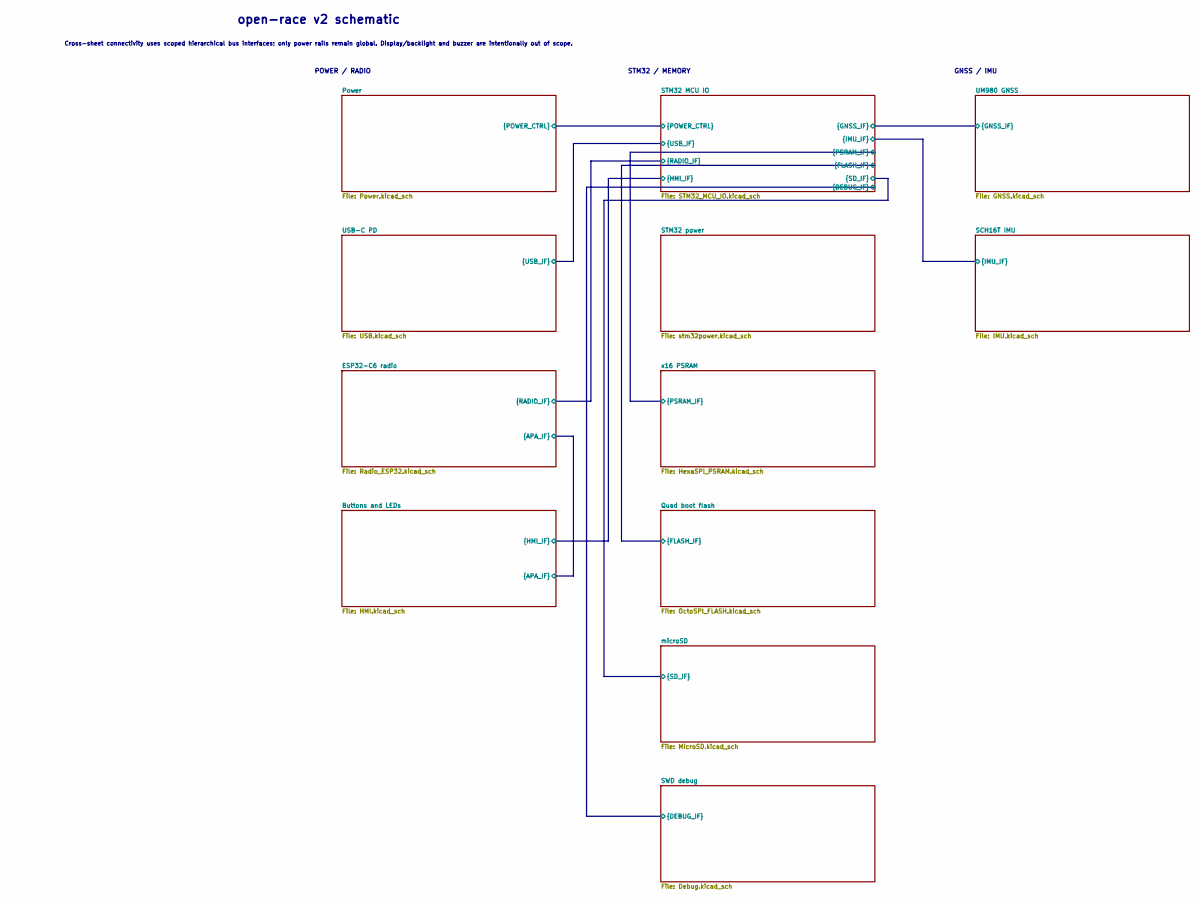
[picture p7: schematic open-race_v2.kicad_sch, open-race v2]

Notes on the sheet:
GNSS / IMU
STM32 / MEMORY
Cross-sheet connectivity uses scoped hierarchical bus interfaces; only power rails remain global. Display/backlight and buzzer are intentionally out of scope.
open-race v2 schematic
POWER / RADIO

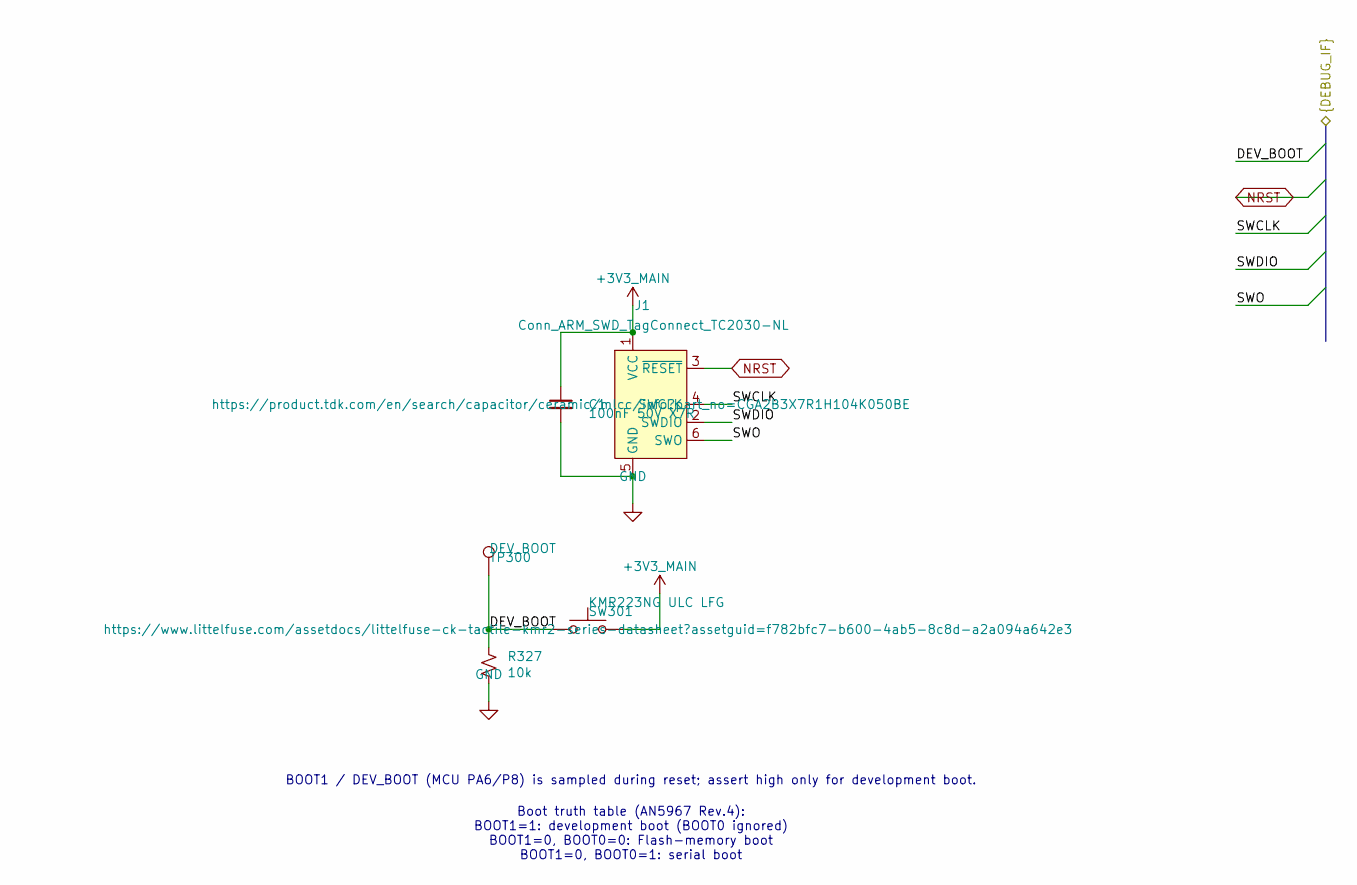
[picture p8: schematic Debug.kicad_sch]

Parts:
C1: 100nF 50V X7R; C_0402_1005Metric; Voltage 50 VDC; Tolerance ±10%; MPN CGA2B3X7R1H104K050BE
J1: Conn_ARM_SWD_TagConnect_TC2030-NL; Tag-Connect_TC2030-IDC-NL_2x03_P1.27mm_Vertical
R327: 10k; R_0402_1005Metric; Tolerance ±1%; MPN CRCW040210K0FKED
SW301: KMR223NG ULC LFG; SW_Push_1P1T_NO_CK_KMR2; MPN Y78B22324FP
TP300: DEV_BOOT; TestPoint_Plated_Hole_D2.0mm

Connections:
/STM32 MCU IO/DEV_BOOT: R327.1, SW301.1, TP300.1 (1_1); also elsewhere on the board
/STM32 MCU IO/SWCLK: J1.4 (SWCLK); also elsewhere on the board
/STM32 MCU IO/SWDIO: J1.2 (SWDIO); also elsewhere on the board
/STM32 MCU IO/SWO: J1.6 (SWO); also elsewhere on the board
NRST: J1.3 (~RESET); also elsewhere on the board

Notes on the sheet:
BOOT1 / DEV_BOOT (MCU PA6/P8) is sampled during reset; assert high only for development boot.
Boot truth table (AN5967 Rev.4): BOOT1=1: development boot (BOOT0 ignored) BOOT1=0, BOOT0=0: Flash-memory boot BOOT1=0, BOOT0=1: serial boot

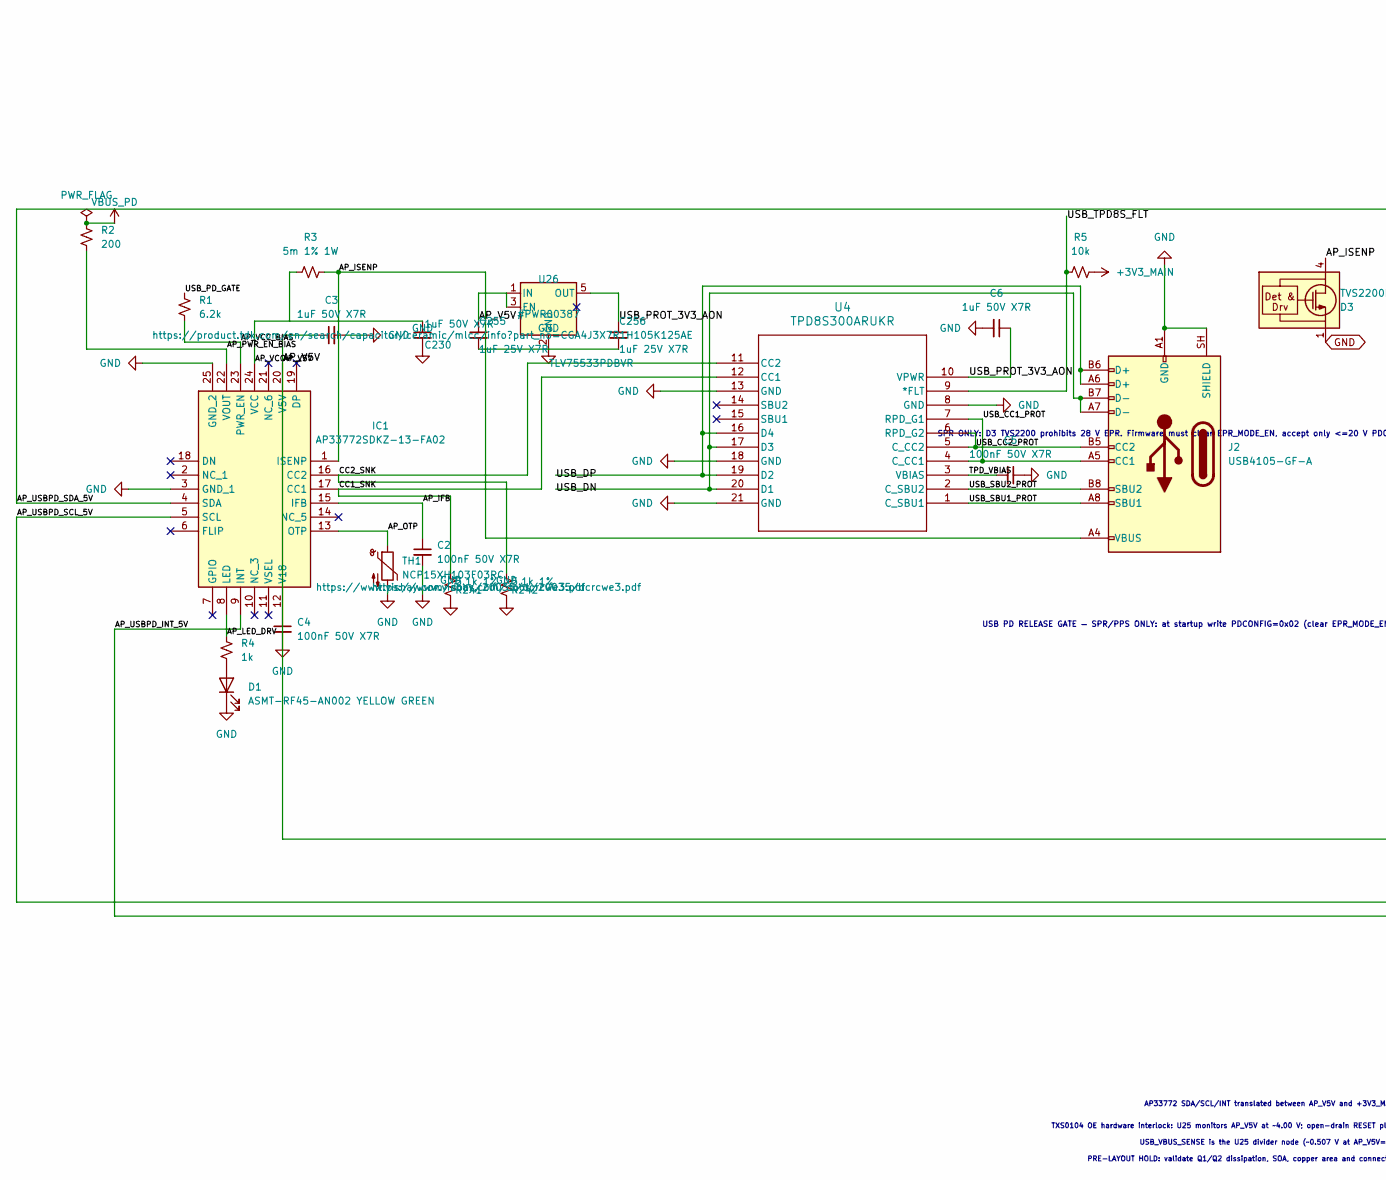
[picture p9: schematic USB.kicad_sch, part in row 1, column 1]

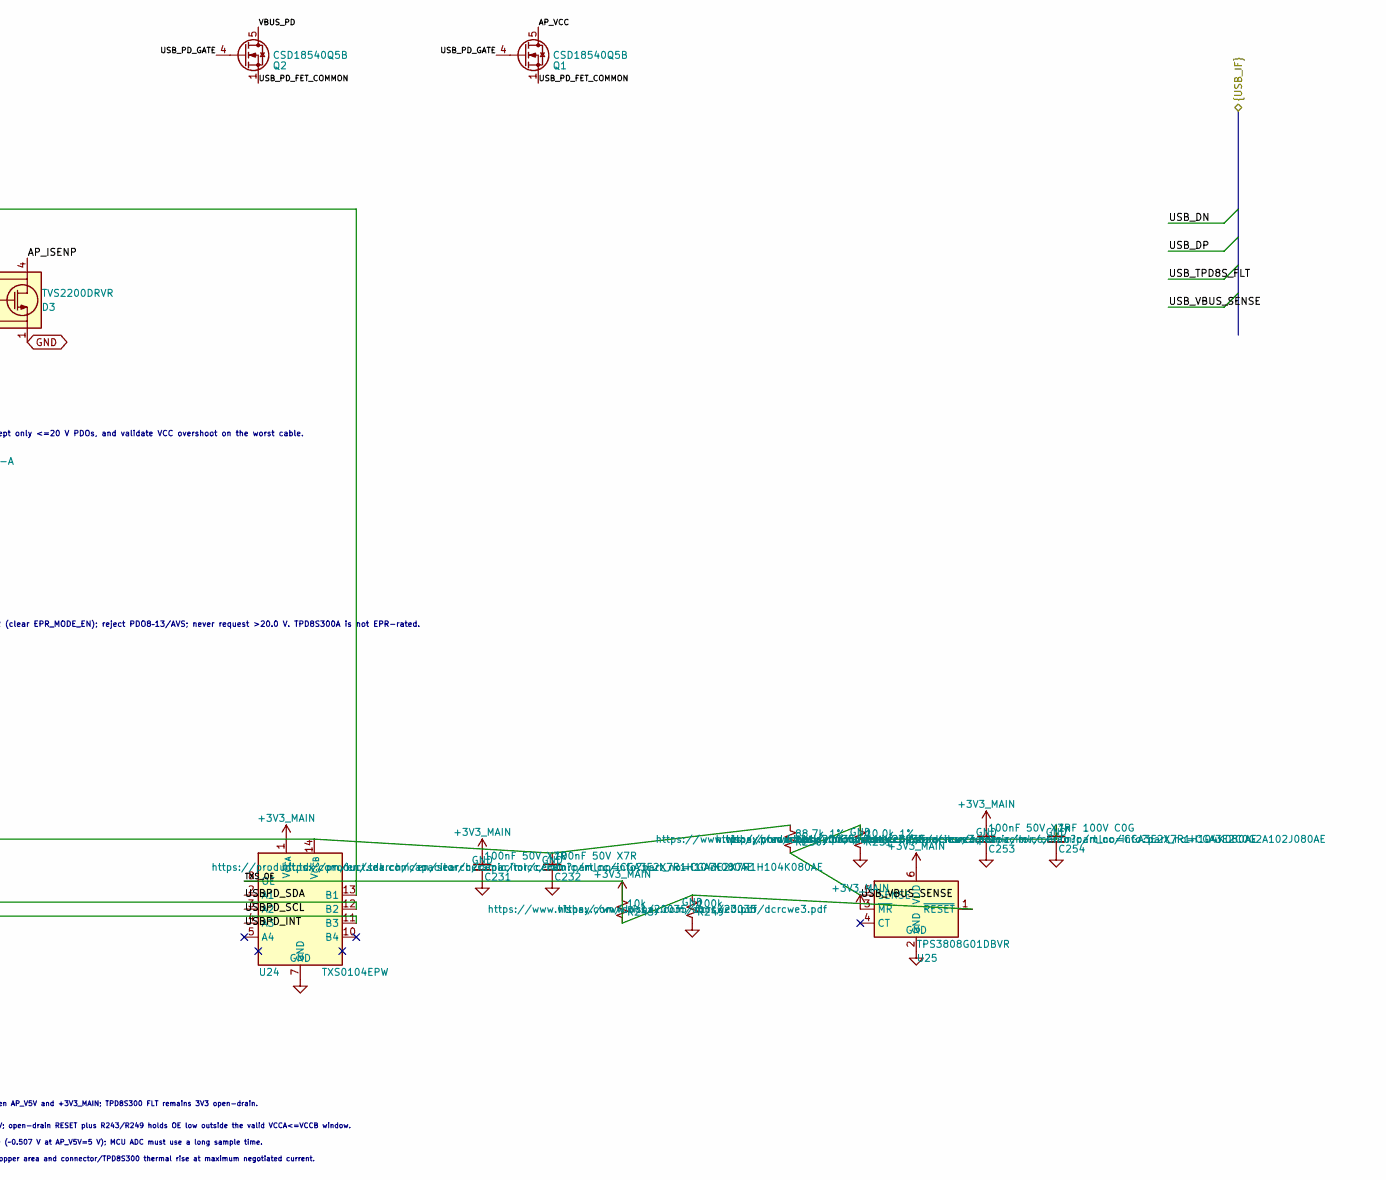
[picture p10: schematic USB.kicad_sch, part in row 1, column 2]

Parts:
C2, C4, C5, C231, C232, C253: 100nF 50V X7R; C_0603_1608Metric; Voltage 50 VDC; Tolerance ±10%; MPN CGA3E2X7R1H104K080AE
C3, C6, C230: 1uF 50V X7R; C_0805_2012Metric; Voltage 50 VDC; Tolerance ±10%; MPN CGA4J3X7R1H105K125AE
C254: 1nF 100V C0G; C_0603_1608Metric; Voltage 100 VDC; Tolerance ±5%; MPN CGA3E2C0G2A102J080AE
C255, C256: 1uF 25V X7R; C_0603_1608Metric; Voltage 25 VDC; Tolerance ±10%; MPN CGA3E1X7R1E105K080AE
D1: ASMT-RF45-AN002 YELLOW GREEN; LED_0603_1608Metric; MPN ASMT-RF45-AN002
D3: TVS2200DRVR; WSON-6-1EP_2x2mm_P0.65mm_EP1x1.6mm_TVS2200; MPN TVS2200DRVR
IC1: AP33772SDKZ-13-FA02; WQFN-24-1EP_4x4mm_P0.5mm_EP2.70x2.70mm_AP33772S; Manufacturer_Part_Number AP33772SDKZ-13-FA02
J2: USB4105-GF-A; USB_C_Receptacle_GCT_USB4105-xx-A_16P_TopMnt_Horizontal; MPN USB4105-GF-A
Q1, Q2: CSD18540Q5B; VSON-CLIP-8_DNK_5x6mm; MPN CSD18540Q5B
R1: 6.2k; R_0603_1608Metric; Tolerance ±1%; MPN CRCW06036K20FKEA
R2: 200; R_0603_1608Metric; Tolerance ±1%; MPN CRCW0603200RFKEA
R3: 5m 1% 1W; R_2512_6332Metric; Tolerance ±1%; MPN WSL2512R0050FEA
R4: 1k; R_0603_1608Metric; Tolerance ±1%; MPN CRCW06031K00FKEA
R5, R243: 10k; R_0603_1608Metric; Tolerance ±1%; MPN CRCW060310K0FKEA
R241, R242: 5.1k 1%; R_0603_1608Metric; Tolerance ±1%; MPN CRCW06035K10FKEA
R249: 100k; R_0603_1608Metric; Tolerance ±1%; MPN CRCW0603100KFKEA
R250: 88.7k 1%; R_0603_1608Metric; Tolerance ±1%; MPN CRCW060388K7FKEA
R251: 10.0k 1%; R_0603_1608Metric; Tolerance ±1%; MPN CRCW060310K0FKEA
TH1: NCP15XH103F03RC; R_0402_1005Metric; MPN NCP15XH103F03RC
U4: TPD8S300ARUKR; Texas_RUK0020B_WQFN-20-1EP_3x3mm_P0.4mm_EP1.7x1.7mm; MPN TPD8S300ARUKR
U24: TXS0104EPW; TSSOP-14_4.4x5mm_P0.65mm; MPN TXS0104EPWR
U25: TPS3808G01DBVR; SOT-23-6; MPN TPS3808G01DBVR
U26: TLV75533PDBVR; SOT-23-5; MPN TLV75533PDBVR

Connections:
/STM32 MCU IO/USBPD_INT: U24.4 (A3); also elsewhere on the board
/STM32 MCU IO/USBPD_SCL: U24.3 (A2); also elsewhere on the board
/STM32 MCU IO/USBPD_SDA: U24.2 (A1); also elsewhere on the board
/STM32 MCU IO/USB_DN: J2.A7 (D-), J2.B7 (D-), U4.17 (D3), U4.20 (D1); also elsewhere on the board
/STM32 MCU IO/USB_DP: J2.A6 (D+), J2.B6 (D+), U4.16 (D4), U4.19 (D2); also elsewhere on the board
/STM32 MCU IO/USB_TPD8S_FLT: R5.1, U4.9 (*FLT); also elsewhere on the board
/STM32 MCU IO/USB_VBUS_SENSE: C254.1, R250.2, R251.1, U25.5 (SENSE); also elsewhere on the board
/USB-C PD/AP_IFB: C2.1, IC1.15 (IFB)
/USB-C PD/AP_ISENP: D3.4 (IN), D3.5 (IN), D3.6 (IN), IC1.1 (ISENP), J2.A4 (VBUS), J2.A9 (VBUS), J2.B4 (VBUS), J2.B9 (VBUS), R3.2
/USB-C PD/AP_LED_DRV: IC1.8 (LED), R4.1
/USB-C PD/AP_OTP: IC1.13 (OTP), TH1.1
/USB-C PD/AP_PWR_EN_BIAS: IC1.22 (VOUT), R2.2
/USB-C PD/AP_USBPD_INT_5V: IC1.9 (INT), U24.11 (B3)
/USB-C PD/AP_USBPD_SCL_5V: IC1.5 (SCL), U24.12 (B2)
/USB-C PD/AP_USBPD_SDA_5V: IC1.4 (SDA), U24.13 (B1)
/USB-C PD/AP_VCC: C230.1, IC1.24 (VCC), Q1.5 (D), Q1.6 (D), Q1.7 (D), Q1.8 (D), R3.1
/USB-C PD/AP_VCC_BIAS: IC1.23 (PWR_EN), R1.2
/USB-C PD/CC1_SNK: IC1.17 (CC1), R241.1, U4.12 (CC1)
/USB-C PD/CC2_SNK: IC1.16 (CC2), R242.1, U4.11 (CC2)
/USB-C PD/TPD_VBIAS: C5.2, U4.3 (VBIAS)
/USB-C PD/USB_CC1_PROT: J2.A5 (CC1), U4.4 (C_CC1), U4.7 (RPD_G1)
/USB-C PD/USB_CC2_PROT: J2.B5 (CC2), U4.5 (C_CC2), U4.6 (RPD_G2)
/USB-C PD/USB_PD_FET_COMMON: Q1.1 (S), Q1.2 (S), Q1.3 (S), Q2.1 (S), Q2.2 (S), Q2.3 (S)
/USB-C PD/USB_PD_GATE: Q1.4 (G), Q2.4 (G), R1.1
/USB-C PD/USB_PROT_3V3_AON: C6.1, C256.1, U4.10 (VPWR), U26.5 (OUT)
/USB-C PD/USB_SBU1_PROT: J2.A8 (SBU1), U4.1 (C_SBU1)
/USB-C PD/USB_SBU2_PROT: J2.B8 (SBU2), U4.2 (C_SBU2)
unnamed: D1.2 (A), R4.2
unnamed: C4.1, IC1.12 (V18)
VBUS_PD: Q2.5 (D), Q2.6 (D), Q2.7 (D), Q2.8 (D), R2.1; also elsewhere on the board

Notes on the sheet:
SPR ONLY: D3 TVS2200 prohibits 28 V EPR. Firmware must clear EPR_MODE_EN, accept only <=20 V PDOs, and validate VCC overshoot on the worst cable.
USB PD RELEASE GATE — SPR/PPS ONLY: at startup write PDCONFIG=0x02 (clear EPR_MODE_EN); reject PDO8–13/AVS; never request >20.0 V. TPD8S300A is not EPR-rated.
USB_VBUS_SENSE is the U25 divider node (~0.507 V at AP_V5V=5 V); MCU ADC must use a long sample time.
AP33772 SDA/SCL/INT translated between AP_V5V and +3V3_MAIN; TPD8S300 FLT remains 3V3 open-drain.
PRE-LAYOUT HOLD: validate Q1/Q2 dissipation, SOA, copper area and connector/TPD8S300 thermal rise at maximum negotiated current.
TXS0104 OE hardware interlock: U25 monitors AP_V5V at ~4.00 V; open-drain RESET plus R243/R249 holds OE low outside the valid VCCA<=VCCB window.

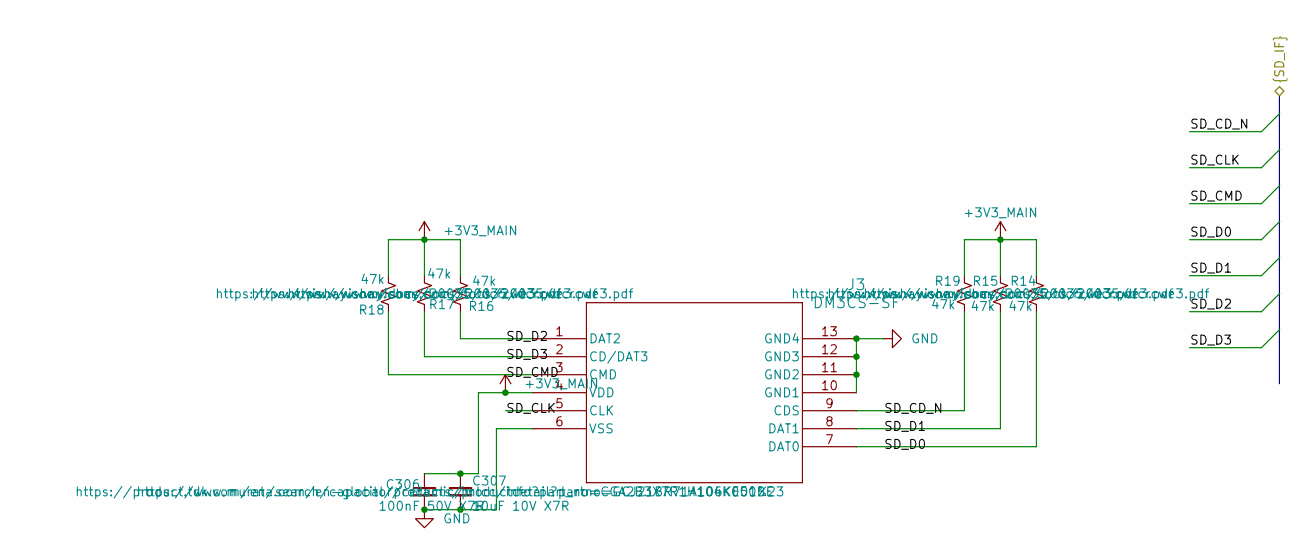
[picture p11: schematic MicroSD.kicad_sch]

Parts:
C306: 100nF 50V X7R; C_0402_1005Metric; Voltage 50 VDC; Tolerance ±10%; MPN CGA2B3X7R1H104K050BE
C307: 10uF 10V X7R; C_0805_2012Metric; Voltage 10 VDC; Tolerance ±10%; MPN GCJ21BR71A106KE01L
J3: DM3CS-SF; DM3CS-SF_HIR; MPN DM3CS-SF
R14, R15, R16, R17, R18, R19: 47k; R_0402_1005Metric; Tolerance ±1%; MPN CRCW040247K0FKED

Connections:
/STM32 MCU IO/SD_CD_N: J3.9 (CDS), R19.2; also elsewhere on the board
/STM32 MCU IO/SD_CLK: J3.5 (CLK); also elsewhere on the board
/STM32 MCU IO/SD_CMD: J3.3 (CMD), R18.2; also elsewhere on the board
/STM32 MCU IO/SD_D0: J3.7 (DAT0), R14.2; also elsewhere on the board
/STM32 MCU IO/SD_D1: J3.8 (DAT1), R15.2; also elsewhere on the board
/STM32 MCU IO/SD_D2: J3.1 (DAT2), R16.2; also elsewhere on the board
/STM32 MCU IO/SD_D3: J3.2 (CD/DAT3), R17.2; also elsewhere on the board

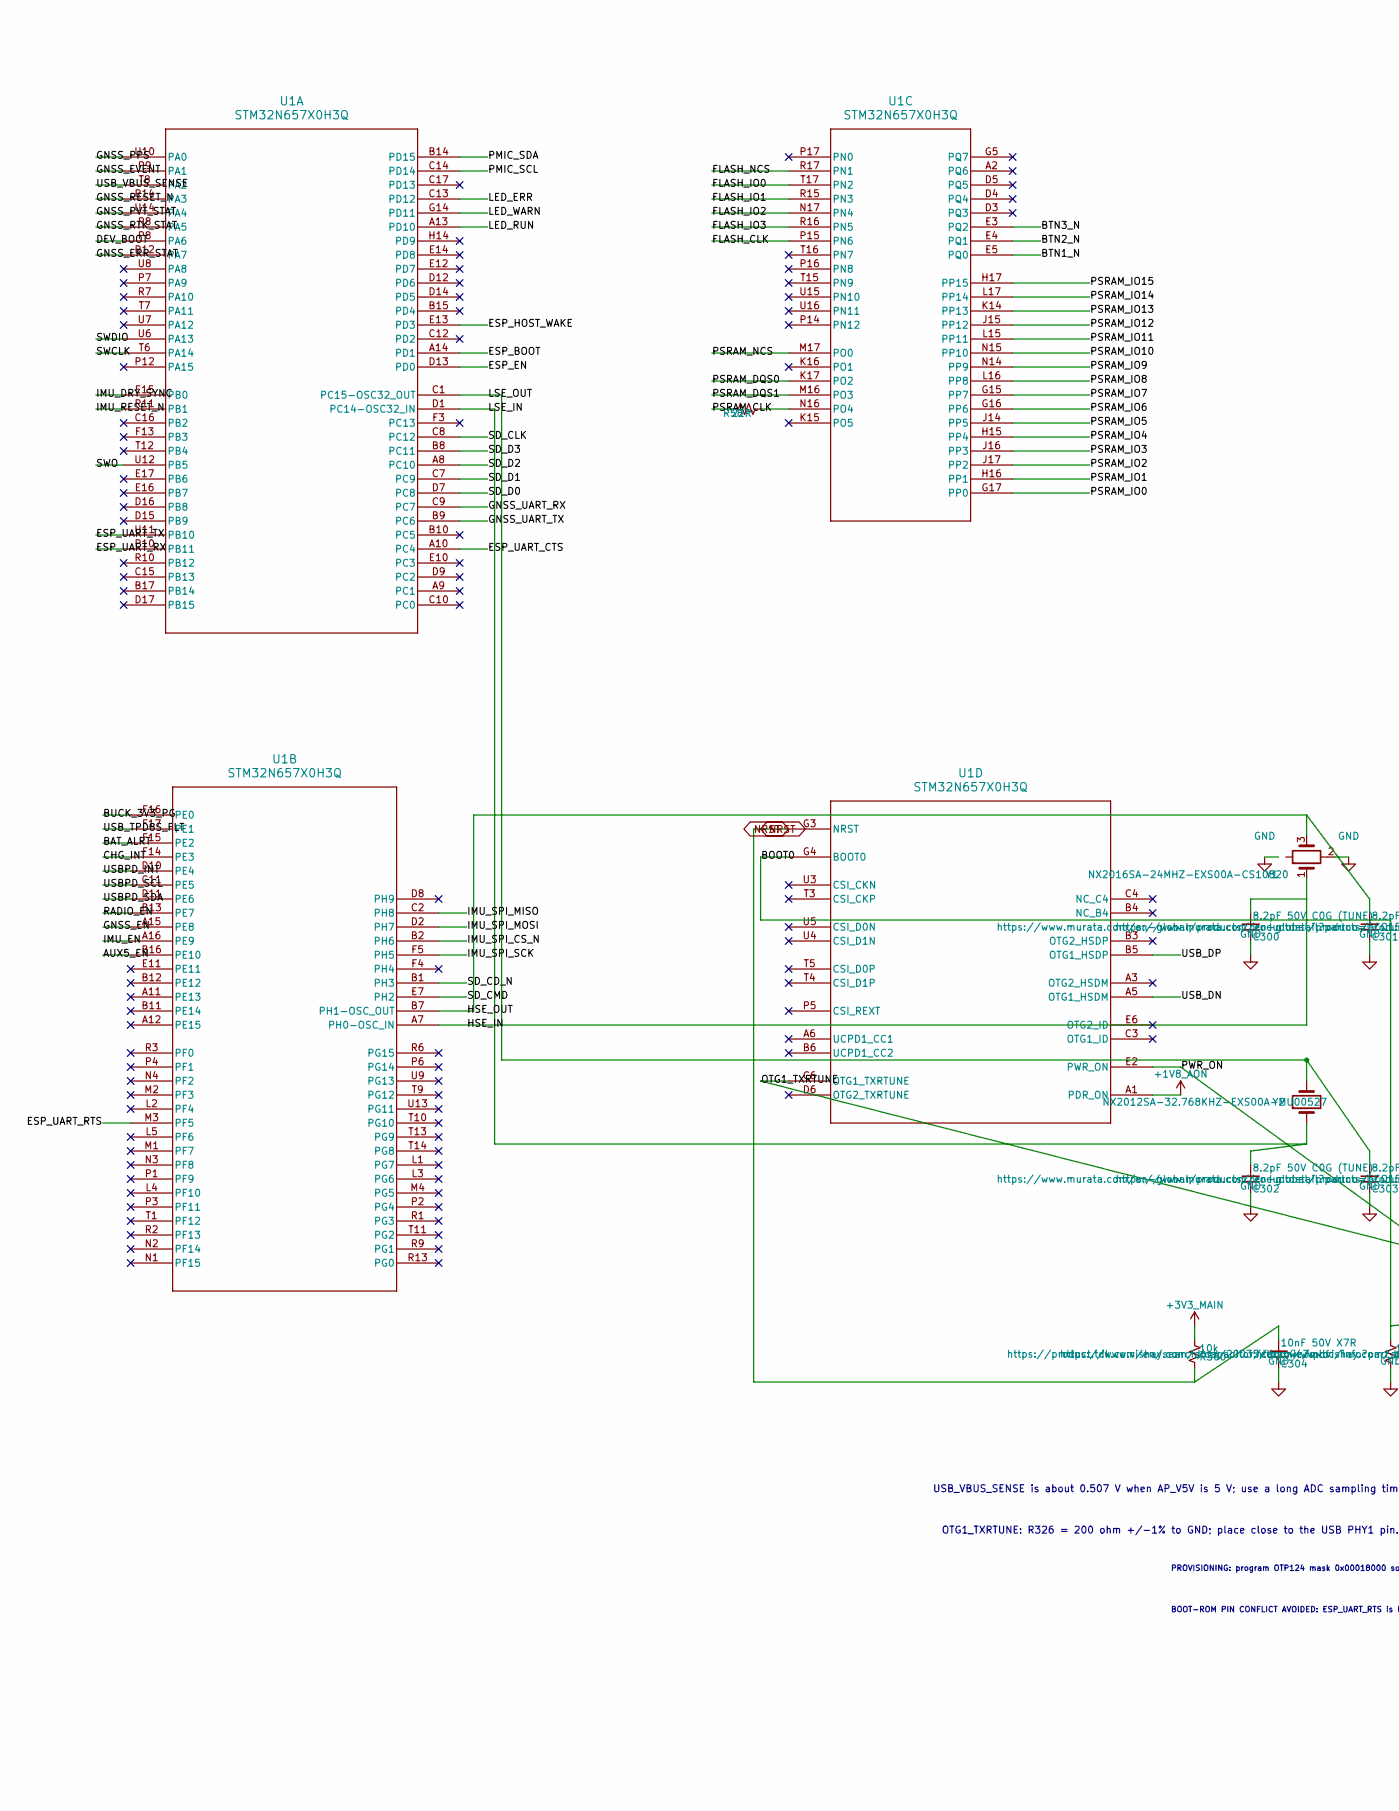
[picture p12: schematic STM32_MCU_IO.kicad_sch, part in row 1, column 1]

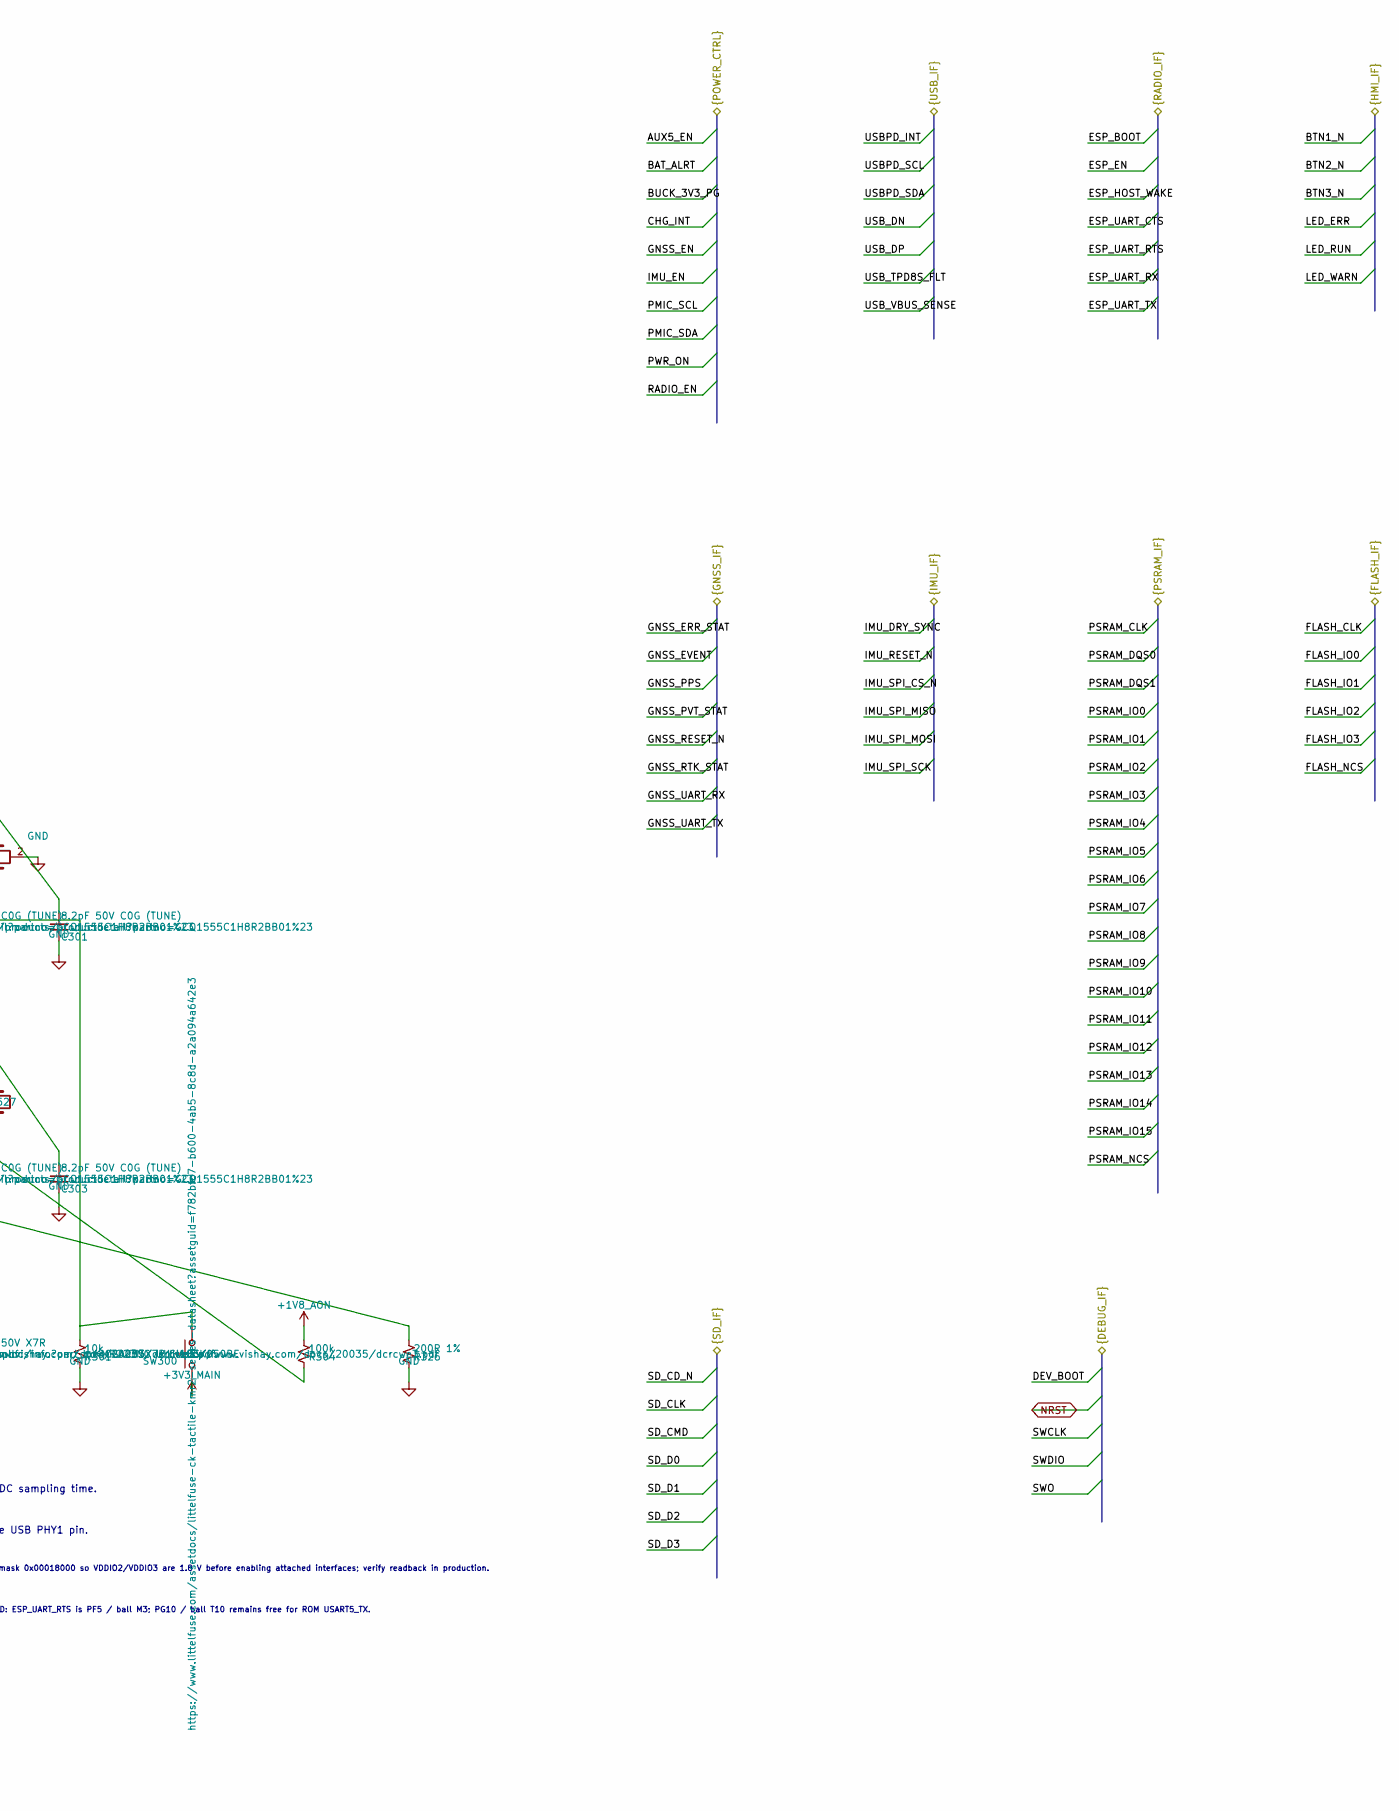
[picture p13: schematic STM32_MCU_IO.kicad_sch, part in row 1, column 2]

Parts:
C300, C301, C302, C303: 8.2pF 50V C0G (TUNE); C_0402_1005Metric; Voltage 50 VDC; Tolerance ±0.1 pF; MPN GCQ1555C1H8R2BB01D
C304: 10nF 50V X7R; C_0402_1005Metric; Voltage 50 VDC; Tolerance ±10%; MPN CGA2B3X7R1H103K050BE
R58: 22R; R_0402_1005Metric; Tolerance ±1%; MPN CRCW040222R0FKED
R300, R301: 10k; R_0402_1005Metric; Tolerance ±1%; MPN CRCW040210K0FKED
R304: 100k; R_0402_1005Metric; Tolerance ±1%; MPN CRCW0402100KFKED
R326: 200R 1%; R_0402_1005Metric; Tolerance ±1%; MPN CRCW0402200RFKED
SW300: KMR223NG ULC LFG; SW_Push_1P1T_NO_CK_KMR2; MPN Y78B22324FP
U1: STM32N657X0H3Q; VFBGA264_14X14_STM; MPN STM32N657X0H3Q
Y1: NX2016SA-24MHZ-EXS00A-CS10820; Crystal_SMD_2016-4Pin_2.0x1.6mm; MPN NX2016SA-24MHZ-EXS00A-CS10820
Y2: NX2012SA-32.768KHZ-EXS00A-MU00527; Crystal_SMD_2012-2Pin_2.0x1.2mm; MPN NX2012SA-32.768KHZ-EXS00A-MU00527

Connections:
+1V8_AON: R304.1, U1.A1 (PDR_ON); also elsewhere on the board
/Buttons and LEDs/BTN1_N: U1.E5 (PQ0); also elsewhere on the board
/Buttons and LEDs/BTN2_N: U1.E4 (PQ1); also elsewhere on the board
/Buttons and LEDs/BTN3_N: U1.E3 (PQ2); also elsewhere on the board
/Buttons and LEDs/LED_ERR: U1.C13 (PD12); also elsewhere on the board
/Buttons and LEDs/LED_RUN: U1.A13 (PD10); also elsewhere on the board
/Buttons and LEDs/LED_WARN: U1.G14 (PD11); also elsewhere on the board
/ESP32-C6 radio/ESP_BOOT: U1.A14 (PD1); also elsewhere on the board
/ESP32-C6 radio/ESP_EN: U1.D13 (PD0); also elsewhere on the board
/ESP32-C6 radio/ESP_HOST_WAKE: U1.E13 (PD3); also elsewhere on the board
/ESP32-C6 radio/ESP_UART_CTS: U1.A10 (PC4); also elsewhere on the board
/ESP32-C6 radio/ESP_UART_RTS: U1.M3 (PF5); also elsewhere on the board
/ESP32-C6 radio/ESP_UART_RX: U1.P10 (PB11); also elsewhere on the board
/ESP32-C6 radio/ESP_UART_TX: U1.U11 (PB10); also elsewhere on the board
/Power/AUX5_EN: U1.B16 (PE10); also elsewhere on the board
/Power/BAT_ALRT: U1.F15 (PE2); also elsewhere on the board
/Power/BUCK_3V3_PG: U1.F16 (PE0); also elsewhere on the board
/Power/CHG_INT: U1.F14 (PE3); also elsewhere on the board
/Power/GNSS_EN: U1.A15 (PE8); also elsewhere on the board
/Power/IMU_EN: U1.A16 (PE9); also elsewhere on the board
/Power/PMIC_SCL: U1.C14 (PD14); also elsewhere on the board
/Power/PMIC_SDA: U1.B14 (PD15); also elsewhere on the board
/Power/PWR_ON: R304.2, U1.E2 (PWR_ON); also elsewhere on the board
/Power/RADIO_EN: U1.B13 (PE7); also elsewhere on the board
/Quad boot flash/FLASH_CLK: U1.P15 (PN6); also elsewhere on the board
/Quad boot flash/FLASH_IO0: U1.T17 (PN2); also elsewhere on the board
/Quad boot flash/FLASH_IO1: U1.R15 (PN3); also elsewhere on the board
/Quad boot flash/FLASH_IO2: U1.N17 (PN4); also elsewhere on the board
/Quad boot flash/FLASH_IO3: U1.R16 (PN5); also elsewhere on the board
/Quad boot flash/FLASH_NCS: U1.R17 (PN1); also elsewhere on the board
/SCH16T IMU/IMU_DRY_SYNC: U1.E15 (PB0); also elsewhere on the board
/SCH16T IMU/IMU_RESET_N: U1.R11 (PB1); also elsewhere on the board
/SCH16T IMU/IMU_SPI_CS_N: U1.B2 (PH6); also elsewhere on the board
/SCH16T IMU/IMU_SPI_MISO: U1.C2 (PH8); also elsewhere on the board
/SCH16T IMU/IMU_SPI_MOSI: U1.D2 (PH7); also elsewhere on the board
/SCH16T IMU/IMU_SPI_SCK: U1.F5 (PH5); also elsewhere on the board
/STM32 MCU IO/BOOT0: R301.1, SW300.2, U1.G4 (BOOT0)
/STM32 MCU IO/DEV_BOOT: U1.P8 (PA6); also elsewhere on the board
/STM32 MCU IO/GNSS_ERR_STAT: U1.R12 (PA7); also elsewhere on the board
/STM32 MCU IO/GNSS_EVENT: U1.P9 (PA1); also elsewhere on the board
/STM32 MCU IO/GNSS_PPS: U1.U10 (PA0); also elsewhere on the board
/STM32 MCU IO/GNSS_PVT_STAT: U1.U14 (PA4); also elsewhere on the board
/STM32 MCU IO/GNSS_RESET_N: U1.R14 (PA3); also elsewhere on the board
/STM32 MCU IO/GNSS_RTK_STAT: U1.R8 (PA5); also elsewhere on the board
/STM32 MCU IO/GNSS_UART_RX: U1.C9 (PC7); also elsewhere on the board
/STM32 MCU IO/GNSS_UART_TX: U1.B9 (PC6); also elsewhere on the board
/STM32 MCU IO/HSE_IN: C300.1, U1.A7 (PH0-OSC_IN), Y1.1
/STM32 MCU IO/HSE_OUT: C301.1, U1.B7 (PH1-OSC_OUT), Y1.3
/STM32 MCU IO/LSE_IN: C302.1, U1.D1 (PC14-OSC32_IN), Y2.1
/STM32 MCU IO/LSE_OUT: C303.1, U1.C1 (PC15-OSC32_OUT), Y2.2
/STM32 MCU IO/PSRAM_CLK: R58.1; also elsewhere on the board
/STM32 MCU IO/PSRAM_DQS0: U1.K17 (PO2); also elsewhere on the board
/STM32 MCU IO/PSRAM_DQS1: U1.M16 (PO3); also elsewhere on the board
/STM32 MCU IO/PSRAM_IO0: U1.G17 (PP0); also elsewhere on the board
/STM32 MCU IO/PSRAM_IO1: U1.H16 (PP1); also elsewhere on the board
/STM32 MCU IO/PSRAM_IO2: U1.J17 (PP2); also elsewhere on the board
/STM32 MCU IO/PSRAM_IO3: U1.J16 (PP3); also elsewhere on the board
/STM32 MCU IO/PSRAM_IO4: U1.H15 (PP4); also elsewhere on the board
/STM32 MCU IO/PSRAM_IO5: U1.J14 (PP5); also elsewhere on the board
/STM32 MCU IO/PSRAM_IO6: U1.G16 (PP6); also elsewhere on the board
/STM32 MCU IO/PSRAM_IO7: U1.G15 (PP7); also elsewhere on the board
/STM32 MCU IO/PSRAM_IO8: U1.L16 (PP8); also elsewhere on the board
/STM32 MCU IO/PSRAM_IO9: U1.N14 (PP9); also elsewhere on the board
/STM32 MCU IO/PSRAM_IO10: U1.N15 (PP10); also elsewhere on the board
/STM32 MCU IO/PSRAM_IO11: U1.L15 (PP11); also elsewhere on the board
/STM32 MCU IO/PSRAM_IO12: U1.J15 (PP12); also elsewhere on the board
/STM32 MCU IO/PSRAM_IO13: U1.K14 (PP13); also elsewhere on the board
/STM32 MCU IO/PSRAM_IO14: U1.L17 (PP14); also elsewhere on the board
/STM32 MCU IO/PSRAM_IO15: U1.H17 (PP15); also elsewhere on the board
/STM32 MCU IO/PSRAM_NCS: U1.M17 (PO0); also elsewhere on the board
/STM32 MCU IO/SD_CD_N: U1.B1 (PH3); also elsewhere on the board
/STM32 MCU IO/SD_CLK: U1.C8 (PC12); also elsewhere on the board
/STM32 MCU IO/SD_CMD: U1.E7 (PH2); also elsewhere on the board
/STM32 MCU IO/SD_D0: U1.D7 (PC8); also elsewhere on the board
/STM32 MCU IO/SD_D1: U1.C7 (PC9); also elsewhere on the board
/STM32 MCU IO/SD_D2: U1.A8 (PC10); also elsewhere on the board
/STM32 MCU IO/SD_D3: U1.B8 (PC11); also elsewhere on the board
/STM32 MCU IO/SWCLK: U1.T6 (PA14); also elsewhere on the board
/STM32 MCU IO/SWDIO: U1.U6 (PA13); also elsewhere on the board
/STM32 MCU IO/SWO: U1.U12 (PB5); also elsewhere on the board
/STM32 MCU IO/USBPD_INT: U1.D10 (PE4); also elsewhere on the board
/STM32 MCU IO/USBPD_SCL: U1.C11 (PE5); also elsewhere on the board
/STM32 MCU IO/USBPD_SDA: U1.D11 (PE6); also elsewhere on the board
/STM32 MCU IO/USB_DN: U1.A5 (OTG1_HSDM); also elsewhere on the board
/STM32 MCU IO/USB_DP: U1.B5 (OTG1_HSDP); also elsewhere on the board
/STM32 MCU IO/USB_TPD8S_FLT: U1.F17 (PE1); also elsewhere on the board
/STM32 MCU IO/USB_VBUS_SENSE: U1.T8 (PA2); also elsewhere on the board
NRST: C304.1, R300.2, U1.G3 (NRST); also elsewhere on the board
unnamed: R58.2, U1.N16 (PO4)

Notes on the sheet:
BOOT-ROM PIN CONFLICT AVOIDED: ESP_UART_RTS is PF5 / ball M3; PG10 / ball T10 remains free for ROM USART5_TX.
PROVISIONING: program OTP124 mask 0x00018000 so VDDIO2/VDDIO3 are 1.8 V before enabling attached interfaces; verify readback in production.
OTG1_TXRTUNE: R326 = 200 ohm +/-1% to GND; place close to the USB PHY1 pin.
USB_VBUS_SENSE is about 0.507 V when AP_V5V is 5 V; use a long ADC sampling time.

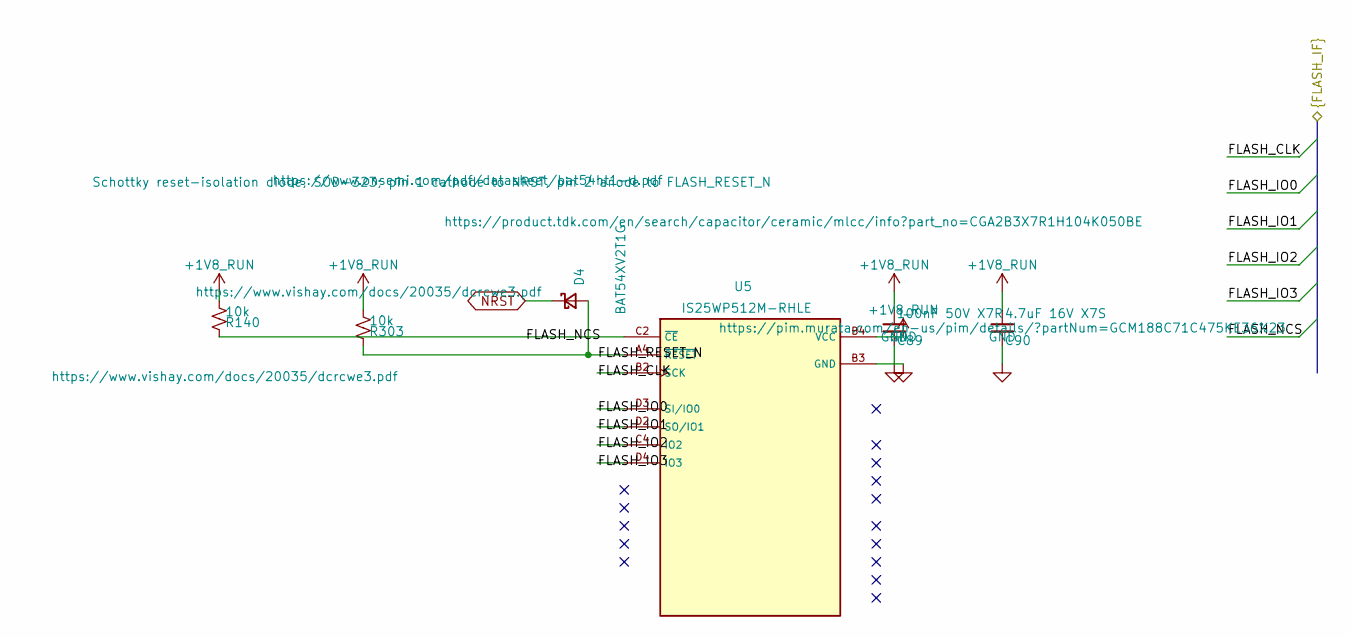
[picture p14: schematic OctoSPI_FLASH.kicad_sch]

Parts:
C89: 100nF 50V X7R; C_0402_1005Metric; Voltage 50 VDC; Tolerance ±10%; MPN CGA2B3X7R1H104K050BE
C90: 4.7uF 16V X7S; C_0603_1608Metric; Voltage 16 VDC; Tolerance ±10%; MPN GCM188C71C475KE36D
D4: BAT54XV2T1G; D_SOD-523; MPN BAT54HT1G
R140, R303: 10k; R_0402_1005Metric; Tolerance ±1%; MPN CRCW040210K0FKED
U5: IS25WP512M-RHLE; BGA24C100P5X5_800X600X120; MPN IS25WP512M-RHLE

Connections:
+1V8_RUN: C89.1, C90.1, R140.1, R303.1, U5.B4 (VCC); also elsewhere on the board
/Quad boot flash/FLASH_CLK: U5.B2 (SCK); also elsewhere on the board
/Quad boot flash/FLASH_IO0: U5.D3 (SI/IO0); also elsewhere on the board
/Quad boot flash/FLASH_IO1: U5.D2 (SO/IO1); also elsewhere on the board
/Quad boot flash/FLASH_IO2: U5.C4 (IO2); also elsewhere on the board
/Quad boot flash/FLASH_IO3: U5.D4 (IO3); also elsewhere on the board
/Quad boot flash/FLASH_NCS: R140.2, U5.C2 (~CE); also elsewhere on the board
/Quad boot flash/FLASH_RESET_N: D4.2 (A), R303.2, U5.A4 (~RESET)
NRST: D4.1 (K); also elsewhere on the board

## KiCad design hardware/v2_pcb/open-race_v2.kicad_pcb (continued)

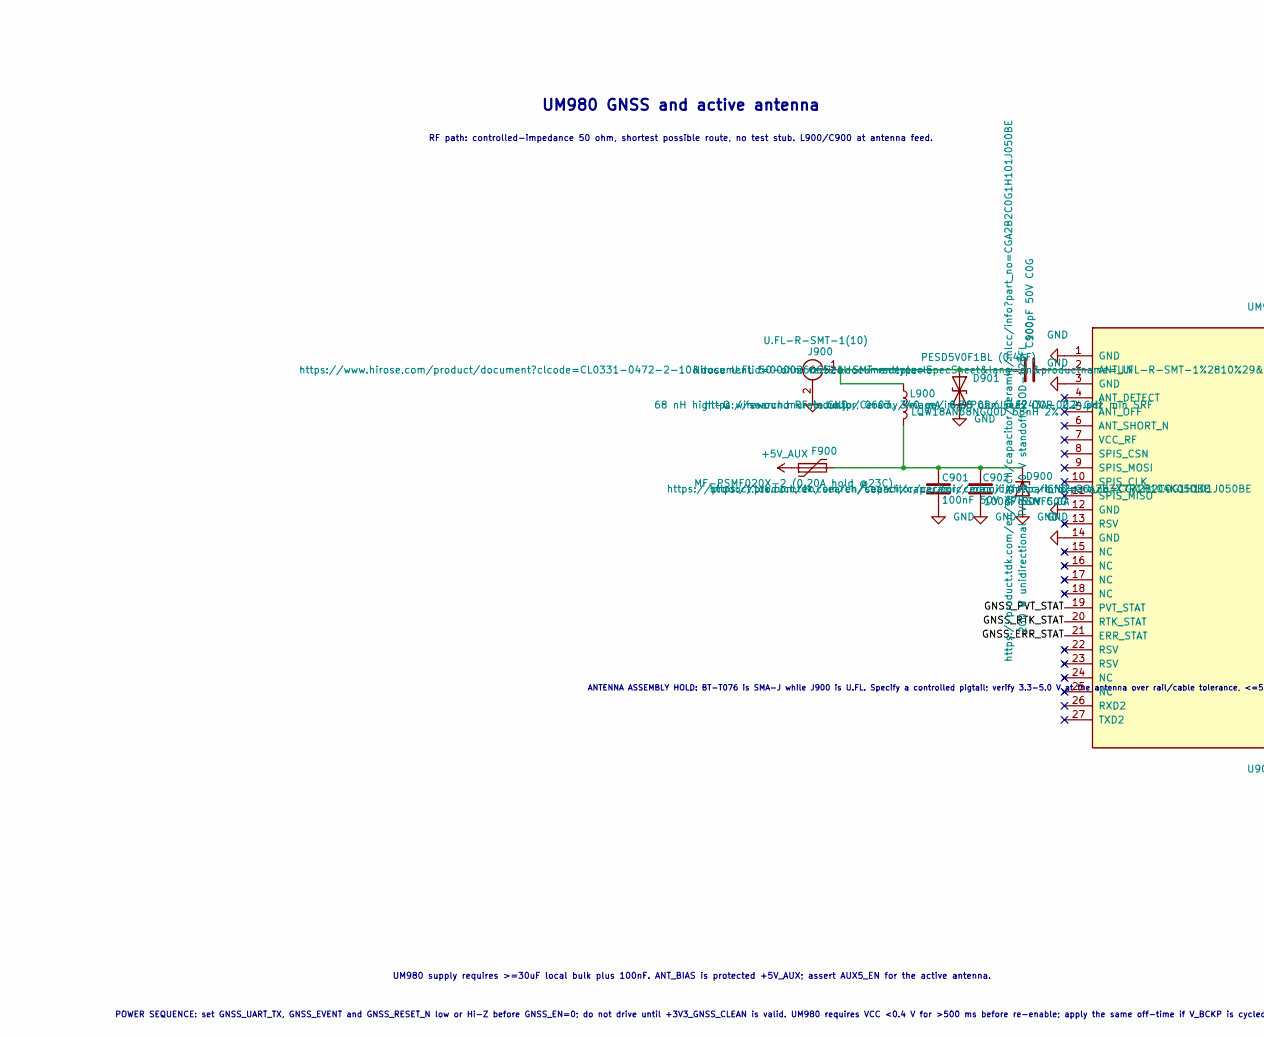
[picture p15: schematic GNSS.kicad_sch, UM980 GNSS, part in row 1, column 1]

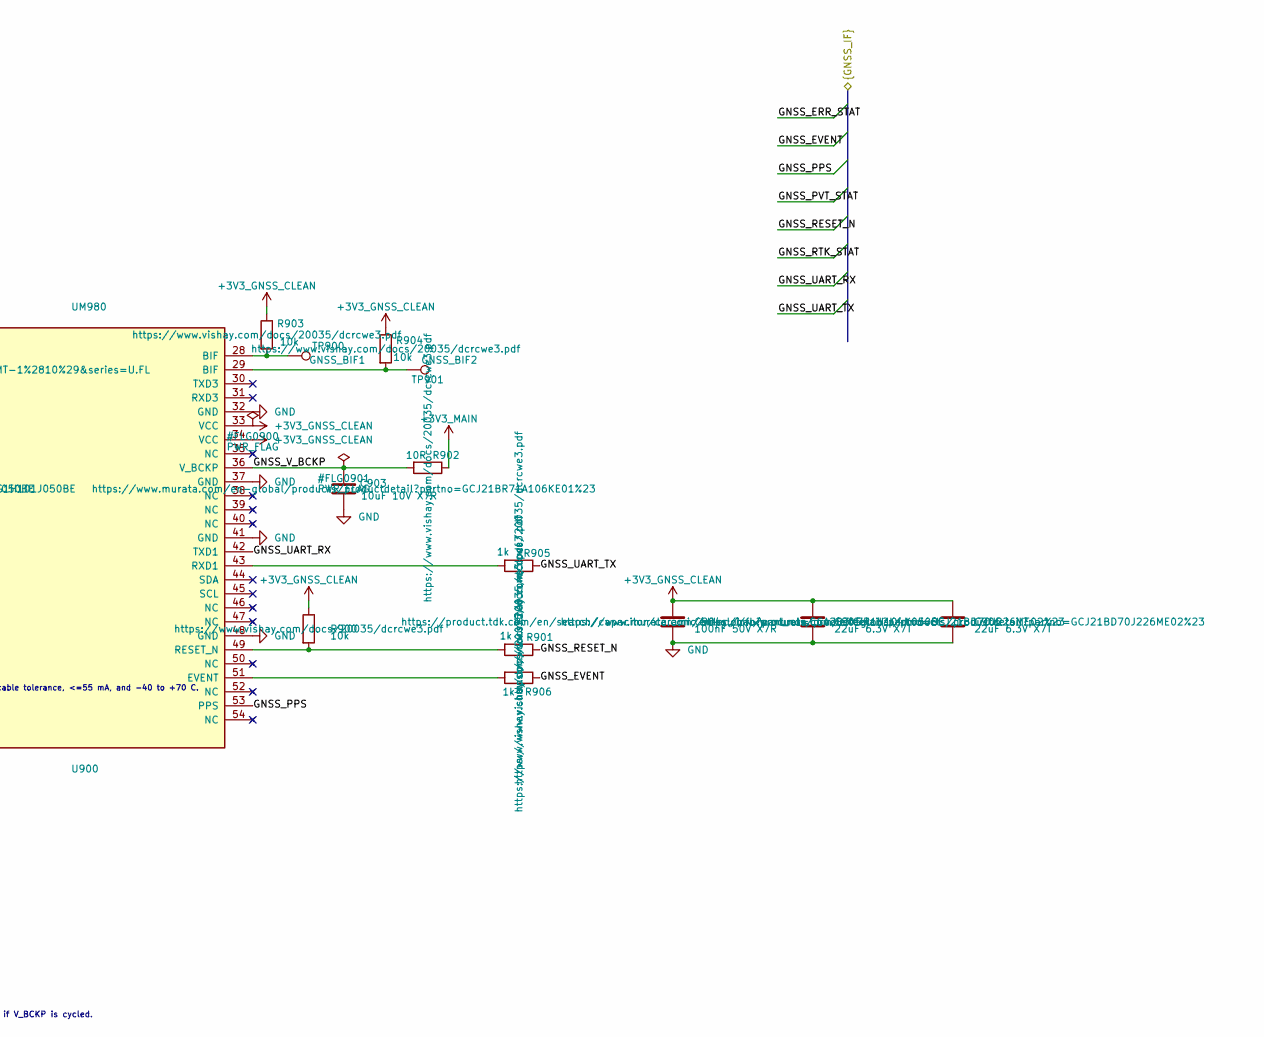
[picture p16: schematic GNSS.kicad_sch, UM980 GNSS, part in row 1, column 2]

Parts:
C900, C902: 100pF 50V C0G; C_0402_1005Metric; Voltage 50 VDC; Tolerance ±5%; MPN CGA2B2C0G1H101J050BE
C901, C904: 100nF 50V X7R; C_0402_1005Metric; Voltage 50 VDC; Tolerance ±10%; MPN CGA2B3X7R1H104K050BE
C903: 10uF 10V X7R; C_0805_2012Metric; Voltage 10 VDC; Tolerance ±10%; MPN GCJ21BR71A106KE01L
C905, C906: 22uF 6.3V X7T; C_0805_2012Metric; Voltage 6.3 VDC; Tolerance ±20%; MPN GCJ21BD70J226ME02L
D900: SMF5.0A; SOD-123FL_Littelfuse_SMF; MPN SMF5.0A
D901: PESD5V0F1BL (0.4pF); D_SOD-882; MPN PESD5V0F1BL,315
F900: MF-PSMF020X-2 (0.20A hold @23C); Fuse_0805_2012Metric; MPN MF-PSMF020X-2
J900: U.FL-R-SMT-1(10); U.FL_Hirose_U.FL-R-SMT-1_Vertical; MPN U.FL-R-SMT-1(10)
L900: LQW18AN68NG00D 68nH 2%; L_0603_1608Metric; MPN LQW18AN68NG00D
R900, R903, R904: 10k; R_0402_1005Metric; Tolerance ±1%; MPN CRCW040210K0FKED
R901, R905, R906: 1k; R_0402_1005Metric; Tolerance ±1%; MPN CRCW04021K00FKED
R902: 10R; R_0402_1005Metric; Tolerance ±1%; MPN CRCW040210R0FKED
TP900: GNSS_BIF1; TestPoint_Pad_D1.0mm
TP901: GNSS_BIF2; TestPoint_Pad_D1.0mm
U900: UM980; UM980_LGA-54_17x22mm; MPN UM980

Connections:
+3V3_GNSS_CLEAN: C904.1, C905.1, C906.1, R900.1, R903.1, R904.1, U900.33 (VCC), U900.34 (VCC); also elsewhere on the board
+5V_AUX: F900.1; also elsewhere on the board
/STM32 MCU IO/GNSS_ERR_STAT: U900.21 (ERR_STAT); also elsewhere on the board
/STM32 MCU IO/GNSS_EVENT: R906.1; also elsewhere on the board
/STM32 MCU IO/GNSS_PPS: U900.53 (PPS); also elsewhere on the board
/STM32 MCU IO/GNSS_PVT_STAT: U900.19 (PVT_STAT); also elsewhere on the board
/STM32 MCU IO/GNSS_RESET_N: R901.1; also elsewhere on the board
/STM32 MCU IO/GNSS_RTK_STAT: U900.20 (RTK_STAT); also elsewhere on the board
/STM32 MCU IO/GNSS_UART_RX: U900.42 (TXD1); also elsewhere on the board
/STM32 MCU IO/GNSS_UART_TX: R905.1; also elsewhere on the board
/UM980 GNSS/GNSS_V_BCKP: C903.1, R902.2, U900.36 (V_BCKP)
unnamed: C901.1, C902.1, D900.1 (K), F900.2, L900.2
unnamed: C900.1, D901.1 (A1), J900.1 (In), L900.1
unnamed: R903.2, TP900.1 (1_1), U900.28 (BIF)
unnamed: R904.2, TP901.1 (1_1), U900.29 (BIF)
unnamed: C900.2, U900.2 (ANT_IN)
unnamed: R906.2, U900.51 (EVENT)
unnamed: R900.2, R901.2, U900.49 (RESET_N)
unnamed: R905.2, U900.43 (RXD1)

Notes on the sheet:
POWER SEQUENCE: set GNSS_UART_TX, GNSS_EVENT and GNSS_RESET_N low or Hi-Z before GNSS_EN=0; do not drive until +3V3_GNSS_CLEAN is valid. UM980 requires VCC <0.4 V for >500 ms before re-enable; apply the same off-time if V_BCKP is cycled.
ANTENNA ASSEMBLY HOLD: BT-T076 is SMA-J while J900 is U.FL. Specify a controlled pigtail; verify 3.3-5.0 V at the antenna over rail/cable tolerance, <=55 mA, and -40 to +70 C.
RF path: controlled-impedance 50 ohm, shortest possible route, no test stub. L900/C900 at antenna feed.
UM980 supply requires >=30uF local bulk plus 100nF. ANT_BIAS is protected +5V_AUX; assert AUX5_EN for the active antenna.
UM980 GNSS and active antenna

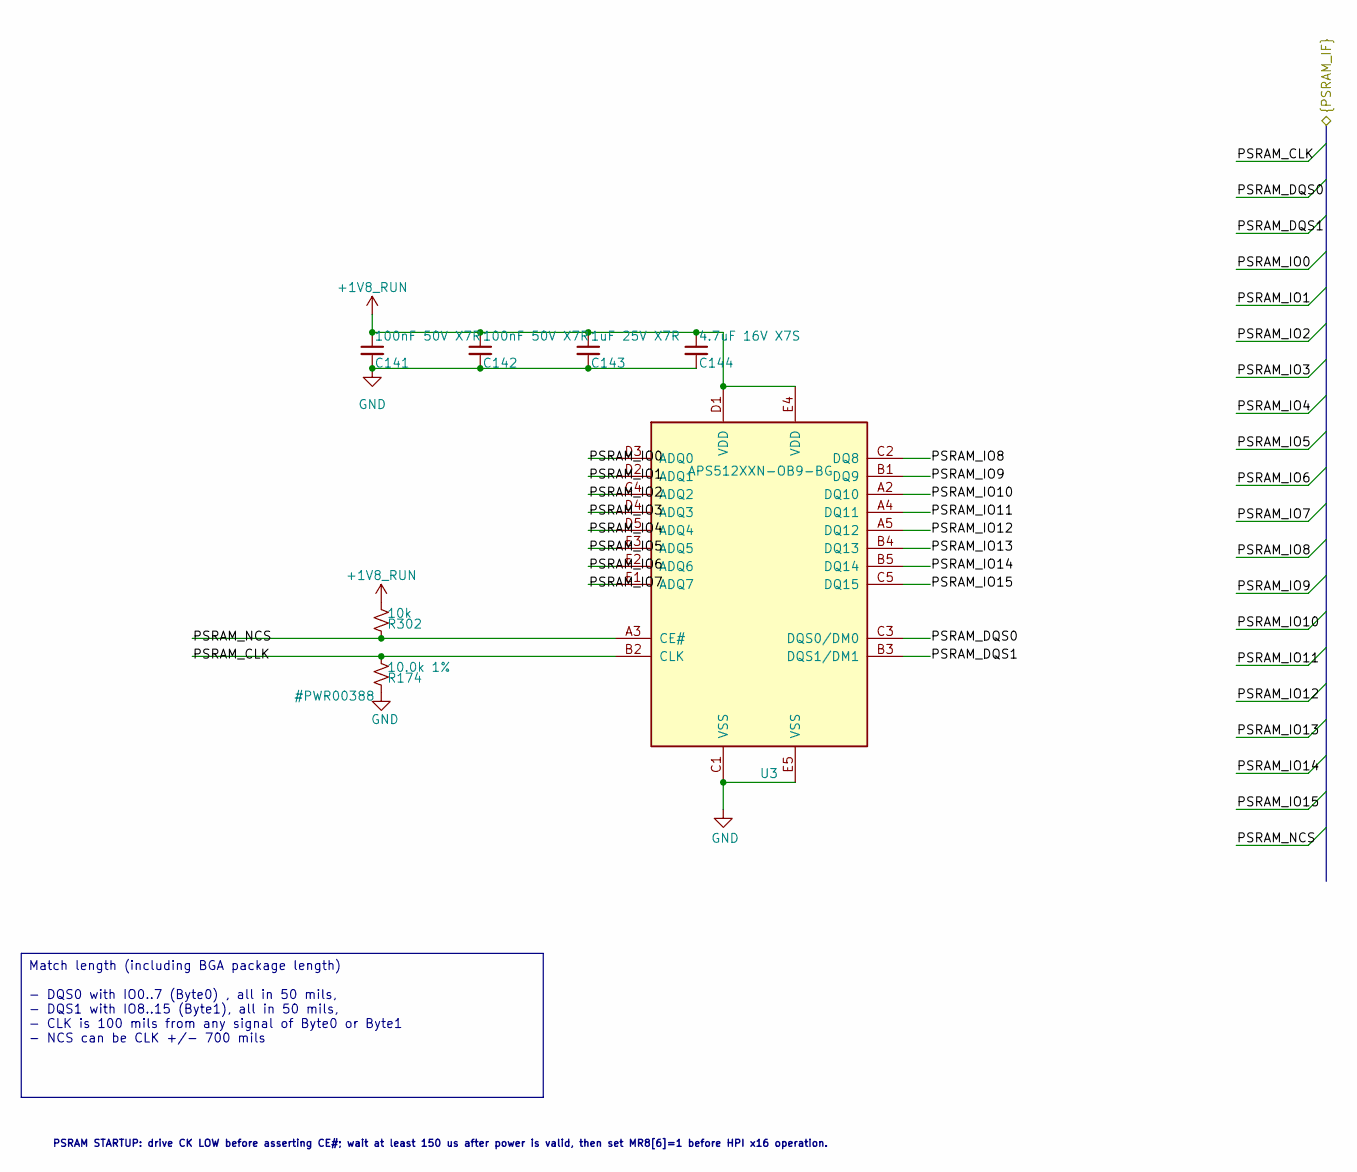
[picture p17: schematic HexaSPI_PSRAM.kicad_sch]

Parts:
C141, C142: 100nF 50V X7R; C_0402_1005Metric; Voltage 50 VDC; Tolerance ±10%; MPN CGA2B3X7R1H104K050BE
C143: 1uF 25V X7R; C_0603_1608Metric; Voltage 25 VDC; Tolerance ±10%; MPN CGA3E1X7R1E105K080AE
C144: 4.7uF 16V X7S; C_0603_1608Metric; Voltage 16 VDC; Tolerance ±10%; MPN GCM188C71C475KE36D
R174: 10.0k 1%; R_0402_1005Metric; Tolerance ±1%; MPN CRCW040210K0FKED
R302: 10k; R_0402_1005Metric; Tolerance ±1%; MPN CRCW040210K0FKED
U3: APS512XXN-OB9-BG; WLCSP-24_6x8mm_P1.0mm_APS512XXN; MPN APS512XXN-OB9-BG

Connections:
+1V8_RUN: C141.1, C142.1, C143.1, C144.1, R302.1, U3.D1 (VDD), U3.E4 (VDD); also elsewhere on the board
/STM32 MCU IO/PSRAM_CLK: R174.1, U3.B2 (CLK); also elsewhere on the board
/STM32 MCU IO/PSRAM_DQS0: U3.C3 (DQS0/DM0); also elsewhere on the board
/STM32 MCU IO/PSRAM_DQS1: U3.B3 (DQS1/DM1); also elsewhere on the board
/STM32 MCU IO/PSRAM_IO0: U3.D3 (ADQ0); also elsewhere on the board
/STM32 MCU IO/PSRAM_IO1: U3.D2 (ADQ1); also elsewhere on the board
/STM32 MCU IO/PSRAM_IO2: U3.C4 (ADQ2); also elsewhere on the board
/STM32 MCU IO/PSRAM_IO3: U3.D4 (ADQ3); also elsewhere on the board
/STM32 MCU IO/PSRAM_IO4: U3.D5 (ADQ4); also elsewhere on the board
/STM32 MCU IO/PSRAM_IO5: U3.E3 (ADQ5); also elsewhere on the board
/STM32 MCU IO/PSRAM_IO6: U3.E2 (ADQ6); also elsewhere on the board
/STM32 MCU IO/PSRAM_IO7: U3.E1 (ADQ7); also elsewhere on the board
/STM32 MCU IO/PSRAM_IO8: U3.C2 (DQ8); also elsewhere on the board
/STM32 MCU IO/PSRAM_IO9: U3.B1 (DQ9); also elsewhere on the board
/STM32 MCU IO/PSRAM_IO10: U3.A2 (DQ10); also elsewhere on the board
/STM32 MCU IO/PSRAM_IO11: U3.A4 (DQ11); also elsewhere on the board
/STM32 MCU IO/PSRAM_IO12: U3.A5 (DQ12); also elsewhere on the board
/STM32 MCU IO/PSRAM_IO13: U3.B4 (DQ13); also elsewhere on the board
/STM32 MCU IO/PSRAM_IO14: U3.B5 (DQ14); also elsewhere on the board
/STM32 MCU IO/PSRAM_IO15: U3.C5 (DQ15); also elsewhere on the board
/STM32 MCU IO/PSRAM_NCS: R302.2, U3.A3 (CE#); also elsewhere on the board

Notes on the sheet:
PSRAM STARTUP: drive CK LOW before asserting CE#; wait at least 150 us after power is valid, then set MR8[6]=1 before HPI x16 operation.
Match length (including BGA package length) - DQS0 with IO0..7 (Byte0) , all in 50 mils, - DQS1 with IO8..15 (Byte1), all in 50 mils, - CLK is 100 mils from any signal of Byte0 or Byte1 - NCS can be CLK +/- 700 mils

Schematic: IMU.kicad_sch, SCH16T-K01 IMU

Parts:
C1000, C1003: 1uF 25V X7R; C_0603_1608Metric; Voltage 25 VDC; Tolerance ±10%; MPN CGA3E1X7R1E105K080AE
C1001: 10uF 10V X7R; C_0805_2012Metric; Voltage 10 VDC; Tolerance ±10%; MPN GCJ21BR71A106KE01L
C1002, C1004: 100nF 50V X7R; C_0402_1005Metric; Voltage 50 VDC; Tolerance ±10%; MPN CGA2B3X7R1H104K050BE
R1000: 10k; R_0402_1005Metric; Tolerance ±1%; MPN CRCW040210K0FKED
R1001: 100R; R_0402_1005Metric; Tolerance ±1%; MPN CRCW0402100RFKED
R1002, R1004, R1005, R1006: 22R; R_0402_1005Metric; Tolerance ±1%; MPN CRCW040222R0FKED
R1003: 33R; R_0402_1005Metric; Tolerance ±1%; MPN CRCW040233R0FKED
U1000: SCH16T-K01-1; SOIC-24_SCH16T_11.8x13.4mm; MPN SCH16T-K01-1

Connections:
+3V3_IMU_CLEAN: C1002.1, C1003.1, C1004.1, R1000.1, U1000.8 (V3P3), U1000.17 (V3P3), U1000.18 (VDDIO); also elsewhere on the board
/SCH16T IMU/IMU_DRY_SYNC: R1003.1; also elsewhere on the board
/SCH16T IMU/IMU_RESET_N: R1001.1; also elsewhere on the board
/SCH16T IMU/IMU_SPI_CS_N: R1005.1; also elsewhere on the board
/SCH16T IMU/IMU_SPI_MISO: R1002.1; also elsewhere on the board
/SCH16T IMU/IMU_SPI_MOSI: R1006.1; also elsewhere on the board
/SCH16T IMU/IMU_SPI_SCK: R1004.1; also elsewhere on the board
unnamed: R1005.2, U1000.22 (CS)
unnamed: R1003.2, U1000.20 (DRY_SYNC)
unnamed: R1000.2, R1001.2, U1000.6 (EXTRESN)
unnamed: R1002.2, U1000.19 (MISO)
unnamed: R1006.2, U1000.23 (MOSI)
unnamed: R1004.2, U1000.21 (SCK)
unnamed: C1001.1, U1000.10 (VREGA2), U1000.11 (VREGA)
unnamed: C1000.1, U1000.14 (VREGD2), U1000.15 (VREGD)

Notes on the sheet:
SCH16T-K01 high-performance IMU
Keep regulator capacitors at their pin pairs; join exposed/heat-sink pads to the quiet ground plane.
Datasheet bypass: VREGD/VREGD2 1uF; VREGA/VREGA2 10uF; V3P3 pin 8 100nF; V3P3 pin 17 1uF.
POWER SEQUENCE: make IMU SPI SCK/MOSI/CS, DRY_SYNC and RESET_N analog/Hi-Z before IMU_EN=0; do not drive until +3V3_IMU_CLEAN is valid.

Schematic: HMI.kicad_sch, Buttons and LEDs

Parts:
C1100, C1101, C1110, C1111, C1112, C1113, C1114, C1121, C1122, C1123: 100nF 50V X7R; C_0402_1005Metric; Voltage 50 VDC; Tolerance ±10%; MPN CGA2B3X7R1H104K050BE
C1115: 47uF 10V X7R; C_1210_3225Metric; Voltage 10 VDC; Tolerance ±10%; MPN C1210X476K8RACAUTO
D1100, D1101, D1102, D1103, D1104: APA102-2020-256-8; LED-APA102-2020; MPN APA102-2020-256-8
D1110: ASMT-RF45-AN002 YELLOW GREEN; LED_0603_1608Metric; MPN ASMT-RF45-AN002
D1111: ASMT-RJ45-AQ502 ORANGE; LED_0603_1608Metric; MPN ASMT-RJ45-AQ502
D1112: ASMT-RR45-AQ902 RED; LED_0603_1608Metric; MPN ASMT-RR45-AQ902
R1100, R1101: 33R; R_0402_1005Metric; Tolerance ±1%; MPN CRCW040233R0FKED
R1102, R1103, R1121, R1122, R1123: 10k; R_0402_1005Metric; Tolerance ±1%; MPN CRCW040210K0FKED
R1110, R1111, R1112: 1k; R_0402_1005Metric; Tolerance ±1%; MPN CRCW04021K00FKED
SW1101, SW1102, SW1103: KMR223NG ULC LFG; SW_Push_1P1T_NO_CK_KMR2; MPN Y78B22324FP
U1100, U1101: SN74AHCT1G125DCKR; SOT-353_SC-70-5; MPN SN74AHCT1G125DCKR

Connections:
+5V_AUX: C1100.1, C1101.1, C1110.1, C1111.1, C1112.1, C1113.1, C1114.1, C1115.1, D1100.1 (VDD), D1101.1 (VDD), D1102.1 (VDD), D1103.1 (VDD), D1104.1 (VDD), U1100.5 (VCC), U1101.5 (VCC); also elsewhere on the board
/Buttons and LEDs/APA_CLK_1_2: D1100.2 (CKO), D1101.5 (CKI)
/Buttons and LEDs/APA_CLK_2_3: D1101.2 (CKO), D1102.5 (CKI)
/Buttons and LEDs/APA_CLK_3_4: D1102.2 (CKO), D1103.5 (CKI)
/Buttons and LEDs/APA_CLK_4_5: D1103.2 (CKO), D1104.5 (CKI)
/Buttons and LEDs/APA_CLK_5V: D1100.5 (CKI), R1101.1
/Buttons and LEDs/APA_CLK_BUF: R1101.2, U1101.4
/Buttons and LEDs/APA_DATA_1_2: D1100.3 (SDO), D1101.4 (SDI)
/Buttons and LEDs/APA_DATA_2_3: D1101.3 (SDO), D1102.4 (SDI)
/Buttons and LEDs/APA_DATA_3_4: D1102.3 (SDO), D1103.4 (SDI)
/Buttons and LEDs/APA_DATA_4_5: D1103.3 (SDO), D1104.4 (SDI)
/Buttons and LEDs/APA_DATA_5V: D1100.4 (SDI), R1100.1
/Buttons and LEDs/APA_DATA_BUF: R1100.2, U1100.4
/Buttons and LEDs/BTN1_N: C1121.1, R1121.2, SW1101.1; also elsewhere on the board
/Buttons and LEDs/BTN2_N: C1122.1, R1122.2, SW1102.1; also elsewhere on the board
/Buttons and LEDs/BTN3_N: C1123.1, R1123.2, SW1103.1; also elsewhere on the board
/Buttons and LEDs/ESP_APA_CLK: R1103.1, U1101.2; also elsewhere on the board
/Buttons and LEDs/ESP_APA_DATA: R1102.1, U1100.2; also elsewhere on the board
/Buttons and LEDs/LED_ERR: R1112.2; also elsewhere on the board
/Buttons and LEDs/LED_ERR_ANODE: D1112.2 (A), R1112.1
/Buttons and LEDs/LED_RUN: R1110.2; also elsewhere on the board
/Buttons and LEDs/LED_RUN_ANODE: D1110.2 (A), R1110.1
/Buttons and LEDs/LED_WARN: R1111.2; also elsewhere on the board
/Buttons and LEDs/LED_WARN_ANODE: D1111.2 (A), R1111.1

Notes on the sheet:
AHCT inputs accept 3.3 V logic while powered at 5 V. Route clock and data together and keep the first pixel close to U1100/U1101.
Buttons and LEDs (no display, no buzzer)

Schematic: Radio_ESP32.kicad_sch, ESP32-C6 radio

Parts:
C800: 1uF 25V X7R; C_0603_1608Metric; Voltage 25 VDC; Tolerance ±10%; MPN CGA3E1X7R1E105K080AE
C801: 100nF 50V X7R; C_0402_1005Metric; Voltage 50 VDC; Tolerance ±10%; MPN CGA2B3X7R1H104K050BE
C802: 10uF 10V X7R; C_0805_2012Metric; Voltage 10 VDC; Tolerance ±10%; MPN GCJ21BR71A106KE01L
C803: 47uF 10V X7R; C_1210_3225Metric; Voltage 10 VDC; Tolerance ±10%; MPN C1210X476K8RACAUTO
J800: M50-3530642 (VTREF sense only); PinHeader_1x06_P1.27mm_Vertical; MPN M50-3530642
R800, R802, R804: 10k; R_0402_1005Metric; Tolerance ±1%; MPN CRCW040210K0FKED
R801, R803, R805, R806: 1k; R_0402_1005Metric; Tolerance ±1%; MPN CRCW04021K00FKED
R807: 10k VTREF isolation; R_0402_1005Metric; Tolerance ±1%; MPN CRCW040210K0FKED
SW800, SW801: KMR223NG ULC LFG; SW_Push_1P1T_NO_CK_KMR2; MPN Y78B22324FP
U800: ESP32-C6-MINI-1; MPN ESP32-C6-MINI-1-N4

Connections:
+3V3_RADIO_SW: C801.1, C802.1, C803.1, R800.1, R802.1, R804.1, R807.1, U800.3 (3V3); also elsewhere on the board
/Buttons and LEDs/ESP_APA_CLK: U800.10 (IO5); also elsewhere on the board
/Buttons and LEDs/ESP_APA_DATA: U800.9 (IO4); also elsewhere on the board
/ESP32-C6 radio/ESP_BOOT: R803.1; also elsewhere on the board
/ESP32-C6 radio/ESP_BOOT_NODE: J800.6, R802.2, R803.2, SW801.1, U800.23 (IO9)
/ESP32-C6 radio/ESP_EN: R801.1; also elsewhere on the board
/ESP32-C6 radio/ESP_GPIO8_STRAP: R804.2, U800.22 (IO8)
/ESP32-C6 radio/ESP_HOST_WAKE: U800.12 (IO0); also elsewhere on the board
/ESP32-C6 radio/ESP_PROG_VTREF: J800.1, R807.2
/ESP32-C6 radio/ESP_UART_CTS: R806.1; also elsewhere on the board
/ESP32-C6 radio/ESP_UART_CTS_NODE: R806.2, U800.6 (IO3)
/ESP32-C6 radio/ESP_UART_RTS: U800.5 (IO2); also elsewhere on the board
/ESP32-C6 radio/ESP_UART_RX: J800.4, U800.31 (TXD0); also elsewhere on the board
/ESP32-C6 radio/ESP_UART_TX: R805.1; also elsewhere on the board
/ESP32-C6 radio/ESP_UART_TX_NODE: J800.3, R805.2, U800.30 (RXD0)

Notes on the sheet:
ESP32-C6 radio and programming
Place 100nF/10uF/47uF at the module supply pins. J800 is isolated from STM TX by R805. Keep the antenna keep-out clear.
ESP_EN and ESP_BOOT must be driven open-drain by STM32 firmware; series resistors preserve reset straps.
J800.1 is level-reference sensing only: do not use the programmer to power the radio rail. R807 limits accidental backfeed.
POWER SEQUENCE: set ESP_UART_TX/CTS, ESP_EN and ESP_BOOT low or Hi-Z before RADIO_EN=0; do not drive them until +3V3_RADIO_SW is valid.

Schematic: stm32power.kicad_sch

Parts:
C28, C36, C39, C40, C46, C47, C48, C50, C52, C54, C55, C58, C59, C64, C66, C67, C71, C72, C73, C74, C75, C76, C77, C78, C79, C80, C169, C309: 100nF 50V X7R; C_0402_1005Metric; Voltage 50 VDC; Tolerance ±10%; MPN CGA2B3X7R1H104K050BE
C29, C35: 10uF 10V X7R; C_0805_2012Metric; Voltage 10 VDC; Tolerance ±10%; MPN GCJ21BR71A106KE01L
C34: 4.7uF 16V X7S; C_0603_1608Metric; Voltage 16 VDC; Tolerance ±10%; MPN GCM188C71C475KE36D
C37: 2.2nF 50V X7R; C_0402_1005Metric; Voltage 50 VDC; Tolerance ±10%; MPN CGA2B2X7R1H222K050BE
C38, C41, C43, C44, C45, C51, C57, C60, C61, C63, C65, C68, C69, C70, C308: 1uF 10V X7S; C_0402_1005Metric; Voltage 10 VDC; Tolerance ±10%; MPN GCM155C71A105KE38D
C170, C176, C177, C178, C179: 22uF 6.3V X7T; C_0805_2012Metric; Voltage 6.3 VDC; Tolerance ±20%; MPN GCJ21BD70J226ME02L
L4: 2.2nH 1A; L_TDK_MHQ1005_1.0x0.6mm; MPN MHQ1005P2N2BT000
L7: 1uH; L_1008_2520Metric; MPN DFE252012P-1R0M=P2
L8: 22R @100MHz 8A; L_0603_1608Metric; MPN BLM18SN220TN1D
R22, R167: 0R; R_1206_3216Metric; Tolerance Jumper; MPN WFZ120600000ZE66
R27: 0R; R_0402_1005Metric; Tolerance Jumper; MPN RC0402JR-070RL
R148, R159: 0R; R_0402_1005Metric; Tolerance Jumper; MPN CRCW04020000Z0ED
R168: 50mR (DNP); R_2512_6332Metric
R173: 0R DNP (alternate to L8); R_0402_1005Metric
R220: 2R; R_0402_1005Metric; Tolerance ±1%; MPN RCS04022R00FKED
U1: STM32N657X0H3Q; VFBGA264_14X14_STM

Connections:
+1V8_AON: C36.2, R148.1; also elsewhere on the board
+1V8_RUN: C38.2, C39.2, C46.2, C47.2, C50.2, C54.2, C71.2, C74.2, C77.2, C78.2, C79.2, C80.2, L4.1, L8.1, R27.1, R173.2, U1.C5 (VDDA18USB), U1.L13 (VDDIO2), U1.L14 (VDDIO2), U1.M5 (VDDA18PLL), U1.M14 (VDDIO2), U1.M15 (VDDIO2), U1.N6 (VDDA18ADC), U1.N13 (VDDIO3), U1.P13 (VDDIO3), U1.R5 (VDDA18CSI); also elsewhere on the board
/STM32 power/I_SENS_VDDCORE_N: C170.1, R22.2, R167.1, R168.1, U1.G2 (VFBSMPS)
/STM32 power/I_SENS_VDDCORE_P: C170.2, C176.2, C177.1, C178.2, C179.2, L7.2, R167.2, R168.2
unnamed: C29.1, C35.1, C41.1, C45.1, C48.1, C52.1, L4.2, U1.K1 (VDDSMPS), U1.K2 (VDDSMPS), U1.K3 (VDDSMPS), U1.K4 (VDDSMPS), U1.K5 (VDDSMPS), U1.K6 (VDDSMPS)
unnamed: C37.1, R220.2
unnamed: L7.1, R220.1, U1.J1 (VLXSMPS), U1.J2 (VLXSMPS), U1.J3 (VLXSMPS), U1.J4 (VLXSMPS), U1.J5 (VLXSMPS), U1.J6 (VLXSMPS)
unnamed: C34.1, U1.F1 (V08CAP)
unnamed: C43.2, R159.2, U1.A4 (VDD33USB)
VDDA18AON: C40.2, R148.2, U1.F6 (VDDA18AON)
VDDA18PMU: C169.2, L8.2, R173.1, U1.G1 (VDDA18PMU)
VDDCORE: C44.2, C51.2, C57.2, C60.2, C61.2, C63.2, C65.2, C68.2, C69.2, C70.2, R22.1, U1.L6 (VDDCORE), U1.L12 (VDDCORE), U1.M7 (VDDCORE), U1.M9 (VDDCORE), U1.M11 (VDDCORE), U1.N8 (VDDCORE), U1.N10 (VDDCORE), U1.N12 (VDDCORE), U1.P11 (VDDCORE), U1.R4 (VDDCSI)
VREFP: C308.1, C309.1, R27.2, U1.U2 (VREF+)

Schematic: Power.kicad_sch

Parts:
C7, C11, C14, C83, C86, C187, C190, C240, C246, C249, C252: 100nF 50V X7R; C_0603_1608Metric; Voltage 50 VDC; Tolerance ±10%; MPN CGA3E2X7R1H104K080AE
C8, C12, C18: 10nF 50V X7R; C_0603_1608Metric; Voltage 50 VDC; Tolerance ±10%; MPN CGA3E2X7R1H103K080AE
C9, C10, C42, C56, C62, C81, C82, C84, C85, C87, C88, C91, C93, C233, C234: 10uF 50V X7R; C_1210_3225Metric; Voltage 50 VDC; Tolerance ±10%; MPN CNA6P1X7R1H106K250AE
C13, C15, C16, C17: 470nF 25V X7R; C_0603_1608Metric; Voltage 25 VDC; Tolerance ±10%; MPN CGA3E3X7R1E474K080AE
C49, C53: 47nF 50V X7R; C_0603_1608Metric; Voltage 50 VDC; Tolerance ±10%; MPN CGA3E2X7R1H473K080AE
C92, C251: 4.7uF 16V X7R; C_0805_2012Metric; Voltage 16 VDC; Tolerance ±10%; MPN CGA4J3X7R1C475K125AE
C180: 10uF 25V X7R; C_1206_3216Metric; Voltage 25 VDC; Tolerance ±10%; MPN CGA5L1X7R1E106K160AE
C181, C188, C189: 22uF 10V X7R; C_1206_3216Metric; Voltage 10 VDC; Tolerance ±10%; MPN GCJ31CR71A226KE01L
C182: 22pF 50V C0G; C_0603_1608Metric; Voltage 50 VDC; Tolerance ±5%; MPN CGA3E2C0G1H220J080AA
C186, C236, C237, C238: 22uF 25V X7R; C_1210_3225Metric; Voltage 25 VDC; Tolerance ±20%; MPN CGA6P3X7R1E226M250AE
C191, C244: 1uF 25V X7R; C_0603_1608Metric; Voltage 25 VDC; Tolerance ±10%; MPN CGA3E1X7R1E105K080AE
C192: 3.9nF 100V C0G; C_0603_1608Metric; Voltage 100 VDC; Tolerance ±5%; MPN CGA3E1C0G2A392J080AE
C235, C239: 10uF 25V X7S; C_0805_2012Metric; Voltage 25 VDC; Tolerance ±10%; MPN GCJ21BC71E106KE02L
C241, C242, C243: 1nF 100V C0G; C_0603_1608Metric; Voltage 100 VDC; Tolerance ±5%; MPN CGA3E2C0G2A102J080AE
C245, C248: 10uF 10V X7R; C_0805_2012Metric; Voltage 10 VDC; Tolerance ±10%; MPN GCJ21BR71A106KE01L
C247, C250: 1uF 50V X7R; C_0805_2012Metric; Voltage 50 VDC; Tolerance ±10%; MPN CGA4J3X7R1H105K125AE
D2: ASMT-RF45-AN002 YELLOW GREEN; LED_0603_1608Metric; MPN ASMT-RF45-AN002
F1: 5.0A Ihold @23C / 24V PTC; Fuse_2920_7451Metric; MPN 2920L500/24SLDR
FB20, FB21: 600Ω @ 100MHz, 1.4A AEC-Q200; FB_Murata_BLM21_2.0x1.25mm; MPN BLM21PG601SH1D
J20: 2S_PACK_BALANCE; Molex_Micro-Fit_3.0_43650-0300_1x03_P3.00mm_Horizontal; MPN 43650-0300
L1: 2.2uH XAL7030-222MEC; L_Coilcraft_XAL7030-222; MPN XAL7030-222MEC
L20: 1.5uH XFL4020-152MEC; L_Coilcraft_XxL4020; MPN XFL4020-152MEC
NTC1: NCP15XH103F03RC; R_0402_1005Metric; MPN NCP15XH103F03RC
NTC2: NCP15XH103F03RC 10k B3380; R_0402_1005Metric; MPN NCP15XH103F03RC
Q3, Q4, Q5: CSD18540Q5B; VSON-CLIP-8_DNK_5x6mm; MPN CSD18540Q5B
R6, R9, R222: 1k; R_0603_1608Metric; Tolerance ±1%; MPN CRCW06031K00FKEA
R7, R8, R23: 100; R_0603_1608Metric; Tolerance ±1%; MPN CRCW0603100RFKEA
R10: 10; R_0603_1608Metric; Tolerance ±1%; MPN CRCW060310R0FKEA
R11, R12: 68; R_1206_3216Metric; Tolerance ±1%; MPN CRCW120668R0FKEAHP
R13: 5m 1% 1W; R_2512_6332Metric; Tolerance ±1%; MPN WSL2512R0050FEA
R20: 100R 1%; R_0603_1608Metric; Tolerance 1%; MPN CRCW0603100RFKEA
R24, R29, R30, R31, R37, R38, R39, R221, R240: 10k; R_0603_1608Metric; Tolerance ±1%; MPN CRCW060310K0FKEA
R25: 5.23k 1%; R_0603_1608Metric; Tolerance ±1%; MPN CRCW06035K23FKEA
R26: 30.1k 1%; R_0603_1608Metric; Tolerance ±1%; MPN CRCW060330K1FKEA
R28: 2k2; R_0603_1608Metric; Tolerance ±1%; MPN CRCW06032K20FKEA
R35: 8.2k; R_0603_1608Metric; Tolerance ±1%; MPN CRCW06038K20FKEA
R223: 47k 1%; R_0603_1608Metric; Tolerance ±1%; MPN CRCW060347K0FKEA
R224: 37.4k 1%; R_0603_1608Metric; Tolerance ±1%; MPN CRCW060337K4FKEA
R228: 220k; R_0603_1608Metric; Tolerance ±1%; MPN CRCW0603220KFKEA
R229, R244, R245, R246, R247, R248: 100k; R_0603_1608Metric; Tolerance ±1%; MPN CRCW0603100KFKEA
TP1: TestPoint_Small; TestPoint_Pad_D1.0mm
TP20: AUX5_PG; TestPoint_Pad_D1.0mm
U6: BQ25798RQMR; IC_BQ25798RQMR; PARTREV B
U7: MAX17320G22+; TQFN-24-1EP_4x4mm_P0.5mm_EP2.6x2.6mm; MPN MAX17320G22+
U8: RPL-3.0-R; LGA-10_RECOM_RPL-3.0_3x3mm; MPN RPL-3.0-R
U10: TPSM863253RDXR; Texas_RDX0007A_QFN-FCMOD-7-3.3x4mm-P0.5mm_4EP_NoVias; MPN TPSM863253RDXR
U11: TPS22997RYZR; Texas_RYZ0010A_WQFN-HR-10_2x1.5mm_P0.5mm; MPN TPS22997RYZR
U20: TPS630701RNMR (5V fixed); VQFN-HR-15_RNM_2.5x3mm_P0.5mm; MPN TPS630701RNMR
U21, U22, U23: TPS22918DBVR; SOT-23-6_DBV; MPN TPS22918DBVR

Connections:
+1V8_AON: C181.1, C182.1, C191.1, R222.2, R223.1, U8.5 (VOUT), U11.2 (VIN), U11.3 (VIN); also elsewhere on the board
+1V8_RUN: U11.6 (QOD), U11.7 (VOUT), U11.8 (VOUT); also elsewhere on the board
+3V3_GNSS_CLEAN: C248.1, C249.1, FB20.1; also elsewhere on the board
+3V3_IMU_CLEAN: C251.1, C252.1, FB21.1; also elsewhere on the board
+3V3_RADIO_SW: C245.1, C246.1, U21.5 (QOD), U21.6 (VOUT); also elsewhere on the board
+5V_AUX: C236.1, C237.1, C238.1, C239.1, U20.5 (FB), U20.7 (VOUT), U20.8 (VOUT); also elsewhere on the board
/Power/AUX5_EN: R244.1, U20.14 (EN); also elsewhere on the board
/Power/AUX_SW1: L20.2, U20.11 (L1)
/Power/AUX_SW2: L20.1, U20.9 (L2)
/Power/AUX_VAUX: C240.1, U20.3 (VAUX)
/Power/BAT_ALRT: R37.1, U7.7 (ALRT); also elsewhere on the board
/Power/BQ_BATP_SENSE: R23.1, U6.18 (BATP)
/Power/BQ_BTST1: C49.2, U6.4 (BTST1)
/Power/BQ_BTST2: C53.2, U6.19 (BTST2)
/Power/BQ_PMID: C86.2, C87.2, C88.2, C91.2, U6.29 (PMID)
/Power/BQ_PROG_SET: R35.2, U6.20 (PROG)
/Power/BQ_QON_TP: TP1.1 (1_1), U6.12 (~QON)
/Power/BQ_STAT: R28.1, U6.1 (STAT)
/Power/BQ_STAT_LED: D2.1 (K), R28.2
/Power/BQ_SW1: C49.1, L1.1, U6.28 (SW1)
/Power/BQ_SW2: C53.1, L1.2, U6.26 (SW2)
/Power/BUCK_3V3_EN: R228.2, R229.1, U10.6 (EN)
/Power/BUCK_3V3_PG: R221.2, U8.1 (CTRL), U10.5 (PG); also elsewhere on the board
/Power/CELL_MID: J20.2, R12.1
/Power/CHG_INT: R31.1, U6.21 (~INT); also elsewhere on the board
/Power/GNSS_EN: R247.1, U22.3 (ON); also elsewhere on the board
/Power/GNSS_EN_CT: C242.1, U22.4 (CT)
/Power/GNSS_SW_RAW: C247.1, FB20.2, U22.5 (QOD), U22.6 (VOUT)
/Power/IMU_EN: R248.1, U23.3 (ON); also elsewhere on the board
/Power/IMU_EN_CT: C243.1, U23.4 (CT)
/Power/IMU_SW_RAW: C250.1, FB21.2, U23.5 (QOD), U23.6 (VOUT)
/Power/MAX_AOLDO: C17.1, U7.12 (AOLDO)
/Power/MAX_CELL1_SENSE: C8.2, C12.1, R12.2, U7.21 (CELL1)
/Power/MAX_IN_SENSE: C13.2, C14.1, R10.2, U7.1 (IN)
/Power/MAX_REG2: C16.1, U7.17 (REG2)
/Power/MAX_REG3: C15.1, U7.13 (REG3)
/Power/MAX_TH1_NTC: NTC1.2, U7.10 (TH1)
/Power/MAX_TOP_SENSE: C8.1, R11.2, U7.22 (CELL2), U7.23 (CELL3), U7.24 (BATTS)
/Power/PACK_POS: C7.1, F1.2, Q4.1 (S), Q4.2 (S), Q4.3 (S), R10.1, R11.1
/Power/PACK_POS_CONN: F1.1, J20.1
/Power/PMIC_SCL: R30.1, R39.1, U6.14 (SCL), U7.8 (SCL/OD); also elsewhere on the board
/Power/PMIC_SDA: R29.1, R38.1, U6.15 (SDA), U7.9 (SDA/DQ); also elsewhere on the board
/Power/PWR_ON: U11.10 (ON); also elsewhere on the board
/Power/RADIO_EN: R246.1, U21.3 (ON); also elsewhere on the board
/Power/REGN: C92.2, R24.2, R25.1, U6.5 (REGN)
/Power/RPL_FB: C182.2, R223.2, R224.1, U8.7 (FB)
/Power/RPL_SENSE: R222.1, U8.6 (+Sense)
/Power/RUN_QOD: C192.1, U11.9 (CT)
/Power/vpack+: Q3.5 (D), Q3.6 (D), Q3.7 (D), Q3.8 (D), Q5.1 (S), Q5.2 (S), Q5.3 (S), R6.1, R23.2, R240.1
GND1: C12.2, C14.2, C15.2, C16.2, C17.2, C18.2, J20.3, NTC1.1, R9.1, R13.1, U7.15 (CSP), U7.16 (TH2), U7.18 (TH3), U7.19 (TH4), U7.20 (GND), U7.25 (EPAD)
unnamed: C84.1, C85.1, Q3.1 (S), Q3.2 (S), Q3.3 (S), U6.22 (BAT), U6.23 (BAT)
unnamed: Q3.4 (G), R20.2
unnamed: Q4.5 (D), Q4.6 (D), Q4.7 (D), Q4.8 (D), Q5.5 (D), Q5.6 (D), Q5.7 (D), Q5.8 (D)
unnamed: C7.2, Q4.4 (G), R7.1
unnamed: Q5.4 (G), R8.1
unnamed: R24.1, U6.17 (ILIM_HIZ)
unnamed: R20.1, U6.24 (SDRV)
unnamed: NTC2.1, R25.2, R26.2, U6.16 (TS)
unnamed: R7.2, U7.3 (CHG)
unnamed: C13.1, U7.2 (CP)
unnamed: R8.2, U7.4 (DIS)
unnamed: C18.1, R6.2, U7.6 (PCKP)
unnamed: R9.2, U7.11 (PFAIL)
unnamed: R240.2, U7.5 (ZVC)
unnamed: R245.2, TP20.1 (1_1), U20.2 (PG)
unnamed: C241.1, U21.4 (CT)
VBUS_PD: C9.2, C10.2, C11.2, C42.2, U6.2 (VBUS), U6.3 (VBUS), U6.8 (VAC2), U6.9 (VAC1); also elsewhere on the board
VSYS_RAW: C56.2, C62.2, C81.2, C82.2, C83.2, C93.2, C180.1, C186.1, C187.1, C233.1, C234.1, C235.1, R228.1, U6.25 (SYS), U8.2 (VIN), U10.1 (VIN), U20.12 (VIN), U20.13 (VIN)

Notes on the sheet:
3V3 branches: RADIO load-switched; GNSS/IMU load-switched then C-FB-C filtered.
5 V AUX: TPS630701 fixed buck-boost; AUX5_EN controls EN; power-save mode selected.
POWER TREE — REGULATOR STAGES VSYS_RAW -> U10 (3.3 V) -> +3V3_MAIN; open-drain PG drives BUCK_3V3_PG. VSYS_RAW -> U8 (1.8 V) -> +1V8_AON; CTRL = BUCK_3V3_PG with +3V3_MAIN pull-up. VSYS_RAW -> U20 (fixed 5 V buck-boost) -> +5V_AUX; AUX5_EN controls EN. Validate all rails across the approved loaded 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
1.8 V RUN LOAD SWITCH — TPS22997RYZR
+1V8_AON -> U11 -> +1V8_RUN; ON = STM32 PWR_ON. C192 = 3.9nF: about 1.05ms 10–90% rise at 1.8V. QOD tied to VOUT for fast discharge; PG unused.
COMMISSIONING - BQ25798: RPROG=8.2k selects 2S / 750kHz at POR; charge current remains at the 1A default until firmware raises it only after thermal and cell checks pass.
VBUS HOT-PLUG: TVS2200 clamps VBUS_PD and populated 2.2R/2.2uF snubber damps cable ringing; scope and tune after worst-cable testing. TVS2200 is for SPR <=20V / 21V ceiling only - never enable 28V EPR.
PMIC_SCL/SDA direct host link is valid across only R13=5mOhm Kelvin shunt; preserve GND1 (cell/CSP) / GND (system/CSN) separation and do not bridge elsewhere.
COMMISSIONING - MAX17320 NVM: before enabling charge, program and validate nPackCfg for 2S (NCELLS=0), one 10k TH1, nRSense=5mOhm, and the selected 21700 cell model/capacity/protection limits. Wiring alone does not define these settings.
PACK TEMPERATURE: initial build must thermally couple both NTC1 (MAX17320 TH1) and fitted NTC2 (BQ25798 TS) to the pack. Keep BQ TS_IGNORE=0; configure MAX for the NCP15 10k/B3380 model; validate hot/cold thresholds before raising charge current.
MAX17320 2S: CELL1=cell midpoint; CELL2=CELL3=BATTS=filtered pack top, per datasheet Figure 24 / Note 10.
1.8 V AON BUCK — RPL-3.0-R
5 V AUX BUCK-BOOST — TPS630701RNMR
3.3 V MAIN BUCK — TPSM863253RDXR
U10: SW pin 2 DNC; VOS pin 7 to VOUT. EN 220k/100k (2M internal pull-down): ~4.14V turn-on, EN <=5.14V at VIN=17V.
PRE-LAYOUT HOLD: verify Q1-Q5/F1 current, SOA, copper, thermal vias and connector temperature rise at worst-case charge/load current.

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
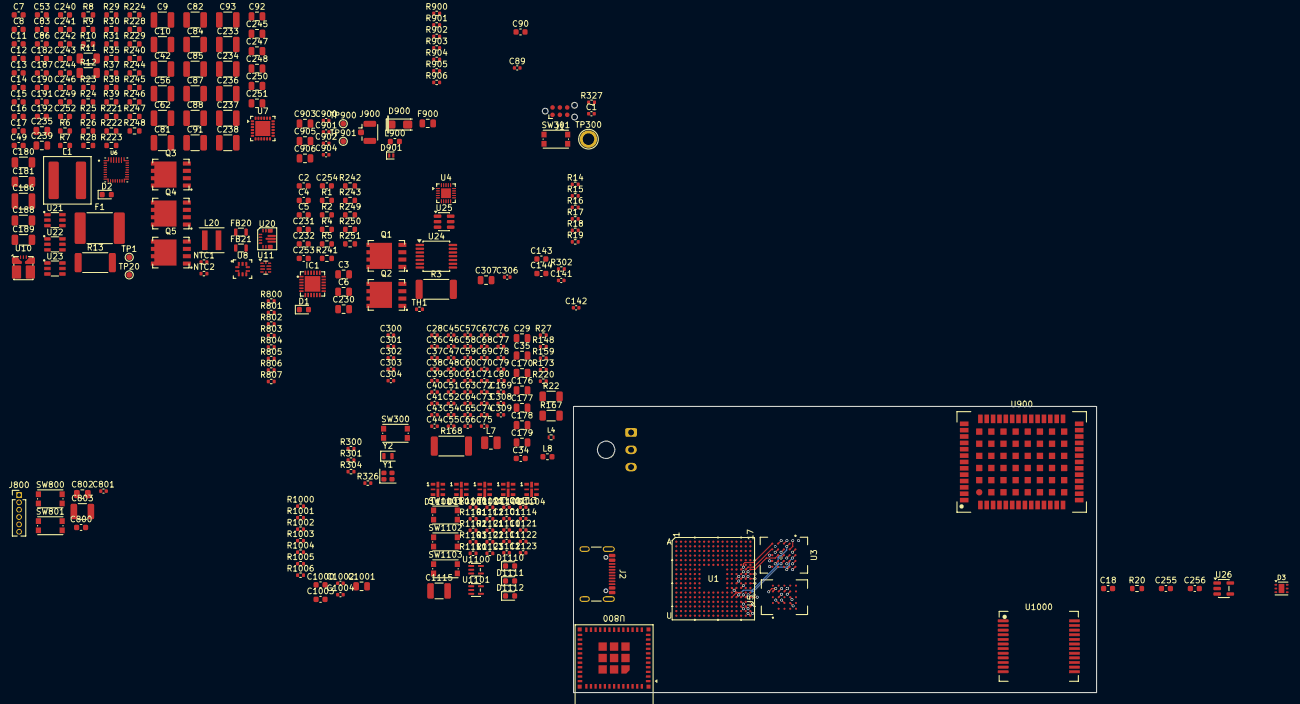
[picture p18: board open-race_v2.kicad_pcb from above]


Board: 8 copper layers, 90.5 x 49.5 mm, 337 parts (7 on the bottom side), 225 nets.

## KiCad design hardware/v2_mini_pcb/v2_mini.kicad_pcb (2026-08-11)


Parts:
C13, C15, C22: 100nF; C_0402_1005Metric; Voltage 16V; Tolerance 10%; MPN CL05B104KO5NNNC; LCSC C1525
C14, C23: 10uF; C_0603_1608Metric; Voltage 10V; Tolerance 10%; MPN CL10A106KP8NNND; DigiKey_PN 1276-CL10A106KP8NNNDCT-ND
J2: GTFP08441BEU; AMPHENOL_GTFP08441BEU; PARTREV F
J3: SFV24R-2STE1HLF; AMPHENOL_SFV24R-2STE1HLF; PARTREV C
Q1: NTNS3164NZT5G; SOT-883; MPN NTNS3164NZT5G
R4: 15; R_0402_1005Metric; MPN RC0402FR-0715RL
R5: 100k; R_0402_1005Metric; Voltage 50V; Tolerance 1%; MPN RC0402FR-07100KL; DigiKey_PN 311-100KLRCT-ND
R6, R7: 10k; R_0402_1005Metric; Voltage 50V; Tolerance 1%; MPN RC0402FR-0710KL; DigiKey_PN 311-10.0KLRCT-ND
R19: 22; R_0402_1005Metric; Voltage 50V; Tolerance 1%; MPN RC0402FR-0722RL; DigiKey_PN 311-22.0LRCT-ND

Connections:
+3V3: C13.2, C14.2, C15.2, C22.2, C23.2, J2.4 (VDD), J3.1, J3.4, J3.5, J3.6, R6.1, R7.1; also elsewhere on the board
/ESP32-S31 MCU/LCD_BACK: Q1.1 (G), R5.2; also elsewhere on the board
/ESP32-S31 MCU/LCD_CSN: J3.8, R7.2; also elsewhere on the board
/ESP32-S31 MCU/LCD_DC: J3.10; also elsewhere on the board
/ESP32-S31 MCU/LCD_RN: J3.7, R6.2; also elsewhere on the board
/ESP32-S31 MCU/LCD_SCLK: J3.9; also elsewhere on the board
/ESP32-S31 MCU/LCD_SDA: J3.12; also elsewhere on the board
/ESP32-S31 MCU/LCD_TE: J3.21; also elsewhere on the board
/ESP32-S31 MCU/SD_CLK: R19.1; also elsewhere on the board
/ESP32-S31 MCU/SD_CMD: J2.3 (CMD); also elsewhere on the board
/ESP32-S31 MCU/SD_D0: J2.7 (DAT0); also elsewhere on the board
/ESP32-S31 MCU/SD_D1: J2.8 (DAT1); also elsewhere on the board
/ESP32-S31 MCU/SD_D2: J2.1 (DAT2); also elsewhere on the board
/ESP32-S31 MCU/SD_D3: J2.2 (CD/DAT3); also elsewhere on the board
GND: C13.1, C14.1, C15.1, C22.1, C23.1, J2.6 (VSS), J2.G1 (SHIELD_GND), J2.G2 (SHIELD_GND), J2.G3 (SHIELD_GND), J3.3, J3.11, J3.13, J3.14, J3.15, J3.16, J3.17, J3.18, J3.19, J3.20, J3.23, J3.24, J3.S1 (SHIELD), J3.S2 (SHIELD__1), Q1.2 (S), R5.1; also elsewhere on the board
unnamed: J2.5 (CLK), R19.2
unnamed: J3.2, R4.2
unnamed: Q1.3 (D), R4.1

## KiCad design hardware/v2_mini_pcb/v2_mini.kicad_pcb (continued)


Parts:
C16: 1uF; C_0603_1608Metric; Voltage 35V; Tolerance 10%; MPN MCASG168AB7105KTNA01; DigiKey_PN 587-MCASG168AB7105KTNA01CT-ND
C17: 47nF; C_0402_1005Metric; Voltage 25V; Tolerance 10%; MPN GRM155R71E473KA88D; DigiKey_PN 490-3254-1-ND
C18: 4.7uF; C_0603_1608Metric; Voltage 25V; Tolerance 10%; MPN GRM188R61E475KE11D; DigiKey_PN 490-7203-1-ND
C19: 100nF; C_0402_1005Metric; Voltage 50V; Tolerance 10%; MPN CL05B104KB54PNC; LCSC C307331
C20: 10uF; C_0805_2012Metric; Voltage 35V; Tolerance 10%; MPN C2012X5R1V106K125AC; DigiKey_PN 445-14418-1-ND
C21, C41: 100nF; C_0402_1005Metric; Voltage 16V; Tolerance 10%; MPN CL05B104KO5NNNC; LCSC C1525
C25, C26: DNP; C_0402_1005Metric; MPN DNP; not fitted
C30, C31, C32: 22uF; C_0805_2012Metric; Voltage 25V; Tolerance 20%; MPN CC0805MKX5R8BB226; DigiKey_PN 311-1903-1-ND
C33: 10uF; C_0603_1608Metric; Voltage 10V; Tolerance 10%; MPN CL10A106KP8NNND; DigiKey_PN 1276-CL10A106KP8NNNDCT-ND
C34: 22uF; C_0603_1608Metric; Voltage 10V; Tolerance 20%; MPN GRT188R61A226ME13D; DigiKey_PN 490-GRT188R61A226ME13DCT-ND
FB1, FB2: BLM21SP601SN1D; L_0805_2012Metric; MPN MPZ2012S601ATD25
J4: Battery; HRS_DF58-2P-1.2V_21_; PARTREV Apr.1.2022
J6: USB4105-GF-A; GCT_USB4105-GF-A; PARTREV B4
L4: 1uH; L_1008_2520Metric; MPN DFE252012F-1R0M=P2
L5: 0.47uH; L_Samsung_CIGT201610; Tolerance ±20%; MPN CIGT201610EHR47MNE; DigiKey_PN 1276-6902-1-ND
R3, R22, R23, R27, R34, R35: 10k; R_0402_1005Metric; Voltage 50V; Tolerance 1%; MPN RC0402FR-0710KL; DigiKey_PN 311-10.0KLRCT-ND
R11, R12: 5.1k; R_0402_1005Metric; Voltage 50V; Tolerance 1%; MPN RC0402FR-075K1L; DigiKey_PN 311-5.10KLRCT-ND
R13: 5.62k; R_0402_1005Metric; MPN RC0402FR-075K62L
R14: 5.23k; R_0402_1005Metric; MPN RC0402FR-075K23L
R15: 30.1k; R_0402_1005Metric; MPN CRCW040230K1FKED
R25: 511k; R_0603_1608Metric; MPN RC0603FR-07511KL
R26: 91k; R_0603_1608Metric; MPN RC0603FR-0791KL
R28: 75k; R_0402_1005Metric; Voltage 50V; Tolerance 1%; MPN RMCF0402FT75K0; DigiKey_PN RMCF0402FT75K0CT-ND
R29: 100k; R_0402_1005Metric; Voltage 50V; Tolerance 1%; MPN RC0402FR-07100KL; DigiKey_PN 311-100KLRCT-ND
R32, R33: 22k; R_0402_1005Metric; Voltage 50V; Tolerance 1%; MPN RC0402FR-0722KL; DigiKey_PN 311-22.0KLRCT-ND
SW7: SW_Push; SW_SPST_B3U-1000P; MPN B3U-1000P
TH1: 103KT1608T-1P; R_0603_1608Metric; MPN NCU18XH103F60RB
U6: TPD4EUSB30; USON-10_2.5x1.0mm_P0.5mm; MPN TPD4EUSB30DQAR
U7: MAX16169AALTA+T; 21-0164_L622&plus_1_ADI; MPN MAX16169AALTA+T
U8: BQ25622ERYKR; WQFN-HR18__RYK_TEX; MPN BQ25622ERYKR
U9: MAX17048G_T10; SON50P200X200X80-9N; MPN MAX17048G+T10
U10: TPS63802DLAR; VREG_TPS63802DLAR; PARTREV B

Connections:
+3V3: C34.2, FB1.1, FB2.1, R3.1, R22.2, R23.2, R25.1, R27.2, R34.1, R35.1, U10.6 (VOUT); also elsewhere on the board
+3V3_GNSS: FB1.2; also elsewhere on the board
+3V3_IMU: FB2.2; also elsewhere on the board
/ESP32-S31 MCU/BAT_ALRT: R3.2, U9.5 (~ALERT); also elsewhere on the board
/ESP32-S31 MCU/CHG_INT: R23.1, U8.11 (INT); also elsewhere on the board
/ESP32-S31 MCU/CHG_PG: R27.1, U8.3 (PG); also elsewhere on the board
/ESP32-S31 MCU/CHG_STAT: R22.1, U8.10 (STAT); also elsewhere on the board
/ESP32-S31 MCU/POW_SCL: U8.13 (SCL), U9.7 (SCL); also elsewhere on the board
/ESP32-S31 MCU/POW_SDA: U8.12 (SDA), U9.8 (SDA); also elsewhere on the board
/ESP32-S31 MCU/PWR_INT_N: R35.2, U7.5 (*INT); also elsewhere on the board
/ESP32-S31 MCU/PWR_KILL_N: R34.2, U7.4 (*CLR); also elsewhere on the board
/ESP32-S31 MCU/USB_CC1: R33.2; also elsewhere on the board
/ESP32-S31 MCU/USB_CC2: R32.2; also elsewhere on the board
/ESP32-S31 MCU/USB_DN: C25.1, J6.A7 (DN1), J6.B7 (DN2), U6.1 (D1+), U6.10 (NC); also elsewhere on the board
/ESP32-S31 MCU/USB_DP: C26.1, J6.A6 (DP1), J6.B6 (DP2), U6.2 (D1-), U6.9 (NC); also elsewhere on the board
/ESP32-S31 MCU/USB_VBUS_S: R28.1, R29.2; also elsewhere on the board
/Power + USB/3V3_RAW: C30.2, C31.2, C33.2, C41.2, L4.2, U7.1 (VCC), U8.9 (SYS), U10.10 (VIN)
/Power + USB/GATE_EN: U7.6 (OUT), U10.1 (EN)
/Power + USB/USB_CC1_pre: J6.A5 (CC1), R11.2, R33.1, U6.4 (D2+), U6.7 (NC)
/Power + USB/USB_CC2_pre: J6.B5 (CC2), R12.2, R32.1, U6.5 (D2-), U6.6 (NC)
GND: C16.1, C18.2, C19.1, C20.1, C21.2, C25.2, C26.2, C30.1, C31.1, C32.2, C33.1, C34.1, C41.1, J4.2, J6.A1_B12 (GND), J6.B1_A12 (GND__1), J6.SH1 (SHELL_GND), J6.SH2 (SHELL_GND__1), J6.SH3 (SHELL_GND__2), J6.SH4 (SHELL_GND__3), R11.1, R12.1, R13.1, R15.1, R26.2, R29.1, SW7.1, TH1.1, U6.3 (GND), U6.8 (GND), U7.2 (GND), U8.14 (CE), U8.15 (GND), U9.1 (CTG), U9.4 (GND), U9.6 (QSTRT), U9.9 (EP), U10.2 (MODE), U10.3 (AGND), U10.8 (GND); also elsewhere on the board
unnamed: C16.2, J6.A4_B9 (VBUS), J6.B4_A9 (VBUS__1), R28.2, U8.18 (VBUS)
unnamed: SW7.2, U7.3 (PB_IN/*PB_IN)
unnamed: C21.1, C32.1, J4.1, U8.8 (BAT), U9.2 (CELL), U9.3 (VDD)
unnamed: C17.1, U8.1 (BTST)
unnamed: R13.2, U8.4 (ILIM)
unnamed: C19.2, C20.2, U8.17 (PMID)
unnamed: C18.1, U8.2 (REGN)
unnamed: C17.2, L4.1, U8.16 (SW)
unnamed: R14.1, R15.2, TH1.2, U8.6 (TS)
unnamed: R14.2, U8.5 (TS_BIAS)
unnamed: R25.2, R26.1, U10.4 (FB)
unnamed: L5.1, U10.9 (L1)
unnamed: L5.2, U10.7 (L2)


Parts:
C27: 10uF; C_0603_1608Metric; Voltage 10V; Tolerance 10%; MPN CL10A106KP8NNND; DigiKey_PN 1276-CL10A106KP8NNNDCT-ND
C28: 22uF; C_0805_2012Metric; Voltage 25V; Tolerance 20%; MPN CC0805MKX5R8BB226; DigiKey_PN 311-1903-1-ND
C29: 100nF; C_0402_1005Metric; MPN CL05B104KO5NNNC
D32, D33, D34, D35: MSL0402RGBU1; LED_MSL04_ROM; MPN MSL0402RGBU1
L2: 1uH; L_1008_2520Metric; MPN DFE252012F-1R0M=P2
SW3, SW4, SW5, SW6: SW_Push; SW_SPST_B3U-1000P; MPN B3U-1000P
U4: LP5813ADRRR; IC_LP5813ADRRR; PARTREV C
U5: TCA9536ADTMR; X2SON8_DTM_TEX; MPN TCA9536ADTMR

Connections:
+3V3: C27.2, C29.2, L2.2, U4.12 (VIN), U5.7 (VCC); also elsewhere on the board
/ESP32-S31 MCU/LED_EN: U4.11 (EN); also elsewhere on the board
/ESP32-S31 MCU/POW_SCL: U4.5 (SCL), U5.5 (SCL); also elsewhere on the board
/ESP32-S31 MCU/POW_SDA: U4.6 (SDA), U5.6 (SDA); also elsewhere on the board
GND: C27.1, C28.1, C29.1, SW3.1, SW4.1, SW5.1, SW6.2, U4.3 (GND), U4.4 (SYNC), U4.13 (GND), U5.3 (GND); also elsewhere on the board
unnamed: D32.4 (R_A), D32.5 (G_A), D32.6 (B_A), D33.3 (R_K), D34.2 (G_K), D35.1 (B_K), U4.10 (OUT0)
unnamed: D32.1 (B_K), D33.2 (G_K), D34.4 (R_A), D34.5 (G_A), D34.6 (B_A), D35.3 (R_K), U4.7 (OUT3)
unnamed: D32.2 (G_K), D33.1 (B_K), D34.3 (R_K), D35.4 (R_A), D35.5 (G_A), D35.6 (B_A), U4.9 (OUT1)
unnamed: D32.3 (R_K), D33.4 (R_A), D33.5 (G_A), D33.6 (B_A), D34.1 (B_K), D35.2 (G_K), U4.8 (OUT2)
unnamed: L2.1, U4.1 (SW)
unnamed: C28.2, U4.2 (VOUT)
unnamed: SW3.2, U5.1 (P0)
unnamed: SW6.1, U5.8 (P1)
unnamed: SW4.2, U5.2
unnamed: SW5.2, U5.4 (P3/INT)


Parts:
C36: 10uF; C_0603_1608Metric; Voltage 10V; Tolerance 10%; MPN CL10A106KP8NNND; DigiKey_PN 1276-CL10A106KP8NNNDCT-ND
C37, C39: 1uF; C_0402_1005Metric; Voltage 25V; Tolerance 10%; MPN CL05A105KA5NQNC; LCSC C52923
C38, C40: 100nF; C_0402_1005Metric; Voltage 16V; Tolerance 10%; MPN CL05B104KO5NNNC; LCSC C1525
R20: 10k; R_0402_1005Metric; Voltage 50V; Tolerance 1%; MPN RC0402FR-0710KL; DigiKey_PN 311-10.0KLRCT-ND
U3: SCH16T-K01-1; XDCR_SCH16T-K01-1; PARTREV 6

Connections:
+3V3_IMU: C38.2, C39.2, C40.2, R20.1, U3.8 (V3P3), U3.17 (V3P3), U3.18 (VDDIO); also elsewhere on the board
/ESP32-S31 MCU/IMU_CS_N: U3.22 (CS); also elsewhere on the board
/ESP32-S31 MCU/IMU_DRDY: U3.20 (DRY_SYNC); also elsewhere on the board
/ESP32-S31 MCU/IMU_MISO: U3.19 (MISO); also elsewhere on the board
/ESP32-S31 MCU/IMU_MOSI: U3.23 (MOSI); also elsewhere on the board
/ESP32-S31 MCU/IMU_RESET_N: R20.2, U3.6 (~EXTRES); also elsewhere on the board
/ESP32-S31 MCU/IMU_SCLK: U3.21 (SCK); also elsewhere on the board
GND: C36.2, C37.2, C38.1, C39.1, C40.1, U3.1 (HEATSINK), U3.3 (TA9), U3.4 (TA8), U3.5 (RESERVED), U3.7 (RESERVED), U3.9 (GND), U3.12 (GND), U3.13 (GND), U3.16 (GND), U3.24 (HEATSINK); also elsewhere on the board
unnamed: C36.1, U3.10 (VREGA2), U3.11 (VREGA)
unnamed: C37.1, U3.14 (VREGD2), U3.15 (VREGD)


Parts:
C1, C3: 100pF; C_0402_1005Metric; Voltage 50V; Tolerance 5%; MPN GRM1555C1H101JA01D; DigiKey_PN 490-5922-1-ND
C2, C8: 100nF; C_0402_1005Metric; Voltage 16V; Tolerance 10%; MPN CL05B104KO5NNNC; LCSC C1525
C4, C5, C6, C7, C35: 10uF; C_0805_2012Metric; Voltage 35V; Tolerance 10%; MPN C2012X5R1V106K125AC; DigiKey_PN 445-14418-1-ND
D1: Texas_DPY0002A_0.6x1mm_P0.65mm; MPN TPD1E0B04DPYR
D2: D_SOD-323F; MPN ESDS311DYFR
J1: Conn_Coaxial; U.FL_Hirose_U.FL-R-SMT-1_Vertical; MPN U.FL-R-SMT-1(01)
L1: 68nH; L_0603_1608Metric; MPN LQW18AN68NJ00D
R1, R2, R24: 10k; R_0402_1005Metric; Voltage 50V; Tolerance 1%; MPN RC0402FR-0710KL; DigiKey_PN 311-10.0KLRCT-ND
U1: UM980; XCVR_UM980; PARTREV R1.9

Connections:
+3V3_GNSS: C2.1, C3.1, C4.2, C5.2, C6.2, C7.2, C8.2, C35.1, D2.1 (A1), L1.2, R1.1, R2.1, R24.2, U1.33 (VCC), U1.34 (VCC), U1.36 (V_BCKP); also elsewhere on the board
/ESP32-S31 MCU/GNSS_ERR: U1.21 (ERR_STAT); also elsewhere on the board
/ESP32-S31 MCU/GNSS_PPS: U1.53 (PPS); also elsewhere on the board
/ESP32-S31 MCU/GNSS_PVT: U1.19 (PVT_STAT); also elsewhere on the board
/ESP32-S31 MCU/GNSS_RESETN: R24.1, U1.49 (~RESET); also elsewhere on the board
/ESP32-S31 MCU/GNSS_RTK: U1.20 (RTK_STAT); also elsewhere on the board
/ESP32-S31 MCU/GNSS_RXD1: U1.43 (RXD1); also elsewhere on the board
/ESP32-S31 MCU/GNSS_RXD2: U1.26 (RXD2); also elsewhere on the board
/ESP32-S31 MCU/GNSS_TXD1: U1.42 (TXD1); also elsewhere on the board
/ESP32-S31 MCU/GNSS_TXD2: U1.27 (TXD2); also elsewhere on the board
GND: C2.2, C3.2, C4.1, C5.1, C6.1, C7.1, C8.1, C35.2, D1.1 (A1), D2.2 (A2), J1.2 (Ext), U1.1 (GND), U1.3 (GND), U1.12 (GND), U1.14 (GND), U1.32 (GND), U1.37 (GND), U1.41 (GND), U1.48 (GND), U1.EXP1 (EXP_1), U1.EXP2 (EXP_1), U1.EXP3 (EXP_1), U1.EXP4 (EXP_1), U1.EXP5 (EXP_1), U1.EXP6 (EXP_1), U1.EXP7 (EXP_1), U1.EXP8 (EXP_1), U1.EXP9 (EXP_1), U1.EXP10 (EXP_1), U1.EXP11 (EXP_1), U1.EXP12 (EXP_1), U1.EXP13 (EXP_1), U1.EXP14 (EXP_1), U1.EXP15 (EXP_1), U1.EXP16 (EXP_2), U1.EXP17 (EXP_2), U1.EXP18 (EXP_2), U1.EXP19 (EXP_2), U1.EXP20 (EXP_2), U1.EXP21 (EXP_2), U1.EXP22 (EXP_2), U1.EXP23 (EXP_2), U1.EXP24 (EXP_2), U1.EXP25 (EXP_2), U1.EXP26 (EXP_2), U1.EXP27 (EXP_2), U1.EXP28 (EXP_2), U1.EXP29 (EXP_2), U1.EXP30 (EXP_2), U1.EXP31 (EXP_3), U1.EXP32 (EXP_3), U1.EXP33 (EXP_3), U1.EXP34 (EXP_3), U1.EXP35 (EXP_3), U1.EXP36 (EXP_3), U1.EXP37 (EXP_3), U1.EXP38 (EXP_3), U1.EXP39 (EXP_3), U1.EXP40 (EXP_3), U1.EXP41 (EXP_3), U1.EXP42 (EXP_3), U1.EXP43 (EXP_3), U1.EXP44 (EXP_3), U1.EXP45 (EXP_3), U1.EXP46 (EXP_4), U1.EXP47 (EXP_4), U1.EXP48 (EXP_4); also elsewhere on the board
unnamed: C1.2, D1.2 (A2), J1.1 (In), L1.1
unnamed: R1.2, U1.28 (BIF)
unnamed: R2.2, U1.29 (BIF)
unnamed: C1.1, U1.2 (ANT_IN)

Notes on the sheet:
Route J1 to UM980 ANT_IN as a short 50 Ω trace over a continuous ground plane, with no plane gaps, unnecessary vias, sharp corners, branches or long stubs; calculate the trace geometry using the final PCB stack-up, keep the 100 pF C0G DC-blocking capacitor and 68 nH bias inductor immediately beside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


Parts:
C9, C11: 100nF; C_0402_1005Metric; Voltage 16V; Tolerance 10%; MPN CL05B104KO5NNNC; LCSC C1525
C10: 22uF; C_0805_2012Metric; Voltage 25V; Tolerance 20%; MPN CC0805MKX5R8BB226; DigiKey_PN 311-1903-1-ND
C12, C24: DNP; C_0402_1005Metric; MPN DNP; not fitted
H4, H5, H6, H7: MountingHole_Pad; MountingHole_2.2mm_M2_Pad
J5: TC2030; Tag-Connect_TC2030-IDC-NL_2x03_P1.27mm_Vertical; MPN TC2030-IDC-NL (mating cable)
R8, R9: 10k; R_0402_1005Metric; Voltage 50V; Tolerance 1%; MPN RC0402FR-0710KL; DigiKey_PN 311-10.0KLRCT-ND
R10, R17, R30, R31: 22; R_0402_1005Metric; Voltage 50V; Tolerance 1%; MPN RC0402FR-0722RL; DigiKey_PN 311-22.0LRCT-ND
R16, R21: 5.1k; R_0402_1005Metric; Voltage 50V; Tolerance 1%; MPN RC0402FR-075K1L; DigiKey_PN 311-5.10KLRCT-ND
R18: 499; R_0402_1005Metric; MPN RC0402FR-07499RL
SW1, SW2: SW_Push; SW_SPST_B3U-1000P; MPN B3U-1000P
TP1, TP2: TestPoint; TestPoint_Pad_D1.0mm; MPN N/A (PCB test pad)
U2: ESP32-S31-WROOM-3; MPN ESP32-S31-WROOM-3-N16R16V

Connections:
+3V3: C9.2, C10.2, R8.1, R9.1, R16.1, R21.2, U2.3 (3V3), U2.4 (3V3); also elsewhere on the board
/ESP32-S31 MCU/BAT_ALRT: U2.6 (GPIO2); also elsewhere on the board
/ESP32-S31 MCU/CHG_INT: U2.8 (GPIO0/XTAL_32K_N); also elsewhere on the board
/ESP32-S31 MCU/CHG_PG: U2.51 (GPIO40); also elsewhere on the board
/ESP32-S31 MCU/CHG_STAT: U2.9 (GPIO1/XTAL_32K_P); also elsewhere on the board
/ESP32-S31 MCU/GNSS_ERR: U2.62 (GPIO52/ADC2_CH1_N); also elsewhere on the board
/ESP32-S31 MCU/GNSS_PPS: U2.52 (GPIO42/ADC1_CH0_N); also elsewhere on the board
/ESP32-S31 MCU/GNSS_PVT: U2.60 (GPIO50/ADC2_CH0_N); also elsewhere on the board
/ESP32-S31 MCU/GNSS_RESETN: U2.54 (GPIO44/ADC1_CH1_N); also elsewhere on the board
/ESP32-S31 MCU/GNSS_RTK: U2.61 (GPIO51/ADC2_CH0_P); also elsewhere on the board
/ESP32-S31 MCU/GNSS_RXD1: U2.57 (GPIO47/ADC1_CH2_P); also elsewhere on the board
/ESP32-S31 MCU/GNSS_RXD2: U2.59 (GPIO49/ADC1_CH3_P); also elsewhere on the board
/ESP32-S31 MCU/GNSS_TXD1: U2.56 (GPIO46/ADC1_CH2_N); also elsewhere on the board
/ESP32-S31 MCU/GNSS_TXD2: U2.58 (GPIO48/ADC1_CH3_N); also elsewhere on the board
/ESP32-S31 MCU/IMU_CS_N: U2.16 (GPIO10); also elsewhere on the board
/ESP32-S31 MCU/IMU_DRDY: U2.20 (GPIO14); also elsewhere on the board
/ESP32-S31 MCU/IMU_MISO: U2.19 (GPIO13); also elsewhere on the board
/ESP32-S31 MCU/IMU_MOSI: U2.17 (GPIO11); also elsewhere on the board
/ESP32-S31 MCU/IMU_RESET_N: U2.15 (GPIO9); also elsewhere on the board
/ESP32-S31 MCU/IMU_SCLK: U2.18 (GPIO12); also elsewhere on the board
/ESP32-S31 MCU/JTAG_DN: C24.1, J5.3, R30.2
/ESP32-S31 MCU/JTAG_DP: C12.1, J5.4, R31.2
/ESP32-S31 MCU/LCD_BACK: U2.10 (GPIO4); also elsewhere on the board
/ESP32-S31 MCU/LCD_CSN: U2.24 (GPIO18); also elsewhere on the board
/ESP32-S31 MCU/LCD_DC: U2.25 (GPIO19); also elsewhere on the board
/ESP32-S31 MCU/LCD_RN: U2.21 (GPIO15); also elsewhere on the board
/ESP32-S31 MCU/LCD_SCLK: U2.22 (GPIO16); also elsewhere on the board
/ESP32-S31 MCU/LCD_SDA: U2.23 (GPIO17); also elsewhere on the board
/ESP32-S31 MCU/LCD_TE: U2.11 (GPIO5); also elsewhere on the board
/ESP32-S31 MCU/LED_EN: U2.50 (GPIO39); also elsewhere on the board
/ESP32-S31 MCU/POW_SCL: R16.2, U2.12 (GPIO6); also elsewhere on the board
/ESP32-S31 MCU/POW_SDA: R21.1, U2.13 (GPIO7); also elsewhere on the board
/ESP32-S31 MCU/PWR_INT_N: U2.49 (GPIO38); also elsewhere on the board
/ESP32-S31 MCU/PWR_KILL_N: U2.14 (GPIO8); also elsewhere on the board
/ESP32-S31 MCU/SD_CLK: U2.31 (SDIO_CLK/GPIO24); also elsewhere on the board
/ESP32-S31 MCU/SD_CMD: U2.32 (SDIO_CMD/GPIO25); also elsewhere on the board
/ESP32-S31 MCU/SD_D0: U2.27 (SDIO_DATA0/GPIO20); also elsewhere on the board
/ESP32-S31 MCU/SD_D1: U2.28 (SDIO_DATA1/GPIO21); also elsewhere on the board
/ESP32-S31 MCU/SD_D2: U2.29 (SDIO_DATA2/GPIO22); also elsewhere on the board
/ESP32-S31 MCU/SD_D3: U2.30 (SDIO_DATA3/GPIO23); also elsewhere on the board
/ESP32-S31 MCU/USB_CC1: U2.53 (GPIO43/ADC1_CH0_P); also elsewhere on the board
/ESP32-S31 MCU/USB_CC2: U2.55 (GPIO45/ADC1_CH1_P); also elsewhere on the board
/ESP32-S31 MCU/USB_DN: R17.2; also elsewhere on the board
/ESP32-S31 MCU/USB_DP: R10.2; also elsewhere on the board
/ESP32-S31 MCU/USB_VBUS_S: U2.44 (GPIO35); also elsewhere on the board
GND: C9.1, C10.1, C11.1, C12.2, C24.2, H4.1 (1_1), H5.1 (1_1), H6.1 (1_1), H7.1 (1_1), J5.5, SW1.1, SW2.2, U2.1 (GND), U2.2 (GND), U2.26 (GND), U2.47 (GND), U2.48 (GND), U2.72 (GND), U2.73 (GND), U2.74 (GND), U2.75 (GND), U2.76 (GND), U2.77 (GND), U2.78 (GND), U2.79 (GND), U2.80 (GND), U2.81 (GND), U2.82 (GND), U2.83 (GND), U2.84 (GND), U2.85 (GND), U2.86 (GND), U2.87 (GND), U2.88 (GND), U2.89 (GND), U2.90 (GND), U2.92 (GND), U2.93 (GND), U2.94 (GND), U2.95 (GND), U2.96 (GND), U2.97 (GND), U2.98 (GND), U2.99 (GND); also elsewhere on the board
unnamed: R18.2, TP2.1 (1_1)
unnamed: C11.2, R8.2, SW1.2, U2.5 (EN)
unnamed: R30.1, U2.42 (GPIO33)
unnamed: R31.1, U2.43 (GPIO34)
unnamed: R9.2, SW2.1, U2.71 (GPIO61)
unnamed: TP1.1 (1_1), U2.69 (UART0_RXD/GPIO59)
unnamed: R18.1, U2.68 (UART0_TXD/GPIO58)
unnamed: R17.1, U2.41 (USB_DM)
unnamed: R10.1, U2.40 (USB_DP)



Board: 6 copper layers, 60.8 x 35.1 mm, 119 parts (47 on the bottom side), 93 nets.

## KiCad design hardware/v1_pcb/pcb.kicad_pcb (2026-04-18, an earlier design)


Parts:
BT1: Battery_Cell; JST_PH_S2B-PH-K_1x02_P2.00mm_Horizontal; not fitted
C1, C2, C4: 10uF; C_0805_2012Metric; LCSC GRM21BC71C106KE11L
C3: 0.1uF; C_0805_2012Metric; LCSC C0805C104K5RACTU
C5: 47pF; C_0402_1005Metric; LCSC GRM1555C1H470JA01D
C6, C7: 4.7uF; C_0805_2012Metric; LCSC CL21A475KAQNNNE
D1: LED; LED_0805_2012Metric; LCSC 150080VS75000
J1: Conn_Coaxial; U.FL_Molex_MCRF_73412-0110_Vertical; LCSC U.FL-R-SMT-1(10)
L1: 27nH; L_0402_1005Metric; LCSC LQG15HN27NJ02D
R1, R2, R5: 10k; R_0805_2012Metric; LCSC RC0805FR-0710KL
R3: 2k; R_0805_2012Metric; LCSC RC0805FR-072KL
R4: 1k; R_0805_2012Metric; LCSC RC0805FR-071KL
U1: XIAO-nRF52840-SMD; LCSC 102010448; not fitted
U2: NEO-M9V-20B; XCVR_NEO-M9V-20B; PARTREV C1; LCSC NEO-M9V-20B; not fitted
U3: AP2112K-3.3; SOT-23-5; LCSC AP2112K-3.3TRG1
U4: MCP73831-2-OT; SOT-23-5; LCSC MCP73831T-2ACI/OT

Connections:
/uart_rx: R2.1, U1.8 (P1.12_D7_RX), U2.20 (TXD/SPI_MISO)
/uart_tx: R1.1, U1.7 (P1.11_D6_TX), U2.21 (RXD/SPI_MOSI)
GND: BT1.2 (-), C1.2, C2.2, C3.1, C4.2, C6.1, C7.1, J1.2 (Ext), R3.2, U1.13 (GND), U1.33 (GND), U2.7 (V_USB), U2.10 (GND), U2.12 (GND), U2.13 (GND), U2.24 (GND), U3.2 (GND), U4.2 (V_{SS})
unnamed: BT1.1 (+), C1.1, C7.2, U1.32 (BAT), U3.1 (VIN), U3.3 (EN), U4.3 (V_{BAT})
unnamed: D1.2 (A), R4.1
unnamed: D1.1 (K), U4.1 (STAT)
unnamed: C5.1, J1.1 (In), L1.2
unnamed: U1.3 (P0.28_A2_D2), U2.3 (TIMEPULSE)
unnamed: C6.2, R4.2, U1.14 (VBUS), U4.4 (V_{DD})
unnamed: C5.2, U2.11 (RF_IN)
unnamed: C2.1, C3.2, C4.1, R1.2, R2.2, R5.2, U2.22 (V_BCKP), U2.23 (VCC), U3.5 (VOUT)
unnamed: L1.1, U2.9 (VCC_RF)
unnamed: R5.1, U2.8 (~RESET)
unnamed: R3.1, U4.5 (PROG)

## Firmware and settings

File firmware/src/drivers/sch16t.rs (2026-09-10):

//! SCH16T-K01 acquisition with bounded startup and validated interval samples.
//!
//! Register values, frame layout and startup sequence: Murata Doc. 11624 Rev. 6,
//! `data/datasheets/sch16t-k01-datasheet-full.pdf`, sections 5–7. The sensor
//! applies its factory calibration internally. No assembled-board calibration
//! or boresight calibration is claimed by this driver.

use embassy_time::{Duration, Instant, Timer, with_timeout};
use esp_hal::{
    Blocking,
    delay::Delay,
    gpio::{Input, Output},
    spi::master::Spi,
};

const FREQ_CNTR: u8 = 0x13;
const COMP_ID: u8 = 0x3c;
const CTRL_MODE: u8 = 0x35;
const SYS_TEST: u8 = 0x37;
const BATCH_SIZE: usize = 4;

// LPF3 Bessel, DYN1, DEC5 on every decimated axis. Native ODR is F_PRIM/32,
// nominally 737.5 Hz (690.625–784.375 Hz over the oscillator range).
// All native sets are read; four consecutive sets form one ~184 Hz interval
// average. This driver does not perform high-rate coning/sculling compensation.
const PROFILE: &[(u8, u16)] = &[
    (0x25, 0x00db),
    (0x26, 0x00db),
    (0x27, 0x00db),
    (0x28, 0x1324),
    (0x29, 0x1324),
    (0x2a, 0x0000),
    (0x2b, 0x0000),
    (0x2c, 0x0000),
    (0x2d, 0x0000),
    (0x2e, 0x0000),
    (0x33, 0x202c), // 3.3 V, normal slew rate, active-high data-ready.
    (0x34, 0x0ffe), // Keep continuous and startup self-tests enabled.
];

use aevia_firmware::imu::*;

struct NativeSample {
    rates: [i32; 3],
    accelerations: [i32; 3],
    counters: [u8; 6],
}

pub struct Imu<'d> {
    spi: Spi<'d, Blocking>,
    chip_select: Output<'d>,
    reset_n: Output<'d>,
    data_ready: Input<'d>,
    pending_address: Option<u8>,
    strict_status: bool,
    last_status_frame: u64,
    last_counter: Option<[u8; 6]>,
    last_time_us: Option<u64>,
    pub last_sample_error: Option<ImuError>,
    pub component_id: u16,
    pub asic_id: u16,
}

impl<'d> Imu<'d> {
    /// SPI must be mode 0, MSB first, at no more than 10 MHz. CS is controlled
    /// here, independently of the SPI peripheral's hardware CS output.
    pub fn new(
        spi: Spi<'d, Blocking>,
        chip_select: Output<'d>,
        reset_n: Output<'d>,
        data_ready: Input<'d>,
    ) -> Self {
        Self {
            spi,
            chip_select,
            reset_n,
            data_ready,
            pending_address: None,
            strict_status: false,
            last_status_frame: 0,
            last_counter: None,
            last_time_us: None,
            last_sample_error: None,
            component_id: 0,
            asic_id: 0,
        }
    }

    pub async fn initialize(&mut self) -> Result<(), ImuError> {
        let mut last_error = ImuError::DataReadyTimeout;
        for _ in 0..5 {
            match self.initialize_once().await {
                Ok(()) => return Ok(()),
                Err(error) => last_error = error,
            }
        }
        Err(last_error)
    }

    async fn initialize_once(&mut self) -> Result<(), ImuError> {
        self.strict_status = false;
        self.last_status_frame = 0;
        self.pending_address = None;
        self.last_counter = None;
        self.last_time_us = None;
        self.chip_select.set_high();
        self.reset_n.set_low();
        Timer::after_millis(2).await;
        self.reset_n.set_high();
        // Mode 0 holds SCK low for the complete NVM/SPI startup interval.
        Timer::after_millis(32).await;

        self.component_id = self.read_register(COMP_ID)?;
        if self.component_id != 0x0023 {
            return Err(ImuError::Identity(self.component_id));
        }
        self.asic_id = self.read_register(0x3b)?;
        if self.asic_id & 0x0f00 != 0 {
            return Err(ImuError::Identity(self.asic_id));
        }
        self.write_register(SYS_TEST, 0x5a3c)?;
        self.verify_register(SYS_TEST, 0x5a3c)?;
        self.write_register(SYS_TEST, 0)?;
        self.verify_register(SYS_TEST, 0)?;
        for &(address, value) in PROFILE {
            self.write_register(address, value)?;
        }
        // Prove the control image before EOI freezes configuration and the DSP
        // integrity monitor takes ownership of it.
        for &(address, value) in PROFILE {
            self.verify_register(address, value)?;
        }
        self.write_register(CTRL_MODE, 1)?;
        self.verify_register(CTRL_MODE, 1)?;
        Timer::after_millis(215).await;

        // These first status reads clear intentionally latched startup flags.
        let before = self.read_status()?;
        self.write_register(CTRL_MODE, 3)?;
        self.verify_register(CTRL_MODE, 3)?;
        Timer::after_millis(3).await;
        // Retire the FREQ_CNTR reply requested before the clearing delay; its
        // status belongs to that earlier request, not the post-delay state.
        self.exchange(FREQ_CNTR, None)?;
        let mut healthy_passes = 0;
        let mut last_fault = None;
        for _ in 0..10 {
            self.last_status_frame = 0;
            let registers = self.read_status()?;
            // Read the complete diagnostic set before rejecting it. Aborting
            // on the pending FREQ_CNTR response hides the actual fault bits.
            // Acquisition still requires two wholly healthy status passes.
            if registers != [0xffff; 10] || self.last_status_frame != 0 {
                healthy_passes = 0;
                last_fault = Some(ImuError::StartupStatus {
                    before_common: before[2],
                    registers,
                    frame: self.last_status_frame,
                    asic: self.asic_id,
                });
            } else {
                healthy_passes += 1;
                if healthy_passes == 2 {
                    break;
                }
            }
            // Reading STAT_COM acknowledges the mode-transition/DSP flags,
            // but their FTREE_TDEL clearing is asynchronous (nominal 2.5 ms).
            // Do not immediately re-read the same latched fault or reset
            // before the second diagnostic pass can observe its clearance.
            Timer::after_millis(3).await;
            self.exchange(FREQ_CNTR, None)?;
        }
        if healthy_passes != 2 {
            return Err(last_fault.unwrap_or(ImuError::DataReadyTimeout));
        }
        self.strict_status = true;
        for &(address, value) in PROFILE {
            self.verify_register(address, value)?;
        }
        self.verify_register(CTRL_MODE, 3)?;
        self.verify_register(COMP_ID, 0x0023)?;
        Ok(())
    }

    fn read_status(&mut self) -> Result<[u16; 10], ImuError> {
        // All bits, including reserved bits, are one for healthy registers
        // STAT_SUM through STAT_ACC_Z (tables 38–51).
        let mut registers = [0; 10];
        for (offset, value) in registers.iter_mut().enumerate() {
            *value = self.read_register(0x14 + offset as u8)?;
        }
        Ok(registers)
    }
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

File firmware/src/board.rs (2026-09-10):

//! Frozen V2 Mini wiring and bus configuration. This is the only GPIO assignment site.
use esp_hal::{
    Async,
    clock::CpuClock,
    gpio::{DriveMode, Input, InputConfig, Level, Output, OutputConfig, Pull},
    i2c::master::{BusTimeout, Config as I2cConfig, I2c, SoftwareTimeout},
    peripherals::{CPU_CTRL, FROM_CPU_INTR0, FROM_CPU_INTR1, PSRAM, TIMG0, USB_HS},
    spi::{
        Mode,
        master::{Config as SpiConfig, Spi},
    },
    time::Rate,
    uart::{Config as UartConfig, RxConfig, Uart},
};

pub struct Board {
    pub power_bus: I2c<'static, Async>,
    pub led_enable: Output<'static>,
    pub charger_power_good_n: Input<'static>,
    pub power_interrupt_n: Input<'static>,
    pub power_kill_n: Output<'static>,
    pub gnss_command: Uart<'static, Async>,
    pub gnss_data: Uart<'static, Async>,
    pub gnss_reset_n: Input<'static>,
    pub imu: crate::drivers::sch16t::Imu<'static>,
    pub lcd: crate::drivers::st7789::Lcd,
    pub lcd_te: Input<'static>,
    pub lcd_sclk_probe: u32,
    pub backlight: Output<'static>,
    pub usb: USB_HS<'static>,
    pub psram: PSRAM<'static>,
    pub cpu: CPU_CTRL<'static>,
    pub timer: TIMG0<'static>,
    pub core0_interrupt: FROM_CPU_INTR0<'static>,
    pub core1_interrupt: FROM_CPU_INTR1<'static>,
}

pub fn initialize() -> Board {
    let mut peripherals = esp_hal::init(esp_hal::Config::default().with_cpu_clock(CpuClock::max()));
    let power_kill_n = Output::new(
        peripherals.GPIO8,
        Level::High,
        OutputConfig::default()
            .with_drive_mode(DriveMode::OpenDrain)
            .with_pull(Pull::Up),
    );
    let power_interrupt_n = Input::new(
        peripherals.GPIO38,
        InputConfig::default().with_pull(Pull::Up),
    );
    let led_enable = Output::new(peripherals.GPIO39, Level::Low, OutputConfig::default());
    let charger_power_good_n = Input::new(
        peripherals.GPIO40,
        InputConfig::default().with_pull(Pull::Up),
    );
    let lcd_sclk_probe = crate::drivers::st7789::check_sclk(peripherals.GPIO16.reborrow());
    let lcd_spi = Spi::new(
        peripherals.SPI3,
        SpiConfig::default()
            .with_frequency(Rate::from_mhz(1))
            .with_mode(Mode::_0),
    )
    .expect("LCD SPI")
    .with_sio0(peripherals.GPIO17);
    let lcd_spi = if lcd_sclk_probe == 26 {
        lcd_spi.with_sck(peripherals.GPIO16)
    } else {
        lcd_spi
    };
    let lcd = crate::drivers::st7789::Lcd::new(
        lcd_spi,
        Output::new(peripherals.GPIO18, Level::High, OutputConfig::default()),
        Output::new(peripherals.GPIO19, Level::Low, OutputConfig::default()),
        Output::new(peripherals.GPIO15, Level::High, OutputConfig::default()),
    );
    let lcd_te = Input::new(
        peripherals.GPIO5,
        InputConfig::default().with_pull(Pull::Down),
    );
    let gnss_reset_n = Input::new(
        peripherals.GPIO44,
        InputConfig::default().with_pull(Pull::Up),
    );
    let power_i2c = I2c::new(
        peripherals.I2C0,
        I2cConfig::default()
            .with_frequency(Rate::from_khz(100))
            .with_timeout(BusTimeout::BusCycles(100))
            .with_software_timeout(SoftwareTimeout::Transaction(
                esp_hal::time::Duration::from_millis(10),
            )),
    )
    .expect("power I2C")
    .with_scl(peripherals.GPIO6)
    .with_sda(peripherals.GPIO7)
    .into_async();

    // Schematic pin assignment. See docs/gnss-usb-bridge.md for the assembled
    // board's unresolved COM1 RX / COM2 TX connectivity findings.
    let gnss_command_uart = Uart::new(
        peripherals.UART1,
        UartConfig::default()
            .with_baudrate(115_200)
            .with_rx(RxConfig::default().with_fifo_full_threshold(1)),
    )
    .expect("GNSS COM1 UART")
    .with_tx(peripherals.GPIO47)
    .with_rx(peripherals.GPIO46)
    .into_async();
    let gnss_data_uart = Uart::new(
        peripherals.UART2,
        UartConfig::default()
            .with_baudrate(115_200)
            .with_rx(RxConfig::default().with_fifo_full_threshold(64)),
    )
    .expect("GNSS COM2 UART")
    .with_tx(peripherals.GPIO49)
    .with_rx(peripherals.GPIO48)
    .into_async();

    let spi = Spi::new(
        peripherals.SPI2,
        SpiConfig::default()
            .with_frequency(Rate::from_mhz(1))
            .with_mode(Mode::_0),
    )
    .expect("IMU SPI")
    .with_sck(peripherals.GPIO12)
    .with_miso(peripherals.GPIO13)
    .with_mosi(peripherals.GPIO11);
    let sensor = crate::drivers::sch16t::Imu::new(
        spi,
        Output::new(peripherals.GPIO10, Level::High, OutputConfig::default()),
        Output::new(peripherals.GPIO9, Level::High, OutputConfig::default()),
        Input::new(peripherals.GPIO14, InputConfig::default()),
    );

    Board {
        power_bus: power_i2c,
        led_enable,
        charger_power_good_n,
        power_interrupt_n,
        power_kill_n,
        gnss_command: gnss_command_uart,
        gnss_data: gnss_data_uart,
        gnss_reset_n,
        imu: sensor,
        lcd,
        lcd_te,
        lcd_sclk_probe,
        backlight: Output::new(peripherals.GPIO4, Level::Low, OutputConfig::default()),
        usb: peripherals.USB_HS,
        psram: peripherals.PSRAM,
        cpu: peripherals.CPU_CTRL,
        timer: peripherals.TIMG0,
        core0_interrupt: peripherals.FROM_CPU_INTR0,
        core1_interrupt: peripherals.FROM_CPU_INTR1,
    }
}

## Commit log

2026-04-04 add pcb base
    [pcb.kicad_pcb, pcb.kicad_sch]
2026-04-05 first version pcb done
    [pcb-B_Cu.gbr, pcb-B_Mask.gbr, pcb-B_Paste.gbr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]
2026-04-05 added schematics and auto build
    [BOM-pcb.csv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]
2026-04-05 pcb printed
    [pcb-CuBottom.gbr, pcb-CuIn1.gbr, pcb-CuIn2.gbr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]
2026-04-07 recover schematics
    [pcb.kicad_pcb, pcb.kicad_sch]
2026-04-18 Update pcb from remove safeboot pull up
    [pcb.kicad_pcb, pcb.kicad_sch]
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2026-04-27 add auto reboot like arduino
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2026-05-21 start on power schematic
    [BOM-pcb.csv, open-race_v2.kicad_pcb, open-race_v2.kicad_sch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]
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2026-06-03 start pcb v2
    [HexaSPI_PSRAM.kicad_sch, STM32_MCU_IO.kicad_sch, open-race_v2.kicad_sch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]
2026-06-03 add io pinouts
    [HexaSPI_PSRAM.kicad_sch, STM32_MCU_IO.kicad_sch]
2026-06-03 add ram
    [HexaSPI_PSRAM.kicad_sch, STM32_MCU_IO.kicad_sch, stm32power.kicad_sch]
2026-06-06 contineu pcb
    [HexaSPI_PSRAM.kicad_sch, OctoSPI_FLASH.kicad_sch, open-race_v2.kicad_sch]
2026-06-06 fix powertree
2026-06-13 add debug to pcb
    [Debug.kicad_sch, OctoSPI_FLASH.kicad_sch, STM32_MCU_IO.kicad_sch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]
2026-06-14 add usb to schematic
    [Power.kicad_sch, STM32_MCU_IO.kicad_sch, USB.kicad_sch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]
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2026-06-21 finish battery charger
    [Power.kicad_sch, USB.kicad_sch]
2026-06-21 start on battery safety
    [Power.kicad_sch]
2026-07-08 fnish micro sd card
    [MicroSD.kicad_sch, OctoSPI_FLASH.kicad_sch, Power.kicad_sch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]
2026-07-08 done with max17320
    [Debug.kicad_sch, OctoSPI_FLASH.kicad_sch, Power.kicad_sch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]
2026-07-20 working on
    [Power.kicad_sch, STM32_MCU_IO.kicad_sch]
2026-07-20 add rpls for 1v8, 5v
    [Debug.kicad_sch, HexaSPI_PSRAM.kicad_sch, MicroSD.kicad_sch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]
2026-07-20 add tpsm buck stage
    [Power.kicad_sch]
2026-07-20 run load switch
    [Power.kicad_sch, STM32_MCU_IO.kicad_sch, open-race_v2.kicad_sch]
2026-07-20 pcb done
    [Debug.kicad_sch, GNSS.kicad_sch, HMI.kicad_sch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]
2026-07-21 switch mosfets
    [Debug.kicad_sch, GNSS.kicad_sch, HMI.kicad_sch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]
2026-07-21 power and debug cleanup
    [Debug.kicad_sch, GNSS.kicad_sch, HMI.kicad_sch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]
2026-07-21 clean debug and gnss
    [Debug.kicad_sch, GNSS.kicad_sch]
2026-07-21 clean pcb
    [GNSS.kicad_sch, IMU.kicad_sch, MicroSD.kicad_sch]
2026-07-22 fix minor
    [GNSS.kicad_sch, OctoSPI_FLASH.kicad_sch, Power.kicad_sch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]
2026-07-23 minor fixes
    [Debug.kicad_sch, GNSS.kicad_sch, HMI.kicad_sch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]
2026-07-23 pcb flash
    [OctoSPI_FLASH.kicad_sch, open-race_v2.kicad_pcb]
2026-07-24 remove resistors on flash line
    [STM32_MCU_IO.kicad_sch, open-race_v2.kicad_pcb]
2026-07-25 lsdfj" "s df l
    [open-race_v2.kicad_pcb]
2026-07-26 finish ram fanout
    [HexaSPI_PSRAM.kicad_sch, open-race_v2.kicad_pcb]
2026-07-26 fix trace width for impedence
    [open-race_v2.kicad_pcb]
2026-07-26 fix top impedence
    [open-race_v2.kicad_pcb]
2026-07-26 add ground plane
    [open-race_v2.kicad_pcb]
2026-07-28 gnss list
    [GNSS_research.xlsx]
2026-08-02 swithc 3to 3 layer signal for ram
    [STM32_MCU_IO.kicad_sch, open-race_v2.kicad_pcb, stm32power.kicad_sch]
2026-08-02 mini imu done
    [IMU_Mini.kicad_sch]
2026-08-02 mini power done
    [Power_USB.kicad_sch]
2026-08-02 gnss done
    [GNSS_Mini.kicad_sch]
2026-08-02 display storage done
    [Storage_Display.kicad_sch]
2026-08-02 finish v2_mini schematic
    [IMU_Mini.kicad_sch, MCU.kicad_sch, Storage_Display.kicad_sch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]
2026-08-02 fix minor edc rules
    [GNSS_Mini.kicad_sch, IMU_Mini.kicad_sch, MCU.kicad_sch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]
2026-08-02 erc rules
    [GNSS_Mini.kicad_sch, IMU_Mini.kicad_sch, MCU.kicad_sch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]
2026-08-02 add global labels?
    [IMU_Mini.kicad_sch, Power_USB.kicad_sch]
2026-08-03 update pcb issues
    [GNSS_Mini.kicad_sch, IMU_Mini.kicad_sch, MCU.kicad_sch]
2026-08-03 ground to imu pins
    [IMU_Mini.kicad_sch, MCU.kicad_sch]
2026-08-04 not sure
    [Power_USB.kicad_sch]
2026-08-04 add mpn and footprints for some
    [GNSS_Mini.kicad_sch, IMU_Mini.kicad_sch, MCU.kicad_sch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]
2026-08-05 finish off mpn and footprints
    [GNSS_Mini.kicad_sch, IMU_Mini.kicad_sch, MCU.kicad_sch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]
2026-08-05 finish footprint matching
    [GNSS_Mini.kicad_sch, IMU_Mini.kicad_sch, MCU.kicad_sch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]
2026-08-06 add input buttons
    [MCU.kicad_sch, hid.kicad_sch]
2026-08-06 fix input buttons
    [hid.kicad_sch]
2026-08-07 finish gnss part of pcb
    [hid.kicad_sch, v2_mini.kicad_pcb]
2026-08-07 edit gnss pcb
    [v2_mini.kicad_pcb]
2026-08-07 vbus connection
    [MCU.kicad_sch, Power_USB.kicad_sch, v2_mini.kicad_pcb]
2026-08-08 pcb power done
    [v2_mini.kicad_pcb]
2026-08-08 move gnss closer
    [v2_mini.kicad_pcb]
2026-08-08 done with lcd pcb
    [Storage_Display.kicad_sch, v2_mini.kicad_pcb]
2026-08-08 imu done
    [v2_mini.kicad_pcb]
2026-08-08 imu power
    [v2_mini.kicad_pcb]
2026-08-08 sd done
    [v2_mini.kicad_pcb]
2026-08-08 mcu routing done
    [v2_mini.kicad_pcb]
2026-08-08 switches done
    [v2_mini.kicad_pcb]
2026-08-08 finish led layout
    [v2_mini.kicad_pcb]
2026-08-08 nice outline cut
    [v2_mini.kicad_pcb]
2026-08-08 fix last erc errors
    [MCU.kicad_sch, Power_USB.kicad_sch, v2_mini.kicad_pcb]
2026-08-08 move jtag
    [MCU.kicad_sch, v2_mini.kicad_pcb]
2026-08-09 fix drc problems nad d+d- and sd
    [GNSS_Mini.kicad_sch, MCU.kicad_sch, Power_USB.kicad_sch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]
2026-08-09 update footprints
    [GNSS_Mini.kicad_sch, v2_mini.kicad_pcb]
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2026-08-09 add power off schematic
    [MCU.kicad_sch, Power_USB.kicad_sch, v2_mini.kicad_pcb]
2026-08-09 add power button to pcb
    [v2_mini.kicad_pcb]
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2026-08-10 add more vias for battery
    [v2_mini.kicad_pcb]
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2026-08-11 update bom on pcba nd file
    [digikey_bom.csv, v2_mini.kicad_pcb]
2026-08-11 turn off edge plating
    [v2_mini.kicad_pcb]
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2026-08-12 initialise flutter and core soft/firm folders
    [BOM-pcb.csv, Debug.kicad_sch, GNSS.kicad_sch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]
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2026-08-13 fix impedence sheet
    [Required_impedance_control.xlsx]
